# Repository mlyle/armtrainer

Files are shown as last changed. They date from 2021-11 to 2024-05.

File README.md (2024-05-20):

# ARM Trainer

This is a minimal monitor and and hardware stack for a small microcontroller trainer board, that was used to teach a Computer Organization class to students from ages 11-14.

Microprocessor trainers were a commonplace tool used to learn computing in the 1970s and early 1980s.  They replicated the console found on minicomputers, and allowed engineers to gain experience writing programs in machine code.

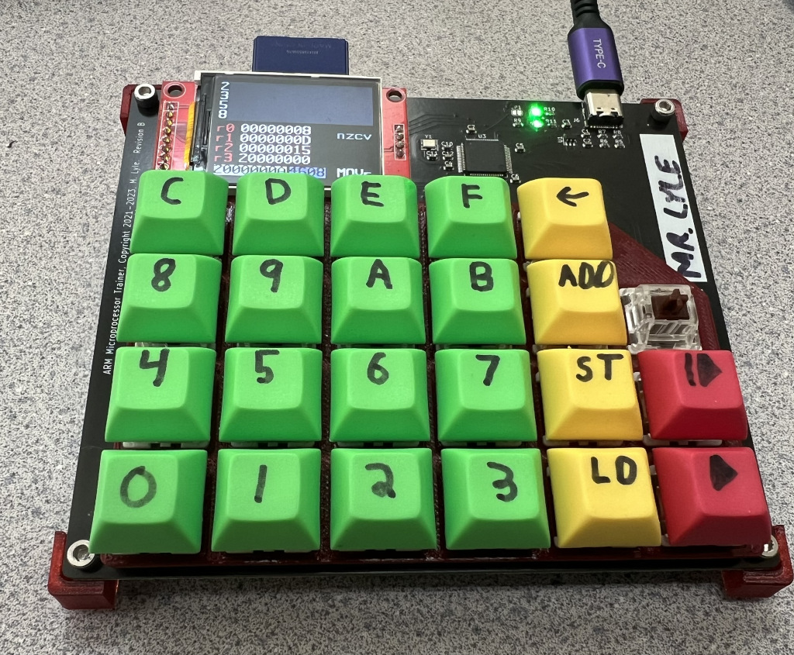
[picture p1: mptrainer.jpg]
Microprocessor Trainer


The Computer Organization class that I taught was a "how computers work" class with minimal use of conventional computers in the classroom.  We focused initially on gates, building from there to understand simple combinatorial and sequential circuits, and eventually ALUs, register files, and microprocessor subsystems.  This culminated in a study of ARM-Thumb machine code.

ARM-Thumb machine code was a fairly ideal architecture for students to learn, because:

* It is a real architecture, in real use.
* It has a reasonable number of general purpose registers.
* A fixed-length, relatively simple encoding avoids unnecessary complexity.

## Example Program

By a student, Robin K:

    20000000	DF20		(clear screen)
    20000002	2001		(mov r0, #1)
    20000004	2102		(mov r1, #1)
    20000006	180A		(add r2, r0, r1)
    20000008	DF21		(print contents of register 0)
    2000000A	4608		(mov r0, r1)
    2000000C	4611		(mov r1, r2)
    2000000E	E7FA		(b 20000006)

## TODO

* Students have complained that some invalid instructions-- BBAD, EF78-- seem to lock up the machine monitor.  I think I removed some safeguard code that I didn't think was necessary, but I need to inspect that again.
* Input calls do not allow the user to enter the number "0".
* The manual should be updated with some of the system calls that have not been documented
  * Branch calculation formulae are wrong in the manual.
  * In particular, the input calls.
  * There may be a typo in the subtract register instruction.
  * The display icon and screen coordinate system could be more clearly explained
  * Need to update manual for new key shortcuts
* Overall curriculum, etc, should get posted here.

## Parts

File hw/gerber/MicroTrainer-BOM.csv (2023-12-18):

Comment | Designator | Footprint | LCSC
2.2uF | C1,C3,C8,C9 | Capacitor_SMD:C_0603_1608Metric | C23630
12pF | C10,C11 | Capacitor_SMD:C_0603_1608Metric | C38523
0.1uF | C2,C4,C5,C6,C7,C12 | Capacitor_SMD:C_0603_1608Metric | C14663
LED | D1,D2 | LED_SMD:LED_0805_2012Metric | C2297
Fiducial | FID1,FID2,FID3 | Fiducial:Fiducial_1mm_Mask2mm
MountingHole | H1,H2,H3,H4,H5,H6,H7,H8 | MountingHole:MountingHole_3.2mm_M3
Conn_01x04 | J4 | Connector_PinSocket_2.54mm:PinSocket_1x04_P2.54mm_Vertical
Conn_01x08 | J5 | Connector_PinSocket_2.54mm:PinSocket_1x08_P2.54mm_Vertical
USB_C_Receptacle_USB2.0 | J6 | Connector_USB:USB_C_Receptacle_G-Switch_GT-USB-7010ASV | C2988369
BootJumper | JP1 | Jumper:SolderJumper-2_P1.3mm_Open_RoundedPad1.0x1.5mm
5.1k | R1,R2,R3,R4,R5,R6,R9,R12 | Resistor_SMD:R_0603_1608Metric | C23186
330 | R10,R11 | Resistor_SMD:R_0603_1608Metric | C23138
10 | R7,R8 | Resistor_SMD:R_0603_1608Metric | C22859
KEY_C | SW1 | Button_Switch_Keyboard:SW_Cherry_MX_1.00u_PCB
KEY_B | SW10 | Button_Switch_Keyboard:SW_Cherry_MX_1.00u_PCB
KEY_ADDR | SW11 | Button_Switch_Keyboard:SW_Cherry_MX_1.00u_PCB
KEY_4 | SW13 | Button_Switch_Keyboard:SW_Cherry_MX_1.00u_PCB
KEY_5 | SW14 | Button_Switch_Keyboard:SW_Cherry_MX_1.00u_PCB
KEY_6 | SW15 | Button_Switch_Keyboard:SW_Cherry_MX_1.00u_PCB
KEY_7 | SW16 | Button_Switch_Keyboard:SW_Cherry_MX_1.00u_PCB
KEY_STOR | SW17 | Button_Switch_Keyboard:SW_Cherry_MX_1.00u_PCB
KEY_STEP | SW18 | Button_Switch_Keyboard:SW_Cherry_MX_1.00u_PCB
KEY_0 | SW19 | Button_Switch_Keyboard:SW_Cherry_MX_1.00u_PCB
KEY_D | SW2 | Button_Switch_Keyboard:SW_Cherry_MX_1.00u_PCB
KEY_1 | SW20 | Button_Switch_Keyboard:SW_Cherry_MX_1.00u_PCB
KEY_2 | SW21 | Button_Switch_Keyboard:SW_Cherry_MX_1.00u_PCB
KEY_3 | SW22 | Button_Switch_Keyboard:SW_Cherry_MX_1.00u_PCB
KEY_LOAD | SW23 | Button_Switch_Keyboard:SW_Cherry_MX_1.00u_PCB
KEY_RUN | SW24 | Button_Switch_Keyboard:SW_Cherry_MX_1.00u_PCB
KEY_RST | SW25 | Button_Switch_Keyboard:SW_Cherry_MX_1.00u_PCB
KEY_E | SW3 | Button_Switch_Keyboard:SW_Cherry_MX_1.00u_PCB
KEY_F | SW4 | Button_Switch_Keyboard:SW_Cherry_MX_1.00u_PCB
KEY_CLR | SW5 | Button_Switch_Keyboard:SW_Cherry_MX_1.00u_PCB
KEY_8 | SW7 | Button_Switch_Keyboard:SW_Cherry_MX_1.00u_PCB
KEY_9 | SW8 | Button_Switch_Keyboard:SW_Cherry_MX_1.00u_PCB
KEY_A | SW9 | Button_Switch_Keyboard:SW_Cherry_MX_1.00u_PCB
LP5907MFX-3.3 | U1 | Package_TO_SOT_SMD:SOT-23-5 | C80670
STM32F412RETx | U3 | Package_QFP:LQFP-64_10x10mm_P0.5mm | C89374
25MHz | Y1 | Crystal:Crystal_SMD_3225-4Pin_3.2x2.5mm | C9006

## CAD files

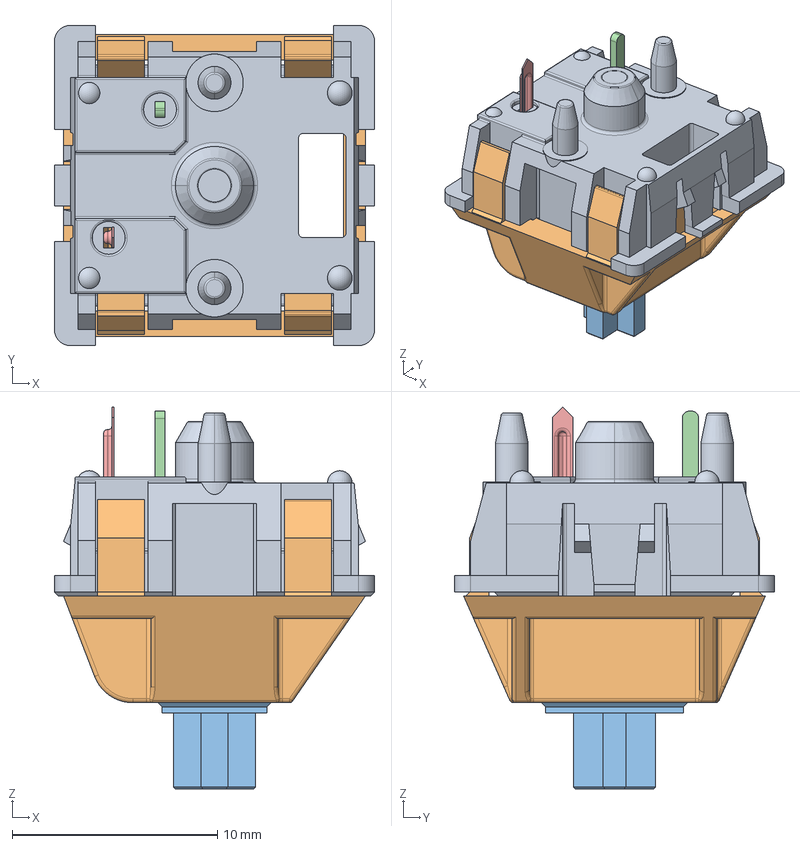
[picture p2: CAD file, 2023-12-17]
hw/3d/asm_mx_asm_PCB.stp
15.6 x 15.6 x 18.6 mm
MX_DOWN
MX_UP
UP_MX
MX_PIN
MX_SPRING
MX_CLICK

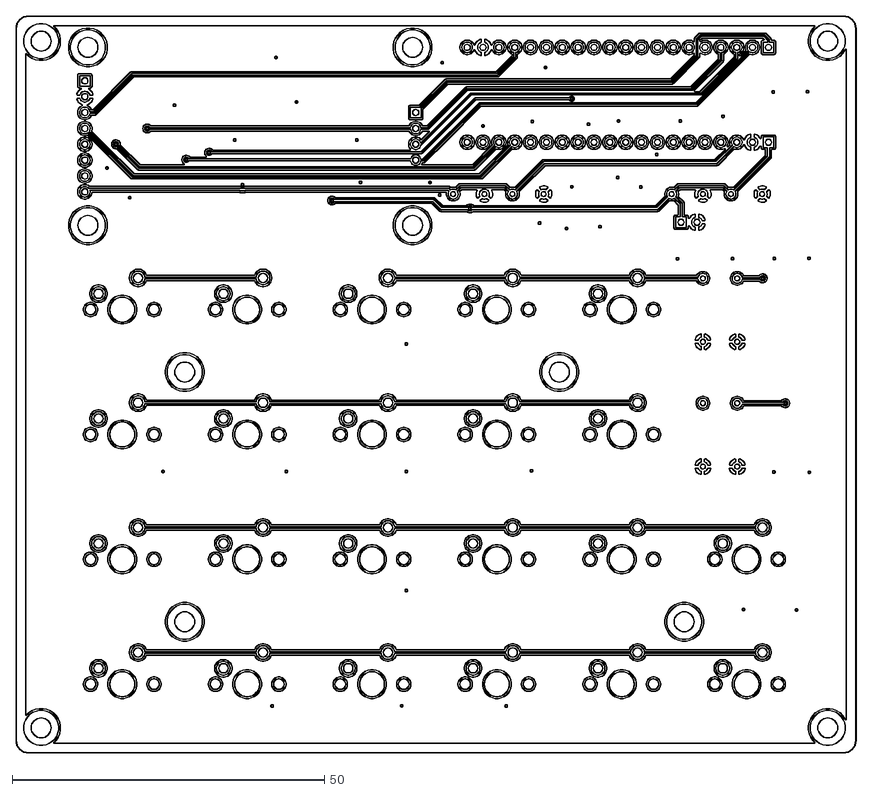
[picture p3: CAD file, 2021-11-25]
hw/microtrainer-gerbers/MicroTrainer-F_Cu.dxf
134.6 x 118.1

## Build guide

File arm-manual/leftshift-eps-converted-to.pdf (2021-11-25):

0 | 1 | 0 | 1 | 0

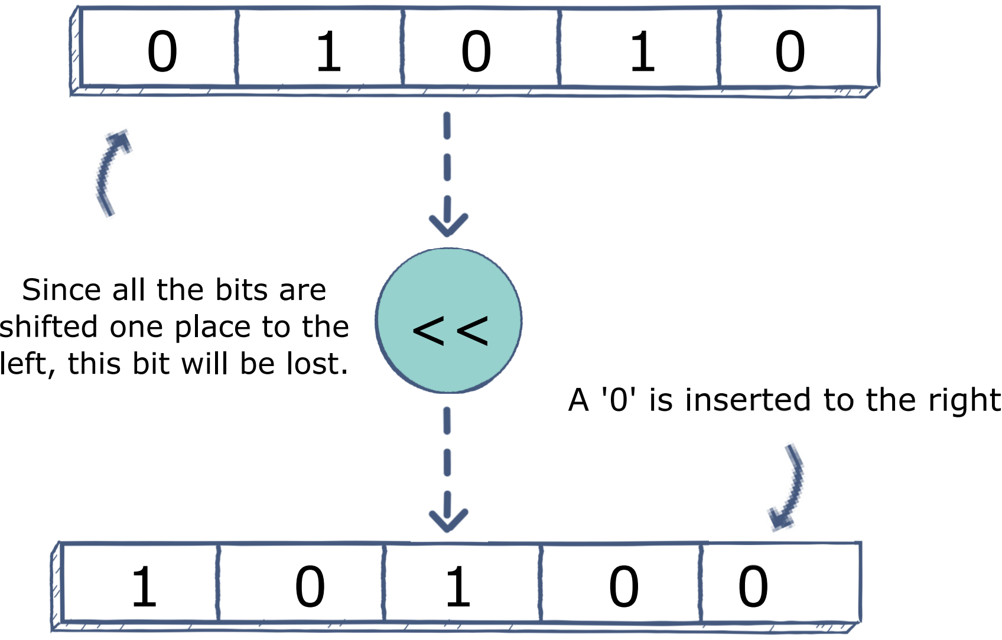
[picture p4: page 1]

<<

1 | 0 | 1 | 0 | 0

A '0' is inserted to the right

Since all the bits are
shifted one place to the
left, this bit will be lost.

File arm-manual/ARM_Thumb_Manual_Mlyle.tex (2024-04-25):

\documentclass[12pt]{article}
\usepackage[utf8]{inputenc}
\usepackage[hidelinks,linktoc=all]{hyperref}
\usepackage{graphicx}
\usepackage{tikz}
\usepackage{amsmath}

\title{ARM-Thumb Machine Code Reference}
\author{Michael Lyle}
\date{2024 Edition}

\ttfamily

\usepackage[
  letterpaper,
  twoside,
  bindingoffset=1.1cm,
  inner=1.9cm,
  outer=1.9cm,
  top=2cm,
  bottom=2cm,
  headsep=1.2cm
]{geometry}

\usepackage[final]{pdfpages}
\usepackage{graphicx}
\usepackage{imakeidx}
\makeindex

\newcommand{\fullrule}{\\[-4pt]\noindent\rule{\textwidth}{1pt}\\}

\newcommand{\instruction}[5]{\addcontentsline{toc}{subsection}{#1}\vspace{0.8cm}\noindent \textbf{#1}\index{#5}\hspace*{\fill}\texttt{#3}\fullrule#2\vspace{0.25cm}\begin{center}#4\end{center}}

\newcommand{\hexnum}[2]{$\mathtt{#1}_{16}$ ($\mathtt{#2}_{10}$)}
\newcommand{\numtt}[1]{$\mathtt{#1}$}
\newcommand{\reg}[1]{$r#1$}

\setlength{\parskip}{6pt}%
\setlength{\parindent}{0pt}

\begin{document}

\maketitle
{
\setlength{\parskip}{0pt}%
\tableofcontents
}
\vspace{3.2cm}
\begin{center}
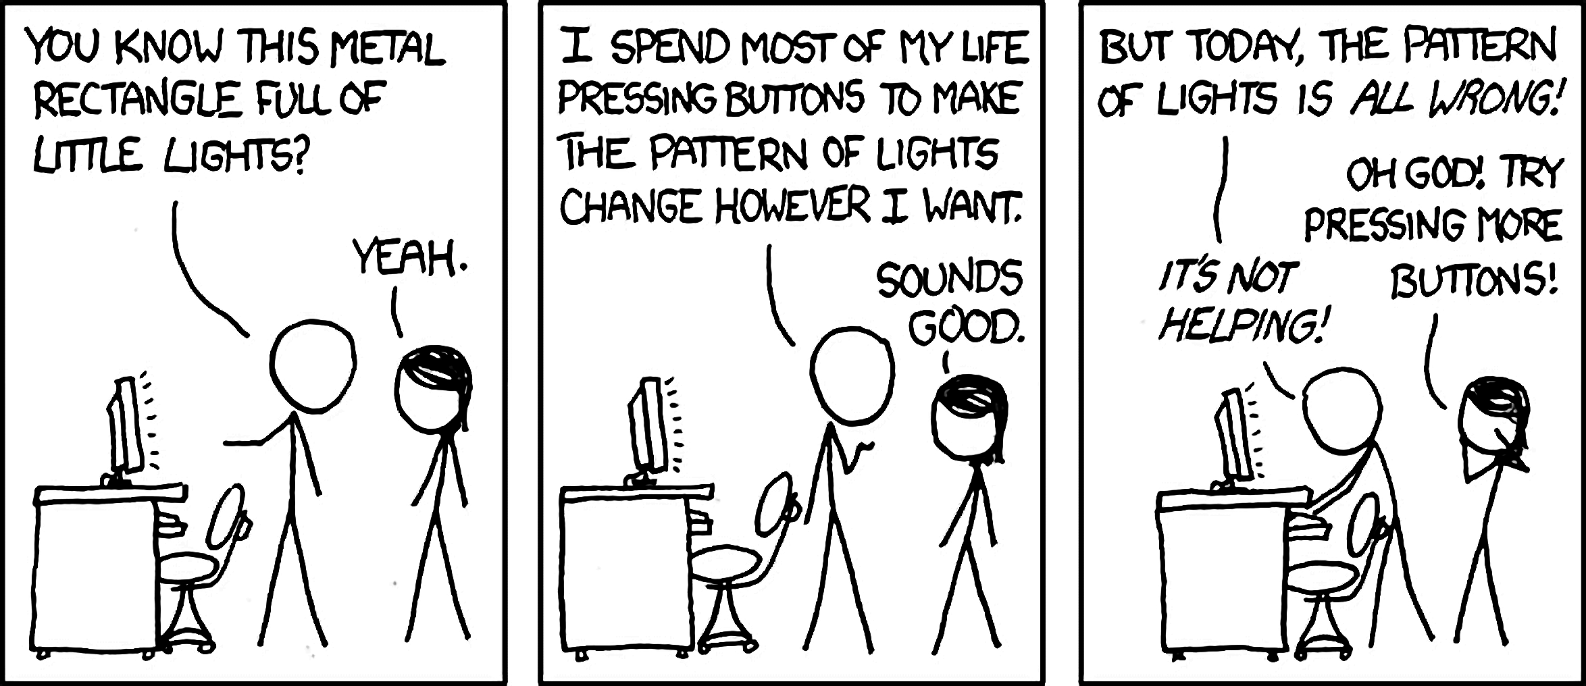
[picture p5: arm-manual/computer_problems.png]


\scriptsize{XKCD \#722, "Computer Problems" (by Randall Munroe)}
\end{center}

\newpage

\section{Architecture Summary}

In this course, we will be learning ARM Thumb machine language.

Specifically, we are writing code for the ARMv7 Thumb architecture.  Its characteristics are:

\begin{itemize}
    \item \index{registers}32-bit (4 byte) register (word) size
    \item 32-bit (4 byte) address size
    \item 16-bit (2 byte) instruction length
    \item \index{address}Addresses point to individual bytes.  Instructions and words should be aligned in memory.
    \begin{itemize}
        \item An address pointing aligned with the beginning of a word will end in $0$, $4$, $8$, or $C$ in base $16$.
        \item An address pointing to an instruction will end in $0$, $2$, $4$, $6$, $8$, $A$, $C$, or $E$ in base $16$.
    \end{itemize}
    \item Instructions can access memory, or perform arithmetic, but not both (RISC / load-store machine).
    \item Eight general-purpose registers are easily accessed (\reg{0}-\reg{7}).
    \item Five additional general-purpose registers are more difficult to access (\reg{8}-\reg{12})
    \item Three special purpose registers (stack pointer, link register, and program counter)
    \item Capable ALU with hardware multiplier and standard flags:
    \begin{itemize}
        \item N (negative),
        \item Z (zero),
        \item C (carry),
        \item and V (overflow)
    \end{itemize}
\end{itemize}

\subsection{Machine Language vs. Assembly Language}

In this course, we are writing programs in machine language.  This is a raw sequence of numbers that tells the computer what to do.

\index{assembly}
One step up from machine language is to use assembly language, where each line of code corresponds to a single machine instruction, which the assembler then translates into the binary format of machine language.  Assemblers make the process of programming slightly easier by handling the details of instruction encoding and calculating addresses for the programmer.

Most contemporary programmers work with high-level languages, such as \textit{C}, \textit{Java}, or \textit{Python}. These languages require conversion to machine code for execution. This is typically done through compilation, where the high-level code is translated into machine code, or through interpretation, where another program executes the high-level code step-by-step.

\newpage

\section{Using the ARM Microprocessor Trainer}

You will be receiving an Microprocessor Trainer in this course. Before home computers were readily available, this was one way that many people learned to program. The Trainer has a keypad where you can inspect and manipulate the contents of memory, as well as run your program.

Unlike earlier trainers, the system designed for this class uses a modern instruction set, \textbf{ARM-Thumb}, which is still actively used on microcontrollers. It is closely related to the \textbf{ARM} instruction set used in modern phones, tablets, and Apple computers.

\begin{figure}[h]
        
    \centering
    \caption{ARM Microprocessor Trainer, Revision B}
\end{figure}

If you've programmed before, this will be more cumbersome than you're used to! It's important to pre-plan your programs and think about what each instruction will do.

\subsection{Description of Keys}

\begin{itemize}
    \item \textbf{0-9, A-F}: Represent hexadecimal digits, which are used to enter numbers into the trainer.
    \item \textbf{CLR}: Functions as a backspace key, allowing you to correct any mistakes made during input.
    \item \textbf{ADDR}: Toggles the cursor between editing the memory address and the value at that address.
    \item \textbf{LOAD}: Loads the value located at the specified address into the display. Pressing this key repeatedly will advance the address sequentially, allowing you to view subsequent values.
    \item \textbf{STOR}: Saves the currently displayed value into the specified memory address, effectively writing data to memory. This will also advance the address.
    \item \textbf{STEP}: Executes the instruction at the current memory address and then automatically advances to the next address, facilitating step-by-step execution of your code.
    \item \textbf{RUN}: Starts a continuous execution of the program beginning at the current address. The execution will proceed without interruption until you press \textbf{STEP}.
\end{itemize}

\subsection{Screen Contents}
\index{screen}

The screen provides an overview of the current status of the microprocessor trainer.

\begin{figure}[h]
\begin{tikzpicture}
\newcommand*\circled[1]{\tikz[baseline=(char.base)]{
            \node[shape=circle,draw,inner sep=2pt] (char) {#1};}}
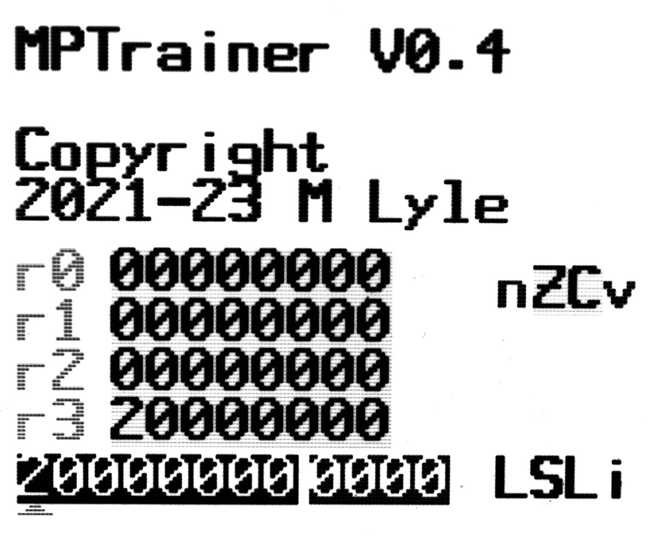
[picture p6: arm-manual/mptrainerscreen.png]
    \node[anchor=south west,inner sep=0] (image) at (0,0) {};
    \begin{scope}[
        x={(image.south east)},
        y={(image.north west)}
    ]

    \node[shape=circle,draw,fill=white,inner sep=2pt,line width=2pt] at (0.4,0.36) {\huge$1$};
    \node[shape=circle,draw,fill=white,inner sep=2pt,line width=2pt] at (0.2,0.15) {\huge$2$};
    \node[shape=circle,draw,fill=white,inner sep=2pt,line width=2pt] at (0.55,0.15) {\huge$3$};
    \node[shape=circle,draw,fill=white,inner sep=2pt,line width=2pt] at (0.75,0.38) {\huge$4$};
    \node[shape=circle,draw,fill=white,inner sep=2pt,line width=2pt] at (0.6,0.78) {\huge$5$};

    \end{scope}
\end{tikzpicture}
\centering
\caption{Screen Contents at Startup}
\end{figure}

Various types of information are displayed on the screen:

\begin{enumerate}
\item \index{registers}The values of registers are displayed centrally.
\item The current address is displayed on the left.  A red arrow indicates we are currently editing the first digit of the address.
\item The value (that may be loaded or stored) is displayed to the right of the address.
\item The current flags (produced by the ALU and used by conditional branches) are displayed on the right side of the screen.
\item At the top of the screen is where a program's input/output is displayed.
\end{enumerate}

\subsection{Entering Instructions}

Once you have written your program and translated it into hexadecimal format, you will need to enter these instructions into the Microprocessor Trainer. Follow these steps to input each instruction:

\begin{enumerate}
    \item Turn on the Microprocessor Trainer and locate the keypad.
    \item Begin by setting the starting address where your program will be stored. Enter \texttt{20000000} using the numeric keys (0-9, A-F).
    \item Press the \textbf{ADDR} key to switch the focus from entering an address to entering a value.
    \item Now, enter the first instruction from your program. Remember, each instruction should be a 4-digit hexadecimal number (consisting of the characters 0-9 and A-F).
    \item After typing the hexadecimal instruction, press the \textbf{STOR} key. This will store your instruction at the current address. The Trainer will automatically advance to the next memory address.
    \item Repeat steps 4 and 5 for each subsequent instruction in your program:
        \begin{itemize}
            \item Enter the next 4-digit hexadecimal instruction.
\index{memory!store}
            \item Press the \textbf{STOR} key to store the instruction and move to the next address.
        \end{itemize}
    \item Continue this process until you have entered all the instructions of your program.
\end{enumerate}

Make sure you enter each instruction correctly and in the proper order. If you make a mistake, you can always go back to any address by entering it and pressing \textbf{ADDR} to correct the value.

\textbf{Tip:} Always double-check each instruction after entering it to make sure it has been input correctly before hitting \textbf{STOR}. This will save you time troubleshooting later!

\paragraph{Predicting Outcomes Before Execution:}
Before running your program, take a moment to predict the expected results and behavior of your code. For example, think about what values you expect to see in registers, and when. By anticipating the values in registers and the effects of each instruction, you can better identify when things might go wrong and understand why.

\subsection{Running a Program}

Once you have successfully entered all of your program's instructions into the Microprocessor Trainer, the next step is to run your program to see how it works.

\paragraph{Setting the Starting Point:}
\index{address}
First, you need to set the Trainer to the beginning of your program. Ensure the address field is active by pressing \textbf{ADDR} if necessary. Using the keypad, enter the address \texttt{20000000}, which is where your program starts. Finally, press the \textbf{ADDR} key to confirm the start address.

\paragraph{Choosing the Mode of Execution:}
With the starting address set, you have two options for running your program:
\begin{itemize}
    \item \textbf{Step-by-Step Execution:} If you want to see how each instruction is executed one at a time, press the \textbf{STEP} key. This allows you to observe the changes and understand the flow of your program in detail. After pressing \textbf{STEP}, the Trainer executes the current instruction and then pauses, waiting for you to press \textbf{STEP} again for the next instruction.

    \item \textbf{Continuous Execution:} If you prefer to run your program continuously from the start to the end, press the \textbf{RUN} key. The Trainer will execute all the instructions continuously until the end of the program is reached, or until you press the \textbf{STEP} key to halt execution.
\end{itemize}

\paragraph{Monitoring and Troubleshooting:}
As your program runs, watch the display on the Trainer to see the outputs and any changes in the values stored in the memory. If the program does not behave as expected, you may need to stop the execution, review and correct the instructions you entered. Remember, debugging is a normal part of learning to program.
\paragraph{Tip:} Start with the step-by-step execution mode when you’re testing a new program. It gives you a better understanding of how each part of your program works and helps in identifying and fixing any errors.

\subsection{Inspecting Memory}

After you run your program, or even while it is running, you might want to check what is happening inside the memory of the Microprocessor Trainer. This process is called "inspecting memory," and it lets you see the values stored in different memory locations. Here’s how you can do it:

\paragraph{Access the Memory:}
To look at the contents of a specific memory address, you need to first stop your program if it is running. You can do this by pressing the \textbf{STEP} key to pause execution.

\paragraph{Choosing the Address:}
Use the \textbf{ADDR} key to select the address field. Enter the desired memory address using the numeric keys (0-9, A-F). Remember that your program starts at \texttt{20000000}, so any addresses from this point onward may contain data or instructions from your program.

\paragraph{Loading the Value from Memory:}
\index{memory!load}
Once you have entered the desired address, press the \textbf{LOAD} key. This will load the value at the address you entered, and switch the cursor to the value field.

\subsection{Function Keys}

The \textbf{LOAD} key on the Microprocessor Trainer is not just for loading the value at the current address. When held down and used in combination with other keys, it activates a variety of special functions. Here's how you can use these combinations effectively:

\begin{itemize}
    \item \textbf{Keys 0 - 2}: \index{registers}Display different sets of registers on the screen. Pressing \textbf{LOAD} + \textbf{0} will show registers \texttt{r0} to \texttt{r3}, which is the default display.
    \item \textbf{Keys 4 - 6}: \index{saving}Save the currently entered program into internal flash memory. Each key represents a different storage slot, allowing for multiple programs to be stored simultaneously.
    \item \textbf{Keys 8 - A}:  \index{loading} Load previously saved programs from the corresponding slots in the internal flash memory. This is useful for retrieving and running stored code without re-entering it.
    \item \textbf{Key D}: \index{decimal} Toggle the display mode of the registers between hexadecimal and decimal. This can be helpful for easier reading or specific debugging needs.
    \item \textbf{Key F}: Activate a fast run mode, which executes the program without updating the display between each instruction. This mode allows for quicker execution but is generally not recommended for debugging, as changes in registers and memory are not visible in real time.
\end{itemize}

\subsection{The Easter Egg}
\index{snake}In your explorations with the Microprocessor Trainer, there's a special feature hidden for you to discover. This hidden feature, often called an "Easter egg," can be activated under specific conditions.

\paragraph{Hint:}
If you manage to load the ASCII values for the characters 'S', 'N', 'A', and 'K' into registers \texttt{r0} through \texttt{r3} respectively, and then execute a Supervisor Call (SVC) instruction code $\texttt{45}_{16}$ (which stands for 'E' in ASCII), something unexpected will happen!

\paragraph{Discover on Your Own:}
You might want to figure out how to achieve this setup and see what happens for yourself. It’s a fun way to apply what you’ve learned about ASCII values, registers, and supervisor calls.

\newpage

\section{ARM-Thumb Basic Instructions}

The following are just a few of the many instructions in the ARM-Thumb instruction set.  There are enough instructions in this manual to be able to write any program.  In other words, this set of instructions are Turing-complete.  But other instructions, not listed here, are often necessary to write the shortest and fastest possible program.

\instruction{ADD (add immediate)}{Add an 8 bit value (included in the instruction) to a register.  Flags are updated based on the result value.}{0011 0ddd iiii iiii}{$r[d] = r[d] + i$}{add}\index{immediate instructions}
\begin{tabular}{p{0.15\textwidth} p{0.10\textwidth} p{0.63\textwidth}}
\texttt{ddd} & (3 bits) & This is the register number of the operand to add to, \underline{and} the destination register where the result should be placed. \\
\texttt{iiii iiii} & (8 bits) & This is the value that should be added, included as an immediate operand in the instruction. \\
\end {tabular}

\vspace{0.5cm}

Examples:

\begin{tabular}{p{0.33\textwidth} p{0.09\textwidth} p{0.44\textwidth}}
\texttt{0011 0ddd iiii iiii}&3???&Basic instruction encoding\\
\hline
\texttt{0011 0000 0000 0001}&3001&Adds the number \numtt{1} to \reg{0} \\
\hline
\texttt{0011 0011 0001 0010}&3312&Adds the number \hexnum{12}{18} to \reg{3} \\
\hline
\texttt{0011 0111 1010 0101}&37A5&Adds the number \hexnum{A5}{165} to \reg{7} \\
\hline

\end{tabular}

\instruction{ADD (add registers)}{Add two registers together, storing the result in a (optionally different) third register.  Flags are updated.}{0001 100m mmnn nddd}{$r[d] = r[m] + r[n]$}{add}

\begin{tabular}{p{0.15\textwidth} p{0.10\textwidth} p{0.63\textwidth}}
\texttt{mmm} & (3 bits) & This is the register number of the first operand to add. \\
\texttt{nnn} & (3 bits) & This is the register number of the second operand to add. \\
\texttt{ddd} & (3 bits) & This is the register number to store the result in. \\
\end {tabular}

\vspace{0.5cm}

Examples:

\begin{tabular}{p{0.33\textwidth} p{0.09\textwidth} p{0.44\textwidth}}
\texttt{0001 100m mmnn nddd}&1???&Basic instruction encoding\\
\hline
\texttt{0001 1000 0000 0000}&1800&Adds \reg{0} to register \reg{0} and stores the result in \reg{0} (doubles \reg{0})\\
\hline
\texttt{0001 1000 0101 0011}&1853&Adds \reg{1} to \reg{2} and stores the result in \reg{3} \\
\hline
\texttt{0001 1000 1000 1011}&188B&Adds \reg{2} to \reg{1} and stores the result in \reg{3} (same as above)\\
\hline
\end{tabular}

\newpage
\instruction{B (branch)}{Branches the program counter to a new location.  (Goto a different part of your program)}{1110 0iii iiii iiii}{$pc = pc + 2*(i+2)$}{branch}

\begin{tabular}{p{0.15\textwidth} p{0.10\textwidth} p{0.63\textwidth}}
\texttt{iiiiiiii...} & (11 bits) & Number of instructions to jump forward (or backwards, if negative...)\\
\end {tabular}

\vspace{0.5cm}

Examples:

\begin{tabular}{p{0.33\textwidth} p{0.09\textwidth} p{0.44\textwidth}}
\texttt{1110 0iii iiii iiii}&E???&Basic instruction encoding\\
\hline
\texttt{1110 0111 1111 0000}&E7F0&Goes back to 14 instructions before this one.\\
\hline
\texttt{1110 0111 1111 0001}&E7F1&Goes back to 13 instructions before this one.\\
\hline
\texttt{1110 0111 1111 0010}&E7F2&Goes back to 12 instructions before this one.\\
\hline
\texttt{1110 0111 1111 1100}&E7FC&Goes back to 2 instructions before this one.\\
\hline
\texttt{1110 0111 1111 1101}&E7FD&Goes back to 1 instructions before this one.\\
\hline
\texttt{1110 0111 1111 1110}&E7FE&Goes to \textbf{THIS} instruction (infinite loop)\\
\hline
\texttt{1110 0111 1111 1111}&E7FF&Goes to the instruction after this one (does nothing)\\
\hline
\texttt{1110 0000 0000 0000}&E000&Skips 1 instruction after this one\\
\hline
\texttt{1110 0000 0000 0001}&E001&Skips 2 instructions after this one\\
\hline
\texttt{1110 0000 0000 0010}&E002&Skips 3 instructions after this one\\
\hline
\texttt{1110 0000 0000 1111}&E00F&Skips 16 instructions after this one\\
\hline
\end{tabular}

\instruction{CMP (compare registers)}{Subtracts one register from another and updates flags.  The result of the subtraction is thrown away. }{0100 0010 10mm mnnn}{$tmp = r[n] - r[m]$}{compare}

\begin{tabular}{p{0.15\textwidth} p{0.10\textwidth} p{0.63\textwidth}}
\texttt{nnn} & (3 bits) & This is the register number of the operand to subtract from. \\
\texttt{mmm} & (3 bits) & This is the register number of the subtrahend \\
\end{tabular}
\vspace{0.5cm}

Examples:

\begin{tabular}{p{0.33\textwidth} p{0.09\textwidth} p{0.44\textwidth}}
\texttt{0100 0010 10mm mnnn}&42??&Basic instruction encoding\\
\hline
\texttt{0100 0010 1000 0001}&4281&Subtracts \reg{0} from register \reg{1} and updates flags \\
\hline
\texttt{0100 0010 1011 1110}&42BE&Subtracts \reg{7} from register \reg{6} and updates flags \\
\hline
\end{tabular}

\newpage
\instruction{MOV (move immediate)}{Moves a value, provided in the instruction, into a chosen register.}{0010 0ddd iiii iiii}{$r[d] = i$}{move}\index{immediate instructions}

\begin{tabular}{p{0.15\textwidth} p{0.10\textwidth} p{0.63\textwidth}}
\texttt{ddd} & (3 bits) & This is the register number where the result should be placed. \\
\texttt{iiii iiii} & (8 bits) & This is the value that should be placed into the destination register.  The high 24 bits of the register will be $0$ and the remaining 8 bits will be the immediate value. \\
\end {tabular}

\vspace{0.5cm}

Examples:

\begin{tabular}{p{0.33\textwidth} p{0.09\textwidth} p{0.44\textwidth}}
\texttt{0010 0ddd iiii iiii}&2???&Basic instruction encoding\\
\hline
\texttt{0010 0000 0000 0000}&2000&Sets \reg{0} to the value \numtt{0}\\
\hline
\texttt{0010 0111 1111 1111}&27FF&Sets \reg{7} to the value \hexnum{FF}{255} \\
\hline
\texttt{0010 0010 0000 0101}&2205&Puts the number \numtt{5} in \reg{2} \\
\hline

\end{tabular}

\instruction{MOV (move register)}{Copies a value from one register to another.}{0100 0110 00mm mddd}{$r[d] = r[m]$}{move}

\begin{tabular}{p{0.15\textwidth} p{0.10\textwidth} p{0.63\textwidth}}
\texttt{mmm} & (3 bits) & This is the register number from which the value should be copied. \\
\texttt{ddd} & (3 bits) & This is the register number where the value should be placed.
\end{tabular}
\vspace{0.5cm}

Examples:

\begin{tabular}{p{0.33\textwidth} p{0.09\textwidth} p{0.44\textwidth}}
\texttt{0100 0110 00mm mddd}&46??&Basic instruction encoding\\
\hline
\texttt{0100 0110 0000 1000}&4608&Sets \reg{0} to the value in \reg{1}\\
\hline
\texttt{0100 0110 0000 0001}&4601&Sets \reg{1} to the value in \reg{0}\\
\hline
\texttt{0100 0110 0011 1110}&463E&Sets \reg{6} to the value of \reg{7}\\
\hline
\end{tabular}

\newpage
\instruction{MUL (multiply registers)}{Multiplies register $n$ by register $d$, and stores the result in register $d$.}{0100 0011 01nn nddd}{$r[d] = r[d] * r[n]$}{multiply}

\begin{tabular}{p{0.15\textwidth} p{0.10\textwidth} p{0.63\textwidth}}
\texttt{nnn} & (3 bits) & This is the register number that contains the first number to be multiplied. \\
\texttt{ddd} & (3 bits) & This is the register number with the second multiplicand, and where the value should be placed.
\end{tabular}
\vspace{0.5cm}

Examples:

\begin{tabular}{p{0.33\textwidth} p{0.09\textwidth} p{0.44\textwidth}}
\texttt{0100 0011 01nn nddd}&43??&Basic instruction encoding\\
\hline
\texttt{0100 0011 0100 0000}&4340&Squares \reg{0} and puts the result back in \reg{0}\\
\hline
\texttt{0100 0011 0100 1000}&4348&Sets \reg{0} to \reg{1} times \reg{0}\\
\hline
\texttt{0100 0011 0100 0001}&4341&Sets \reg{1} to \reg{1} times \reg{0}\\
\hline
\texttt{0100 0011 0110 0011}&4363&Sets \reg{3} to \reg{3} times \reg{4}\\
\hline
\end{tabular}

\instruction{SUB (subtract immediate)}{Subtract an 8 bit value (included in the instruction) from a register.  Flags are updated based on the result value.}{0011 1ddd iiii iiii}{$r[d] = r[d] - i$}{subtract}\index{immediate instructions}

\begin{tabular}{p{0.15\textwidth} p{0.10\textwidth} p{0.63\textwidth}}
\texttt{ddd} & (3 bits) & This is the register number of the operand to subtract from, \underline{and} the destination register where the result should be placed. \\
\texttt{iiii iiii} & (8 bits) & This is the value that should be subtracted, included as an immediate operand in the instruction. \\
\end {tabular}

\vspace{0.5cm}

Examples:

\begin{tabular}{p{0.33\textwidth} p{0.09\textwidth} p{0.44\textwidth}}
\texttt{0011 1ddd iiii iiii}&3???&Basic instruction encoding\\
\hline
\texttt{0011 1000 0000 0001}&3801&Subtracts the number \numtt{1} to \reg{0} \\
\hline
\texttt{0011 1011 0011 0001}&3B32&Subtracts the number \hexnum{32}{50} from \reg{3} \\
\hline
\texttt{0011 1111 1010 0101}&3FA5&Subtracts the number \hexnum{A5}{165} from \reg{7} \\
\hline

\end{tabular}

\newpage
\instruction{SUB (subtract registers)}{Subtract one register from another, storing the result in a (optionally different) third register.  Flags are updated.}{0001 101m mmnn nddd}{$r[d] = r[n] - r[m]$}{subtract}

\begin{tabular}{p{0.15\textwidth} p{0.10\textwidth} p{0.63\textwidth}}
\texttt{nnn} & (3 bits) & This is the register number of the operand to subtract. \\
\texttt{nnn} & (3 bits) & This is the register number of the operand to subtract from. \\
\texttt{ddd} & (3 bits) & This is the register number to store the result in. \\
\end {tabular}

\vspace{0.5cm}

Examples:

\begin{tabular}{p{0.33\textwidth} p{0.09\textwidth} p{0.44\textwidth}}
\texttt{0001 101m mmnn nddd}&1???&Basic instruction encoding\\
\hline
\texttt{0001 1010 0000 0000}&1A00&Subtracts \reg{0} from register \reg{0} and stores the result in \reg{0} (sets \reg{0} to \numtt{0})\\
\hline
\texttt{0001 1010 0101 0011}&1A53&Subtracts \reg{1} from \reg{2} and stores the result in \reg{3} \\
\hline
\texttt{0001 1000 1000 1011}&1A8B&Subtracts \reg{2} from \reg{1} and stores the result in \reg{3} \\
\hline
\end{tabular}

\newpage
\section{ARM-Thumb Conditional Branches}

\instruction{BZ (branch if zero/equal)}{Branches the program counter to a new location, IF the Z flag is set.  This will branch if the result of the previous ALU operation was zero, or after using the CMP instruction on two equal values.  If the Z flag is not set, this instruction does nothing and execution continues at the next instruction.}{1101 0000 iiii iiii}{IF $Z$: $pc = pc + 2*(i+2)$}{branch!conditional}

\begin{tabular}{p{0.15\textwidth} p{0.10\textwidth} p{0.63\textwidth}}
\texttt{iiiiiiii} & (8 bits) & Number of instructions to jump forward (or backwards, if negative...)\\
\end {tabular}

\vspace{0.5cm}

Examples:

\begin{tabular}{p{0.33\textwidth} p{0.09\textwidth} p{0.44\textwidth}}
\texttt{1101 0000 iiii iiii}&D0??&Basic instruction encoding\\
\hline
\texttt{1101 0000 1111 0000}&D0F0&IF $Z$: Goes back to 14 instructions before this one.\\
\hline
\texttt{1101 0000 1111 0001}&D0F1&IF $Z$: Goes back to 13 instructions before this one.\\
\hline
\texttt{1101 0000 1111 0010}&D0F2&IF $Z$: Goes back to 12 instructions before this one.\\
\hline
\texttt{1101 0000 1111 1100}&D0FC&IF $Z$: Goes back to 2 instructions before this one.\\
\hline
\texttt{1101 0000 1111 1101}&D0FD&IF $Z$: Goes back to 1 instructions before this one.\\
\hline
\texttt{1101 0000 1111 1110}&D0FE&IF $Z$: Goes to \textbf{THIS} instruction (infinite loop if taken)\\
\hline
\texttt{1101 0000 1111 1111}&D0FF&IF $Z$: Goes to the instruction after this one (does nothing, either way)\\
\hline
\texttt{1101 0000 0000 0000}&D000&IF $Z$: Skips 1 instruction after this one\\
\hline
\texttt{1101 0000 0000 0001}&D001&IF $Z$: Skips 2 instructions after this one\\
\hline
\texttt{1101 0000 0000 0010}&D002&IF $Z$: Skips 3 instructions after this one\\
\hline
\texttt{1101 0000 0000 1111}&D00F&IF $Z$: Skips 16 instructions after this one\\
\hline
\end{tabular}

\newpage
\instruction{BNZ (branch if not zero/not equal)}{Branches the program counter to a new location, IF the Z flag is \textbf{not} set.  This will branch if the result of the previous ALU operation wasn't zero, or after using the CMP instruction on two inequal values.}{1101 0001 iiii iiii}{IF NOT $Z$: $pc = pc + 2*(i+2)$}{branch!conditional}

\begin{tabular}{p{0.15\textwidth} p{0.10\textwidth} p{0.63\textwidth}}
\texttt{iiiiiiii} & (8 bits) & Number of instructions to jump forward (or backwards, if negative...)\\
\end {tabular}

\vspace{0.5cm}

Examples:

\begin{tabular}{p{0.33\textwidth} p{0.09\textwidth} p{0.44\textwidth}}
\texttt{1101 0001 iiii iiii}&D1??&Basic instruction encoding\\
\hline
\texttt{1101 0001 1111 0000}&D1F0&IF NOT $Z$: Goes back to 14 instructions before this one.\\
\hline
\texttt{1101 0001 1111 0001}&D1F1&IF NOT $Z$: Goes back to 13 instructions before this one.\\
\hline
\texttt{1101 0001 1111 1101}&D1FD&IF NOT $Z$: Goes back to 1 instructions before this one.\\
\hline
\texttt{1101 0001 1111 1111}&D1FF&IF NOT $Z$: Goes to the instruction after this one (does nothing, either way)\\
\hline
\texttt{1101 0001 0000 0000}&D100&IF NOT $Z$: Skips 1 instruction after this one\\
\hline
\texttt{1101 0001 0000 0001}&D101&IF NOT $Z$: Skips 2 instructions after this one\\
\hline
\end{tabular}

\newpage
\instruction{BMI (branch if negative)}{Branches the program counter to a new location, IF the if the result of the previous ALU operation was less than zero, or after using the CMP instruction where the comparand is larger than the other value.}{1101 0100 iiii iiii}{IF $N$: $pc = pc + 2*(i+2)$}{branch!conditional}

\begin{tabular}{p{0.15\textwidth} p{0.10\textwidth} p{0.63\textwidth}}
\texttt{iiiiiiii} & (8 bits) & Number of instructions to jump forward (or backwards, if negative...)\\
\end {tabular}

\vspace{0.5cm}

Examples:

\begin{tabular}{p{0.33\textwidth} p{0.09\textwidth} p{0.44\textwidth}}
\texttt{1101 0100 iiii iiii}&D4??&Basic instruction encoding\\
\hline
\texttt{1101 0100 1111 0000}&D4F0&IF $N$: Goes back to 14 instructions before this one.\\
\hline
\texttt{1101 0100 1111 1101}&D4FD&IF $N$: Goes back to 1 instructions before this one.\\
\hline
\texttt{1101 0100 1111 1111}&D4FF&IF $N$: Goes to the instruction after this one (does nothing)\\
\hline
\texttt{1101 0100 0000 0000}&D400&IF $N$: Skips 1 instruction after this one\\
\hline
\end{tabular}

\vspace{3cm}

There are more conditional branches.  You can find information on how they are encoded in sections \ref{encodings} and \ref{condcodes}.

\newpage
\section{ARM-Thumb Miscellaneous Instructions}

\instruction{LSL (logical shift left, immediate)}{Shifts register $n$ left by a fixed number of bits, and stores the result in register $d$.}{0000 0iii iimm mddd}{$r[d] = r[m] << immediate$}{logical!shift}

\begin{tabular}{p{0.15\textwidth} p{0.10\textwidth} p{0.63\textwidth}}
\texttt{iiiii} & (5 bits) & \index{immediate instructions}This is the number of bits to shift the number left. \\
\texttt{mmm} & (3 bits) & This is the register number that contains the number to be shifted. \\
\texttt{ddd} & (3 bits) & This is the register number to store the result in.
\end{tabular}
\vspace{0.5cm}

Examples:

\begin{tabular}{p{0.33\textwidth} p{0.09\textwidth} p{0.44\textwidth}}
\texttt{0000 0iii iimm mddd}&0???&Basic instruction encoding\\
\hline
\texttt{0000 0000 0100 0000}&0040&Shifts \reg{0} one bit left (doubling it) and puts the result back in \reg{0}\\
\hline
\texttt{0000 0010 0010 0111}&0227&Shifts \reg{4} eight bits left (multiplying by 256) and puts the result in \reg{7}\\ 
\hline
\end{tabular}

\instruction{ORR (logical or, register)}{Computes the logical or operation of registers $m$ and $d$, and stores the result back in register $d$.}{0100 0011 00mm mddd}{$r[d] = r[m]$ logical-or $r[d]$}{logical!or}

\begin{tabular}{p{0.15\textwidth} p{0.10\textwidth} p{0.63\textwidth}}
\texttt{mmm} & (3 bits) & This is the register number that contains the first operand for logical-or. \\
\texttt{ddd} & (3 bits) & This is the register number that contains the second operand for logical-or, and the destination register to store the result within. \\
\end{tabular}
\vspace{0.5cm}

Examples:

\begin{tabular}{p{0.33\textwidth} p{0.09\textwidth} p{0.44\textwidth}}
\texttt{0100 0011 00mm mddd}&43??&Basic instruction encoding\\
\hline
\texttt{0100 0011 0000 1000}&4308&Ors \reg{1} with \reg{0} and stores the result in \reg{0}\\
\hline
\texttt{0100 0011 0010 1110}&432E&Ors \reg{5} with \reg{6} and stores the result in \reg{6}\\ 
\hline
\end{tabular}

\newpage
\instruction{AND (logical and, register)}{Computes the logical and operation of registers $m$ and $d$, and puts the result back in register $d$.}{0100 0000 00mm mddd}{$r[d] = r[m]$ logical-and $r[d]$}{logical!and}

\begin{tabular}{p{0.15\textwidth} p{0.10\textwidth} p{0.63\textwidth}}
\texttt{mmm} & (3 bits) & This is the register number that contains the first operand for logical-and. \\
\texttt{ddd} & (3 bits) & This is the register number that contains the second operand for logical-and, and the destination register to put the result within. \\
\end{tabular}
\vspace{0.5cm}

Examples:

\begin{tabular}{p{0.33\textwidth} p{0.09\textwidth} p{0.44\textwidth}}
\texttt{0100 0000 00mm mddd}&40??&Basic instruction encoding\\
\hline
\texttt{0100 0000 0000 1000}&4008&Ands \reg{1} with \reg{0} and stores the result in \reg{0}\\
\hline
\texttt{0100 0000 0010 1110}&402E&Ands \reg{5} with \reg{6} and stores the result in \reg{6}\\ 
\hline
\end{tabular}

\instruction{LDR (load register)}{Retrieves the word at the memory address formed from the sum of registers $m$ and $n$, and puts the result in register $t$.}{0101 100m mmnn nttt}{$r[t] = memory(r[m] + r[n])$}{memory!load}

\begin{tabular}{p{0.15\textwidth} p{0.10\textwidth} p{0.63\textwidth}}
\texttt{mmm} & (3 bits) & This is the first register that is combined to form the memory address. \\
\texttt{nnn} & (3 bits) & This is the second register that is combined to form the memory address. \\
\texttt{ttt} & (3 bits) & This is the target, where the word retrieved from memory is placed. \\
\end{tabular}
\vspace{0.5cm}

Examples:

\begin{tabular}{p{0.33\textwidth} p{0.09\textwidth} p{0.44\textwidth}}
\texttt{0101 100m mmnn nttt}&5???&Basic instruction encoding\\
\hline
\texttt{0101 1001 1100 0001}&59C1&Loads the value from address \reg{7} $+$ \reg{0} into \reg{1} \\
\hline
\end{tabular}

\newpage
\index{address}
\instruction{STR (store register)}{Forms a memory address by adding registers $m$ and $n$, and stores the contents of register $t$ at that location.}{0101 000m mmnn nttt}{$memory(r[m] + r[n]) = r[t]$}{memory!store}

\begin{tabular}{p{0.15\textwidth} p{0.10\textwidth} p{0.63\textwidth}}
\texttt{mmm} & (3 bits) & This is the first register that is combined to form the memory address. \\
\texttt{nnn} & (3 bits) & This is the second register that is combined to form the memory address. \\
\texttt{ttt} & (3 bits) & The contents of this register are stored to the chosen location in memory. \\
\end{tabular}
\vspace{0.5cm}

Examples:

\begin{tabular}{p{0.33\textwidth} p{0.09\textwidth} p{0.44\textwidth}}
\texttt{0101 000m mmnn nttt}&5???&Basic instruction encoding\\
\hline
\texttt{0101 0001 1100 0001}&51C1&Stores the value in \reg{1} to the  address \reg{7} $+$ \reg{0} \\
\hline
\end{tabular}

\newpage
\subsection{Logical Shifting (Illustrated)}

\begin{center}

\end{center}

\subsection{Putting a Large Value in a Register}

\index{address}
\index{memory!load}
\index{logical!shift}
\index{logical!or}
\index{move}
Often, it will be desirable to put a number larger than we can have in a single immediate into a register.  The immediate move instruction available to us only can place an $8$ bit value in a register, but registers are $32$ bits wide.

There are many ways to accomplish this, including using load instructions.  However, it can be complicated to calculate addresses.  Below is a simple method to place the value $12345678_{16}$ into \reg{0}, while using \reg{1} as a temporary space.

\renewcommand{\arraystretch}{1.5}
\begin{tabular}{p{0.1\textwidth} p{0.2\textwidth} p{0.6\textwidth}}

\texttt{20\underline{12}} & \texttt{MOV \reg{0}, $12_{16}$}&
Places the value $12_{16}$ into \reg{0}.\\

\texttt{0200} & \texttt{LSL \reg{0}, \reg{0}, \#8 }&
Shifts \reg{0} left 8 bits; it now contains $1200_{16}$.\\

\texttt{21\underline{34}} & \texttt{MOV \reg{1}, $34_{16}$}&
Puts $34_{16}$ into \reg{1}.\\

\texttt{4309} & \texttt{ORR \reg{0}, \reg{1}}&
Logical OR of \reg{0} and \reg{1}, putting the result in \reg{0}, which now contains $1234_{16}$.\\

\texttt{0200} & \texttt{LSL \reg{0}, \reg{0}, \#8 }&
Shifts \reg{0} left 8 bits; it now contains $123400_{16}$.\\

\texttt{21\underline{56}} & \texttt{MOV \reg{1}, $56_{16}$}&
Puts $56_{16}$ into \reg{1}.\\

\texttt{4309} & \texttt{ORR \reg{0}, \reg{1}}&
Logical OR of \reg{0} and \reg{1}, putting the result in \reg{0}, which now contains $123456_{16}$.\\

\texttt{0200} & \texttt{LSL \reg{0}, \reg{0}, \#8}&
Shifts register 0 left 8 bits; it now contains $12345600_{16}$.\\

\texttt{21\underline{78}} & \texttt{MOV \reg{1}, $78_{16}$}&
Puts $78_{16}$ into \reg{1}.\\

\texttt{4309} & \texttt{ORR \reg{0}, \reg{1}}&
Logical OR of \reg{0} and \reg{1}, putting the result in \reg{0}, which now contains $12345678_{16}$!\\
\end{tabular}
\renewcommand{\arraystretch}{1}

\vspace{0.5cm}
In this way, we can put large numbers into any of our registers.  This approach isn't terribly efficient: 10 instructions and 20 bytes are used to load a 4 byte word into a register, but it is simple and it works.

\newpage
\section{Special (SuperVisor Call) Instructions}

\index{supervisor call (SVC)}
Supervisor Call (SVC) instructions are special system-level operations that provide input/output (I/O) functionality and other system utilities. These instructions have been specifically configured for the computing environment used in this course.

Many of these expect for an appropriate value to be loaded to $r0$ (or other registers) before executing them.

\instruction{SVC00 (toggle LED)}{If the LED is off, this turns it on.  Otherwise, it turns the LED off.}{1101 1111 0000 0000}{}{LED}

\begin{tabular}{p{0.33\textwidth} p{0.09\textwidth} p{0.44\textwidth}}
\texttt{1101 1111 0000 0000}&DF00&Basic instruction encoding\\
\end{tabular}

\instruction{SVC01 (turn LED off)}{Turns the LED off.}{1101 1111 0000 0001}{}{LED}

\begin{tabular}{p{0.33\textwidth} p{0.09\textwidth} p{0.44\textwidth}}
\texttt{1101 1111 0000 0001}&DF01&Basic instruction encoding\\
\end{tabular}

\instruction{SVC02 (turn LED on)}{Turns the LED on.}{1101 1111 0000 0010}{}{LED}

\begin{tabular}{p{0.33\textwidth} p{0.09\textwidth} p{0.44\textwidth}}
\texttt{1101 1111 0000 0010}&DF02&Basic instruction encoding\\
\end{tabular}

\instruction{SVC03 (blink the LED)}{This slowly blinks the LED.  The value in $r0$ determines how many times the LED blinks.}{1101 1111 0000 0011}{}{LED}

\begin{tabular}{p{0.33\textwidth} p{0.09\textwidth} p{0.44\textwidth}}
\texttt{1101 1111 0000 0011}&DF03&Basic instruction encoding\\
\end{tabular}

\newpage

\instruction{SVC11 (sleep, tenths)}{This freezes the program for a short amount of time.  The length of time, in tenths of a second, is specified in $r0$.  For instance, if $r0$ is $15$, this will wait $1.5$ seconds before the program resumes running.}{1101 1111 0001 0001}{}{delay}

\begin{tabular}{p{0.33\textwidth} p{0.09\textwidth} p{0.44\textwidth}}
\texttt{1101 1111 0001 0001}&DF11&Basic instruction encoding\\
\end{tabular}

\instruction{SVC12 (sleep, seconds)}{This freezes the program for a short amount of time.  The length of time, in seconds, is specified in $r0$.  For instance, if $r0$ is $15$, this will wait $15$ seconds before the program resumes running.}{1101 1111 0001 0010}{}{delay}

\begin{tabular}{p{0.33\textwidth} p{0.09\textwidth} p{0.44\textwidth}}
\texttt{1101 1111 0001 0010}&DF12&Basic instruction encoding\\
\end{tabular}

\instruction{SVC20 (clear screen)}{This clears the top half of screen and positions the cursor to write out text at the upper left.}{1101 1111 0010 0000}{}{screen}

\begin{tabular}{p{0.33\textwidth} p{0.09\textwidth} p{0.44\textwidth}}
\texttt{1101 1111 0010 0010}&DF20&Basic instruction encoding\\
\end{tabular}

\instruction{SVC21 (output number, denary)}{This prints the number in $r0$ on the screen, as a base 10 (denary) number.  For instance, if $r0$ is $F_{16}$ (or $15_{10}$), this will write the number $15$ on the screen.}{1101 1111 0010 0001}{}{screen}

\begin{tabular}{p{0.33\textwidth} p{0.09\textwidth} p{0.44\textwidth}}
\texttt{1101 1111 0010 0001}&DF21&Basic instruction encoding\\
\end{tabular}

\newpage

\instruction{SVC22 (output number, hex)}{This prints the number in $r0$ on the screen, as a base 16 (hexadecimal) number.  For instance, if $r0$ is $F_{16}$ (or $15_{10}$), this will write $F$ on the screen.}{1101 1111 0010 0010}{}{screen}

\begin{tabular}{p{0.33\textwidth} p{0.09\textwidth} p{0.44\textwidth}}
\texttt{1101 1111 0010 0010}&DF22&Basic instruction encoding\\
\end{tabular}

\instruction{SVC23 (output ASCII character)}{This prints the character in $r0$ on the screen.  Only the last 8 bits of $r0$ are used.  For instance, if $r0$ is $4D_{16}$ (or $77_{10}$), this will write the character 'M' on the screen.  See the ASCII chart later in this guide for reference.}{1101 1111 0010 0011}{}{screen}

\index{ASCII}
\begin{tabular}{p{0.33\textwidth} p{0.09\textwidth} p{0.44\textwidth}}
\texttt{1101 1111 0010 0011}&DF23&Basic instruction encoding\\
\end{tabular}

\newpage
\instruction{SVC24 (draw dot)}{This changes the color of one pixel on the screen.  The color to put in the pixel is stored as an 8 bit value in $r0$.  The coordinates to change are ($r1$, $r2$).}{1101 1111 0010 0100}{}{screen}

\begin{tabular}{p{0.33\textwidth} p{0.09\textwidth} p{0.44\textwidth}}
\texttt{1101 1111 0010 0100}&DF24&Basic instruction encoding\\
\end{tabular}

\index{screen}
\instruction{SVC25 (draw icon)}{This draws a 32 byte (16 halfword) icon  on the screen.  The icon is expected to immediately follow this instruction, and when the draw is complete the instruction pointer will be increased by $22_{16}$ to skip the icon data.  The color to draw the icon is stored as an 8 bit value in $r0$. The coordinates to draw the icon at are ($r1$, $r2$).}{1101 1111 0010 0101}{}{screen}

\index{icon}

\begin{tabular}{p{0.33\textwidth} p{0.09\textwidth} p{0.44\textwidth}}
\texttt{1101 1111 0010 0101}&DF25&Basic instruction encoding (32 bytes of icon data follow)\\
\end{tabular}

\index{colors}
\subsection{Screen Colors (8-bit)}

\textbf{SVC25} and \textbf{SVC24} take in \reg{0} an 8-bit color value.  This color value is formatted in the bit pattern \texttt{RRGG GBBB}, where \texttt{RR} is a two-bit value indicating the intensity of the color red, \texttt{GGG} is a three-bit value indicating the intensity of green, and \texttt{BBB} is a three-bit value indicating the intensity of the color blue.

For instance, if it's desired to draw an icon with the color purple, that requires bright red and bright blue, with no green.  Therefore, we will use the color \texttt{1100 0111} for full intensity red, no green, and full intensity blue.  This becomes the value $C7_{16}$ which can be placed into \reg{0} with the instruction \texttt{MOV R0, C7} encoded as \texttt{20C7}.

\subsection{Screen Coordinates}

Screen drawing routines also take in coordinates in (\reg{1}, \reg{2}).  Unlike graphing coordinates, as $y$ gets bigger this moves down the screen.  The upper left corner of the screen is at ($0$, $0$).  The upper right of the screen is at ($160$, $0$).  The lowest row that you should use on the screen is row $53$. Therefore, the bottom left and right corners of the screen are positioned at ($0$, $53$) and ($160$, $53$), respectively.

\section{Miscellaneous Reference}
\subsection{ASCII Character Map}
\index{ASCII}
\begin{center}
\input{ascii.tex}
\small{(modified by Michael Lyle, 2021)}
\end{center}

\newpage
\subsection{ARM Thumb Instruction Encoding}
\index{instruction encodings}
\label{encodings}
\vspace{0.5cm}

Source: DDI0210, Arm Limited, 2004

\newpage
\subsubsection{CondCodes and Suffixes for Conditional Branches}
\label{condcodes}
\index{condition codes}

Source: DDI0084D, Arm Limited, 1998

\newpage
\subsection{Hexadecimal and Decimal Conversion (Nybbles)}
\index{nybble}
\begin{table}[h]
\centering
\begin{minipage}[t]{0.48\textwidth}
\centering
\begin{tabular}{ccc}
\index{decimal}Decimal & \index{binary}Binary & \index{hexadecimal}Hexadecimal\\
\hline
$0$ & \texttt{0000} & $0$\\
$1$ & \texttt{0001} & $1$\\
$2$ & \texttt{0010} & $2$\\
$3$ & \texttt{0011} & $3$\\
$4$ & \texttt{0100} & $4$\\
$5$ & \texttt{0101} & $5$\\
$6$ & \texttt{0110} & $6$\\
$7$ & \texttt{0111} & $7$\\
\end{tabular}
\end{minipage}%
\hfill
\begin{minipage}[t]{0.48\textwidth}
\centering
\begin{tabular}{ccc}
\index{decimal}Decimal & \index{binary}Binary & \index{hexadecimal}Hexadecimal\\
\hline
$8$ & \texttt{1000} & $8$\\
$9$ & \texttt{1001} & $9$\\
$10$ & \texttt{1010} & $A$\\
$11$ & \texttt{1011} & $B$\\
$12$ & \texttt{1100} & $C$\\
$13$ & \texttt{1101} & $D$\\
$14$ & \texttt{1110} & $E$\\
$15$ & \texttt{1111} & $F$\\
\end{tabular}
\end{minipage}
\end{table}

\index{branch!offsets}
\subsection{Branch Offsets (as used in B, BNZ, etc.)}
\begin{tabular}{p{0.30\textwidth} p{0.12\textwidth} p{0.23\textwidth} p{0.18\textwidth}}
Number of Instructions & Address Offset & 8 Bit Conditional Branch Offset & 11 Bit Branch Offset\\
\hline
Back 30 & $-3C_{16}$ & $E0_{16}$ & $7E0_{16}$ \\
Back 29 & $-3A_{16}$ & $E1_{16}$ & $7E1_{16}$ \\
...\\
Back 16 & $-20_{16}$ & $EE_{16}$ & $7EE_{16}$ \\
Back 15 & $-1E_{16}$ & $EF_{16}$ & $7EF_{16}$ \\
Back 14 & $-1C_{16}$ & $F0_{16}$ & $7F0_{16}$ \\
Back 13 & $-1A_{16}$ & $F1_{16}$ & $7F1_{16}$ \\
Back 12 & $-18_{16}$ & $F2_{16}$ & $7F2_{16}$ \\
...\\
Back 2 & $-4_{16}$ & $FC_{16}$ & $7FC_{16}$ \\
Back 1 & $-2_{16}$ & $FD_{16}$ & $7FD_{16}$ \\
Infinite Loop & $0$ & $FE_{16}$ & $7FE_{16}$ \\
Forward 1 (Do Nothing) & $+2_{16}$ & $FF_{16}$ & $7FF_{16}$ \\
Forward 2 (Skip 1) & $+4_{16}$ & $00_{16}$ & $000_{16}$ \\
Forward 3 (Skip 2) & $+6_{16}$ & $01_{16}$ & $001_{16}$ \\
...\\
Forward 15 (Skip 14) & $+1E_{16}$ & $0E_{16}$ & $00E_{16}$ \\
Forward 16 (Skip 15) & $+20_{16}$ & $0F_{16}$ & $00F_{16}$ \\
Forward 17 (Skip 16) & $+22_{16}$ & $10_{16}$ & $010_{16}$ \\
Forward 18 (Skip 17) & $+24_{16}$ & $11_{16}$ & $011_{16}$
\end{tabular}

\paragraph{General Equation for Branch Calculation:}
\( \text{Offset} = \frac{\text{Target} - \text{CurAddr}}{2} + 2 \)

\paragraph{Backwards Unconditional Branches:}
\( \text{Offset} = 800_{16} + \frac{\text{Target} - \text{CurAddr}}{2} - 2 \)

\paragraph{Backwards 8-bit Conditional Branches:}
\( \text{Offset} = 100_{16} + \frac{\text{Target} - \text{CurAddr}}{2} - 2 \)

\newpage
\addcontentsline{toc}{subsection}{ARM Thumb-16 Quick Reference Card}
\index{add}
\index{move}
\index{subtract}
\includepdf[angle=90,pages=1,pagecommand={},width=7.65in, offset=0.25in 0]{ThumbRefCard.pdf}
\index{memory!load}
\index{address}
\index{memory!store}
\index{branch}
\index{logical!and}
\index{logical!or}
\index{logical!shift}
\includepdf[angle=90,pages=2,pagecommand={},width=7.65in, offset=0.25in 0]{ThumbRefCard.pdf}
\index{supervisor call (SVC)}
\includepdf[angle=90,pages=3,pagecommand={},width=7.65in, offset=0.25in 0]{ThumbRefCard.pdf}

\addcontentsline{toc}{subsection}{CO\&D Program Form}
\includepdf[pages=1]{Program_Form.pdf}
\includepdf[pages=2]{Program_Form.pdf}
\addcontentsline{toc}{subsection}{CO\&D Execution Trace}
\includepdf[pages=3]{Program_Form.pdf}

\printindex

\vspace{0.5cm}
ARM-Thumb Machine Code Reference by Michael Lyle is licensed under Creative Commons Attribution 4.0 International. To view a copy of this license, visit \\
https://creativecommons.org/licenses/by/4.0/

\vspace{0.5cm}
The Thumb Quick Reference Card, and the instruction encoding information from DDI0210 and DDI0084D, copyright ARM Holdings.  The ASCII reference sheet is by Victor Eijkhout. The XKCD comic is by Randall Munroe.  The below comic, Captain Zilog, is from Zilog Corporation.  All rights for these documents remain with their respective authors.

\vspace{0.1cm}

\begin{figure}[h]
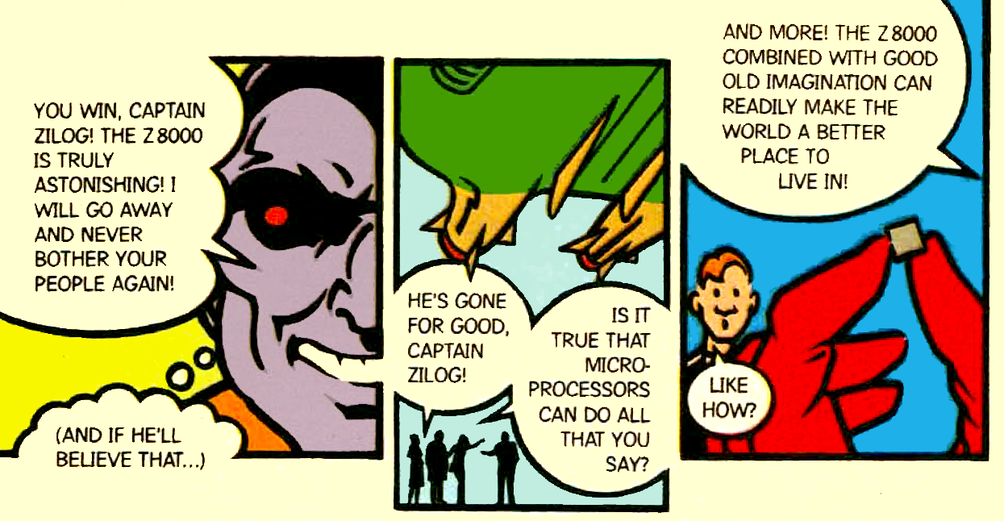
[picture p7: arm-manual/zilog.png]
        
    \centering
    \caption{From \textit{Captain Zilog}, 1979, Zilog, Inc.}
\end{figure}

\end{document}

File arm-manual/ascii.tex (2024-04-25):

%%%%%%%%%%%%%%%%%%%%%%%%%%%%%%%%%%%%%%%%%%%%%%%%%%%%%%%%%%%%%%%%%%%%%%%%
%%                                                                    %%
%%                     A S C I I    wall chart                        %%
%%                                                                    %%
%% by Victor Eijkhout                                                 %%
%% victor@eijkhout.net                                                %%
%%                                                                    %%
%%%%%%%%%%%%%%%%%%%%%%%%%%%%%%%%%%%%%%%%%%%%%%%%%%%%%%%%%%%%%%%%%%%%%%%%
%% Copyright 2009 Victor Eijkhout
%
% This work may be distributed and/or modified under the
% conditions of the LaTeX Project Public License, either version 1.3
% of this license or (at your option) any later version.
% The latest version of this license is in
%   http://www.latex-project.org/lppl.txt
% and version 1.3 or later is part of all distributions of LaTeX
% version 2005/12/01 or later.
%
% This work has the LPPL maintenance status `maintained'.
% 
% The Current Maintainer of this work is Victor Eijkhout.
%
% This work consists of this file.
%
%% Choose your favourite format:
%
%\nopagenumbers %% 2 lines
%\vsize=28cm    %% for PLAIN TeX
%\documentstyle{article}            %% 4 lines for LaTeX
%\begin{document}                   %% not that it matters anything,
%\pagestyle{empty}                  %% rest of the document
%\setlength{\textheight}{28cm}      %% is 'pure' TeX.
%%%%%% and don't forget the \bye / \end{document} at the end!! %%%%%%%
%% fonts
\font\bitfont=cmr10 \fontdimen4\bitfont=3mm
\font\codefont=cmr7
\font\namefont=cmss10 scaled 1200
\font\titlefont=cmss10 scaled 1440
\font\commentfont=cmss10
%% counts and dimens
\newdimen\thinlinewidth \thinlinewidth=.25mm
\newdimen\fatlinewidth \fatlinewidth=.5mm
\newdimen\rowheight \rowheight=0.95cm
\newdimen\colwidth  \colwidth=1.6cm
\newdimen\Colwidth \Colwidth=2\colwidth
  \advance\Colwidth by \thinlinewidth
\newdimen\topwhite \topwhite=2pt
\newdimen\botwhite \botwhite=3pt
\newdimen\leftwhite \leftwhite=2pt
\newdimen\rightwhite \rightwhite=2pt
\newcount\rowcount \rowcount=-1 %% note!
\newcount\colcount \colcount=0
\newcount\thenumber
%% tidbits
\def\\{$\backslash$}
\def\thinline{\vrule width \thinlinewidth}
\def\fatline{\vrule width \fatlinewidth}
\tolerance=10000
\vbadness=10000
%% code conversion
\def\calcnumber{{\multiply\colcount by 16
                 \advance\colcount by \rowcount
                 \global\thenumber=\colcount}}
\def\deccode{\number\thenumber}
\def\octcode{{\ifnum\thenumber>63
                            \advance\thenumber by -64
                            \count0=\thenumber \divide\count0 by 8
                            1\number\count0
              \else         \count0=\thenumber \divide\count0 by 8
                            \ifnum\count0>0 \number\count0 \fi\fi
              \multiply\count0 by 8
              \advance\thenumber by -\count0
              \number\thenumber}}
\def\hexdigit#1{\ifcase#1 0\or 1\or 2\or 3\or 4\or 5\or 6\or 7\or
                          8\or 9\or A\or B\or C\or D\or E\or F\or
                          \edef\tmp{\message{illegal hex digit
                                        \number#1}}\tmp
                          \fi}
\def\hexcode{{\count0=\thenumber \divide\count0 by 16
              \ifnum\count0>0 \hexdigit{\count0}\fi
              \multiply\count0 by 16
              \advance\thenumber by -\count0 \count0=\thenumber
              \hexdigit{\count0}}}
%% the heading
\def\threebit#1#2#3{\vbox to 1.5\rowheight{\bitfont
                      \vskip\topwhite
                      \hbox to \colwidth{\hskip\leftwhite#1\hfil}
                      \vfil
                      \hbox to \colwidth{\hfil#2\hfil}
                      \vfil
                      \hbox to \colwidth{\hfil#3\hskip\rightwhite}
                      \vskip\botwhite}}
\def\comment#1{\vbox to \colwidth{\hrule height 0mm depth .25mm
                      \vfil
                      \hbox to \Colwidth{\commentfont\hfil#1\hfil}
                      \vfil}}
\def\dcomment#1#2{\vbox to \colwidth{\hrule height 0mm depth .25mm
                      \vfil
                      \hbox to \Colwidth{\commentfont\hfil#1\hfil}
                      \vskip \botwhite
                      \hbox to \Colwidth{\commentfont\hfil#2\hfil}
                      \vfil}}
\def\bithead{\vbox to \colwidth{\hsize=1.5\colwidth
                   \vskip\topwhite
                   \hbox to \hsize{\commentfont\hfil BITS\hfil}
                   \vfil
                   \hbox to \hsize{\bitfont\ b4 b3 b2 b1 }
                   \vskip\botwhite}}
%% routines for single chars
\def\fourbit#1\fb{\vbox to \rowheight{
                     \vfil
                     \hbox to 1.5\colwidth{\bitfont #1\ }
                     \vfil}%
                  \global\advance\rowcount by 1
                  \global\colcount=0}
\def\asc#1\ii{\calcnumber
              \vbox to \rowheight{\offinterlineskip
                     \vskip\topwhite
                     \hbox to \colwidth{\codefont
                                        \hskip\leftwhite
                                        \deccode\hfil}
                     \vfil
                     \hbox to \colwidth{\vrule width 0cm
                                              height 10pt depth 2pt
                                        \namefont
                                        \hfil#1\hfil}
                     \vfil
                     \hbox to \colwidth{\codefont
                                        \hskip\leftwhite
                                        \hexcode\hfil %\octcode
                                        \hskip\rightwhite}
                     \vskip\botwhite}%
              \global\advance\colcount by 1}
%%%%%%%%%%%%%%%%% and now the table itself %%%%%%%%%%%%%%%%%%%%%%%%%
\vbox{
\halign{\fatline\fourbit#\fb&\fatline\asc#\ii&\thinline\asc#\ii&
                     \fatline\asc#\ii&\thinline\asc#\ii&
                     \fatline\asc#\ii&\thinline\asc#\ii&
                     \fatline\asc#\ii&\thinline\asc#\ii\fatline\cr
          \omit&\multispan8 \hskip\thinlinewidth
                            \titlefont
                            %ASCII CONTROL CODE CHART
                            \hfil\cr
    \noalign{\vskip4mm\hrule}
          \omit\fatline\hfil\threebit{b7}{b6}{b5}
                 &\omit\fatline\threebit000&\omit\thinline\threebit001%
                 &\omit\fatline\threebit010&\omit\thinline\threebit011%
                 &\omit\fatline\threebit100&\omit\thinline\threebit101%
                 &\omit\fatline\threebit110&\omit\thinline\threebit111%
                                                 \fatline\cr
    \noalign{\vskip-.5mm} %brute force
          \omit\fatline\bithead
                 &\omit\fatline\comment{CONTROL}\span\omit
                 &\omit\fatline\dcomment{SYMBOLS}{NUMBERS}\span\omit
                 &\omit\fatline\comment{UPPER CASE}\span\omit
                 &\omit\fatline\comment{LOWER CASE}\span\omit\hfil\fatline\cr
    \noalign{\hrule}
      {} 0 0 0 0&NUL&DLE&SP     &0  &@  &P       &` &p  \cr\noalign{\hrule}
      {} 0 0 0 1&SOH&DC1&!      &1  &A  &Q       &a &q  \cr\noalign{\hrule}
      {} 0 0 1 0&STX&DC2&"      &2  &B  &R       &b &r  \cr\noalign{\hrule}
      {} 0 0 1 1&ETX&DC3&\#     &3  &C  &S       &c &s  \cr\noalign{\hrule}
      {} 0 1 0 0&EOT&DC4&\$     &4  &D  &T       &d &t  \cr\noalign{\hrule}
      {} 0 1 0 1&ENQ&NAK&\%     &5  &E  &U       &e &u  \cr\noalign{\hrule}
      {} 0 1 1 0&ACK&SYN&\&     &6  &F  &V       &f &v  \cr\noalign{\hrule}
      {} 0 1 1 1&BEL&ETB&'      &7  &G  &W       &g &w  \cr\noalign{\hrule}
      {} 1 0 0 0&BS &CAN&(      &8  &H  &X       &h &x  \cr\noalign{\hrule}
      {} 1 0 0 1&HT &EM &)      &9  &I  &Y       &i &y  \cr\noalign{\hrule}
      {} 1 0 1 0&LF &SUB&*      &:  &J  &Z       &j &z  \cr\noalign{\hrule}
      {} 1 0 1 1&VT &ESC&+      &;  &K  &[       &k &$\{$\cr  \noalign{\hrule}
      {} 1 1 0 0&FF &FS &,      &$<$&L  &\\      &l &$|$ \cr  \noalign{\hrule}
      {} 1 1 0 1&CR &GS &$-$    &=  &M  &]       &m &$\}$\cr  \noalign{\hrule}
      {} 1 1 1 0&SO &RS &.      &$>$&N  &\char94 &n &\char126\cr
                    \noalign{\hrule}
      {} 1 1 1 1&SI &US &/      &?  &O  &\_$\!$\_&o &DEL\cr\noalign{\hrule}
   \noalign{\vskip2mm}
          \omit&\omit\namefont \hfil LEGEND:\hfil \span\omit
          &\multispan4\hskip\fatlinewidth
            \vtop{\vskip-10pt\hbox{\vrule
             \vbox to \rowheight{
                 \offinterlineskip
                 \hrule\vskip \topwhite
                 \hbox to \colwidth{\codefont\hskip\leftwhite
                                       dec\hfil}
                 \vfil
                 \hbox to \colwidth{\namefont\hfil CHAR\hfil}
                 \vfil
                 \hbox to \colwidth{\codefont\hskip\leftwhite
                                       hex\hfil
                                       \hskip\rightwhite}
                 \vskip\botwhite
                 \hrule                               }%
                                  \vrule}}
                      \hfil
          &\multispan2\bitfont \hskip\fatlinewidth
                      \vtop{\vskip-8pt\baselineskip=8.5pt
                            \hbox{Victor Eijkhout}
                            \rlap{Dept. of Comp. Sci.}
                            \rlap{University of Tennessee}
                            \rlap{Knoxville TN 37996, USA}
                            }\hfil\cr
          }
}
%%%%%%%%%%%%%%%%%%%%%%% and that's it folks! %%%%%%%%%%%%%%%%%%%%%%%%%%

%\bye          %% PLAIN TeX
%\end{document} %% LaTeX

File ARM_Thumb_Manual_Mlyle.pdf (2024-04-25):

# ARM-Thumb Machine Code Reference

### Michael Lyle

### 2024 Edition

## Contents

1 Architecture Summary | 3
2 Using the ARM Microprocessor Trainer | 4
3 ARM-Thumb Basic Instructions | 9
4 ARM-Thumb Conditional Branches | 14
5 ARM-Thumb Miscellaneous Instructions | 17

6 Special (SuperVisor Call) Instructions | 21
7 Miscellaneous Reference | 25

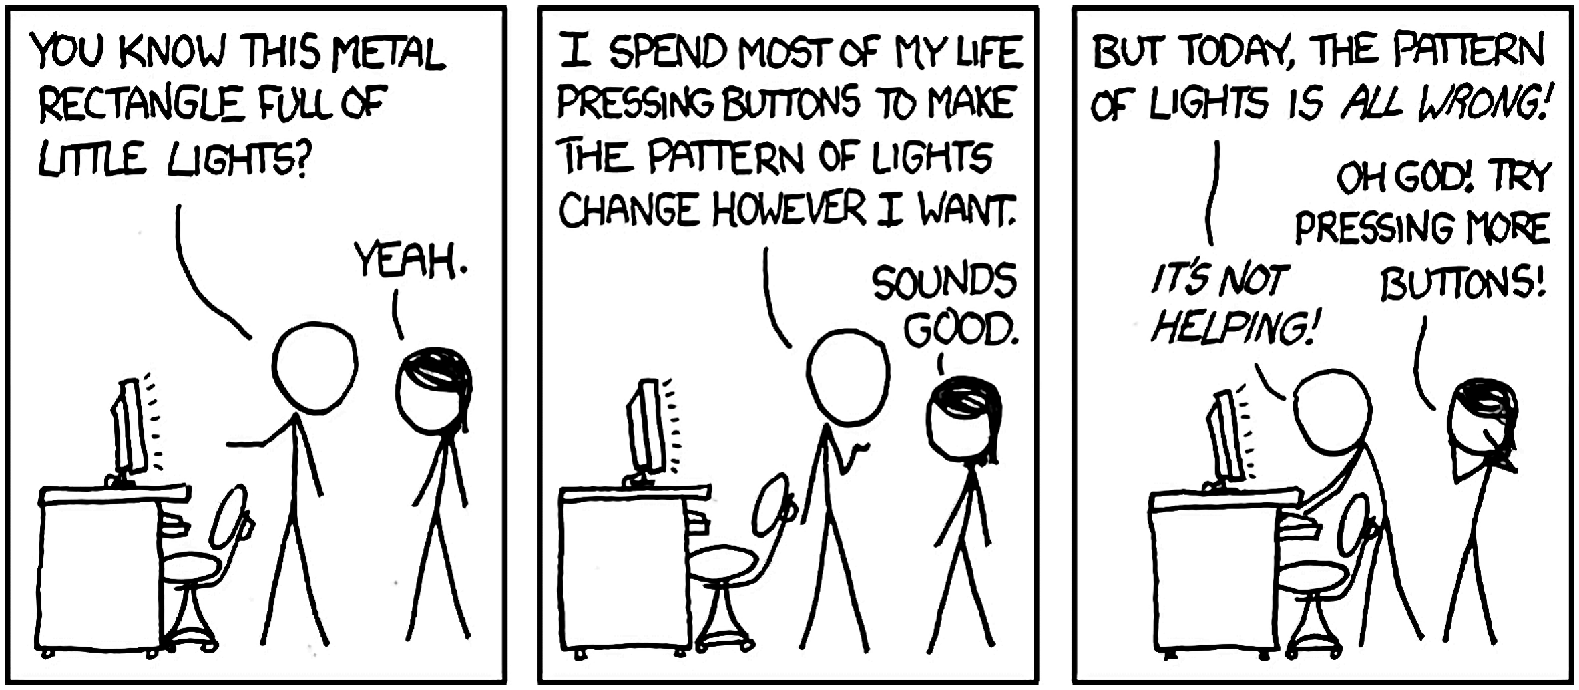
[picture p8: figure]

XKCD #722, ”Computer Problems” (by Randall Munroe)

## 1 Architecture Summary

In this course, we will be learning ARM Thumb machine language.

Specifically, we are writing code for the ARMv7 Thumb architecture. Its characteristics are:

- 32-bit (4 byte) register (word) size
- 32-bit (4 byte) address size
- 16-bit (2 byte) instruction length
- Addresses point to individual bytes. Instructions and words should be aligned in memory.

– An address pointing aligned with the beginning of a word will end in 0, 4, 8, or C in base 16.

– An address pointing to an instruction will end in 0, 2, 4, 6, 8, A, C, or E in base 16.

- Instructions can access memory, or perform arithmetic, but not both (RISC / load-store machine).
- Eight general-purpose registers are easily accessed (r0-r7).
- Five additional general-purpose registers are more difficult to access (r8-r12)
- Three special purpose registers (stack pointer, link register, and program counter)
- Capable ALU with hardware multiplier and standard flags:

– N (negative),

– Z (zero),

– C (carry),

– and V (overflow)

### 1.1 Machine Language vs. Assembly Language

In this course, we are writing programs in machine language. This is a raw sequence of numbers that tells the computer what to do.

One step up from machine language is to use assembly language, where each line of code cor-responds to a single machine instruction, which the assembler then translates into the binary format of machine language. Assemblers make the process of programming slightly easier by handling the details of instruction encoding and calculating addresses for the programmer.

Most contemporary programmers work with high-level languages, such as C, Java, or Python. These languages require conversion to machine code for execution. This is typically done through compilation, where the high-level code is translated into machine code, or through interpretation, where another program executes the high-level code step-by-step.

## 2 Using the ARM Microprocessor Trainer

You will be receiving an Microprocessor Trainer in this course. Before home computers were readily available, this was one way that many people learned to program. The Trainer has a keypad where you can inspect and manipulate the contents of memory, as well as run your program.

Unlike earlier trainers, the system designed for this class uses a modern instruction set, ARM-Thumb, which is still actively used on microcontrollers. It is closely related to the ARM instruction set used in modern phones, tablets, and Apple computers.

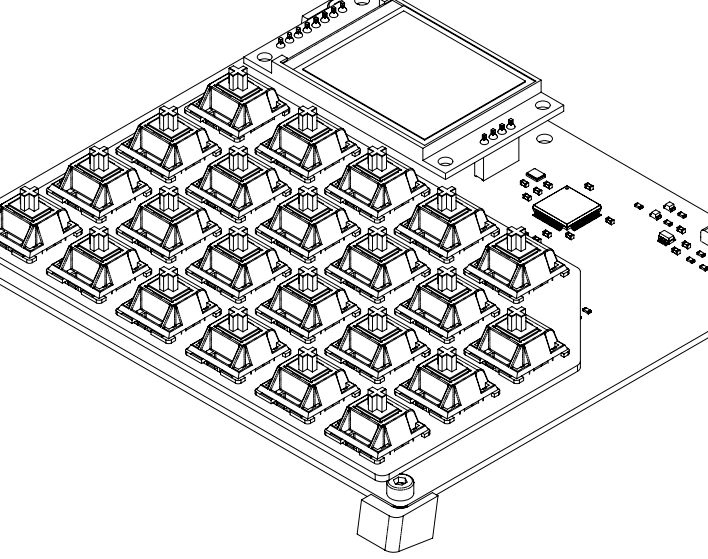
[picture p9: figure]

Figure 1: ARM Microprocessor Trainer, Revision B

If you’ve programmed before, this will be more cumbersome than you’re used to! It’s impor-tant to pre-plan your programs and think about what each instruction will do.

### 2.1 Description of Keys

- 0-9, A-F: Represent hexadecimal digits, which are used to enter numbers into the trainer.
- CLR: Functions as a backspace key, allowing you to correct any mistakes made during input.
- ADDR: Toggles the cursor between editing the memory address and the value at that address.
- LOAD: Loads the value located at the specified address into the display. Pressing this key repeatedly will advance the address sequentially, allowing you to view subsequent values.

- STOR: Saves the currently displayed value into the specified memory address, effectively writing data to memory. This will also advance the address.
- STEP: Executes the instruction at the current memory address and then automatically advances to the next address, facilitating step-by-step execution of your code.
- RUN: Starts a continuous execution of the program beginning at the current address. The execution will proceed without interruption until you press STEP.

### 2.2 Screen Contents

The screen provides an overview of the current status of the microprocessor trainer.

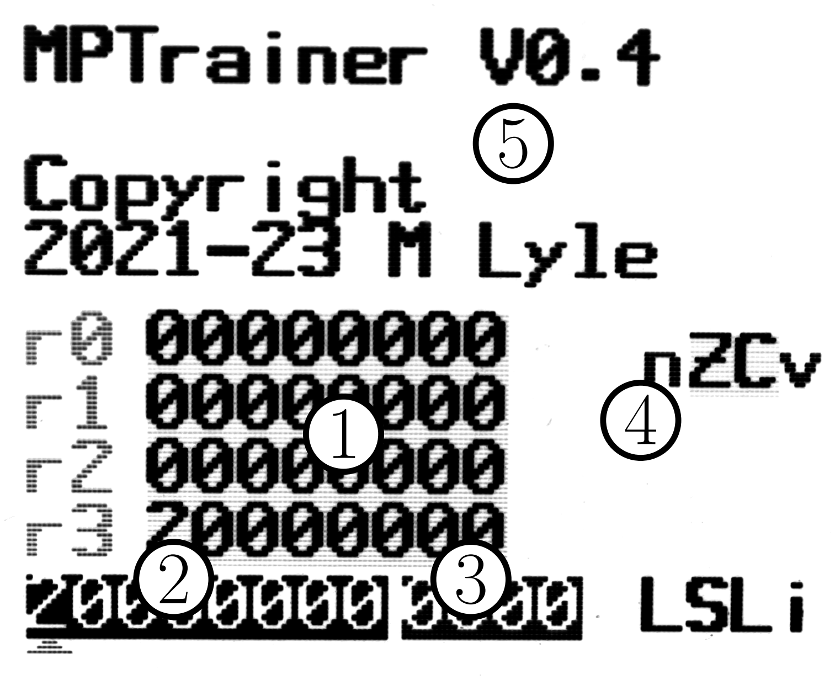
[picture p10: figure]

Figure 2: Screen Contents at Startup

Various types of information are displayed on the screen:

1. The values of registers are displayed centrally.
2. The current address is displayed on the left. A red arrow indicates we are currently editing the first digit of the address.
3. The value (that may be loaded or stored) is displayed to the right of the address.
4. The current flags (produced by the ALU and used by conditional branches) are displayed on the right side of the screen.
5. At the top of the screen is where a program’s input/output is displayed.

### 2.3 Entering Instructions

Once you have written your program and translated it into hexadecimal format, you will need to enter these instructions into the Microprocessor Trainer. Follow these steps to input each instruction:

1. Turn on the Microprocessor Trainer and locate the keypad.
2. Begin by setting the starting address where your program will be stored. Enter 20000000 using the numeric keys (0-9, A-F).
3. Press the ADDR key to switch the focus from entering an address to entering a value.
4. Now, enter the first instruction from your program. Remember, each instruction should be a 4-digit hexadecimal number (consisting of the characters 0-9 and A-F).
5. After typing the hexadecimal instruction, press the STOR key. This will store your instruction at the current address. The Trainer will automatically advance to the next memory address.
6. Repeat steps 4 and 5 for each subsequent instruction in your program:
- Enter the next 4-digit hexadecimal instruction.
- Press the STOR key to store the instruction and move to the next address.
7. Continue this process until you have entered all the instructions of your program.

Make sure you enter each instruction correctly and in the proper order. If you make a mistake, you can always go back to any address by entering it and pressing ADDR to correct the value.

Tip: Always double-check each instruction after entering it to make sure it has been input correctly before hitting STOR. This will save you time troubleshooting later!

Predicting Outcomes Before Execution: Before running your program, take a moment to predict the expected results and behavior of your code. For example, think about what values you expect to see in registers, and when. By anticipating the values in registers and the effects of each instruction, you can better identify when things might go wrong and understand why.

### 2.4 Running a Program

Once you have successfully entered all of your program’s instructions into the Microprocessor Trainer, the next step is to run your program to see how it works.

Setting the Starting Point: First, you need to set the Trainer to the beginning of your program. Ensure the address field is active by pressing ADDR if necessary. Using the keypad, enter the address 20000000, which is where your program starts. Finally, press the ADDR key to confirm the start address.

Choosing the Mode of Execution: With the starting address set, you have two options for running your program:

- Step-by-Step Execution: If you want to see how each instruction is executed one at a time, press the STEP key. This allows you to observe the changes and understand the flow of your program in detail. After pressing STEP, the Trainer executes the current instruction and then pauses, waiting for you to press STEP again for the next instruction.
- Continuous Execution: If you prefer to run your program continuously from the start to the end, press the RUN key. The Trainer will execute all the instructions continuously until the end of the program is reached, or until you press the STEP key to halt execution.

Monitoring and Troubleshooting: As your program runs, watch the display on the Trainer to see the outputs and any changes in the values stored in the memory. If the program does not behave as expected, you may need to stop the execution, review and correct the instructions you entered. Remember, debugging is a normal part of learning to program.

Tip: Start with the step-by-step execution mode when you’re testing a new program. It gives you a better understanding of how each part of your program works and helps in identifying and fixing any errors.

### 2.5 Inspecting Memory

After you run your program, or even while it is running, you might want to check what is happening inside the memory of the Microprocessor Trainer. This process is called ”inspecting memory,” and it lets you see the values stored in different memory locations. Here’s how you can do it:

Access the Memory: To look at the contents of a specific memory address, you need to first stop your program if it is running. You can do this by pressing the STEP key to pause execution.

Choosing the Address: Use the ADDR key to select the address field. Enter the desired memory address using the numeric keys (0-9, A-F). Remember that your program starts at 20000000, so any addresses from this point onward may contain data or instructions from your program.

Loading the Value from Memory: Once you have entered the desired address, press the LOAD key. This will load the value at the address you entered, and switch the cursor to the value field.

### 2.6 Function Keys

The LOAD key on the Microprocessor Trainer is not just for loading the value at the current address. When held down and used in combination with other keys, it activates a variety of special functions. Here’s how you can use these combinations effectively:

- Keys 0 - 2: Display different sets of registers on the screen. Pressing LOAD + 0 will show registers r0 to r3, which is the default display.
- Keys 4 - 6: Save the currently entered program into internal flash memory. Each key represents a different storage slot, allowing for multiple programs to be stored simultaneously.
- Keys 8 - A: Load previously saved programs from the corresponding slots in the internal flash memory. This is useful for retrieving and running stored code without re-entering it.
- Key D: Toggle the display mode of the registers between hexadecimal and decimal. This can be helpful for easier reading or specific debugging needs.
- Key F: Activate a fast run mode, which executes the program without updating the display between each instruction. This mode allows for quicker execution but is generally not recommended for debugging, as changes in registers and memory are not visible in real time.

### 2.7 The Easter Egg

In your explorations with the Microprocessor Trainer, there’s a special feature hidden for you to discover. This hidden feature, often called an ”Easter egg,” can be activated under specific conditions.

Hint: If you manage to load the ASCII values for the characters ’S’, ’N’, ’A’, and ’K’ into registers r0 through r3 respectively, and then execute a Supervisor Call (SVC) instruction code 4516 (which stands for ’E’ in ASCII), something unexpected will happen!

Discover on Your Own: You might want to figure out how to achieve this setup and see what happens for yourself. It’s a fun way to apply what you’ve learned about ASCII values, registers, and supervisor calls.

## 3 ARM-Thumb Basic Instructions

The following are just a few of the many instructions in the ARM-Thumb instruction set. There are enough instructions in this manual to be able to write any program. In other words, this set of instructions are Turing-complete. But other instructions, not listed here, are often necessary to write the shortest and fastest possible program.

ADD (add immediate) | 0011 0ddd iiii iiii

Add an 8 bit value (included in the instruction) to a register. Flags are updated based on the result value.

r[d] = r[d] + i

ddd | (3 bits) | This is the register number of the operand to add to, and
the destination register where the result should be placed.
iiii iiii | (8 bits) | This is the value that should be added, included as an
immediate operand in the instruction.

Examples:

0011 0ddd iiii iiii | 3??? | Basic instruction encoding
0011 0000 0000 0001 | 3001 | Adds the number 1 to r0
0011 0011 0001 0010 | 3312 | Adds the number 1216 (1810) to r3
0011 0111 1010 0101 | 37A5 | Adds the number A516 (16510) to r7
ADD (add registers) | 0001 100m mmnn nddd

Add two registers together, storing the result in a (optionally different) third register. Flags are updated.

r[d] = r[m] + r[n]

mmm | (3 bits) | This is the register number of the first operand to add.
nnn | (3 bits) | This is the register number of the second operand to add.
ddd | (3 bits) | This is the register number to store the result in.

Examples:

0001 100m mmnn nddd | 1??? | Basic instruction encoding
0001 1000 0000 0000 | 1800 | Adds r0 to register r0 and stores the re-
sult in r0 (doubles r0)
0001 1000 0101 0011 | 1853 | Adds r1 to r2 and stores the result in r3
0001 1000 1000 1011 | 188B | Adds r2 to r1 and stores the result in r3
(same as above)

B (branch) | 1110 0iii iiii iiii

Branches the program counter to a new location. (Goto a different part of your program)

pc = pc + 2 ∗ (i + 2)

iiiiiiii... | (11 bits) | Number of instructions to jump forward (or backwards, if
negative...)

Examples:

1110 0iii iiii iiii | E??? | Basic instruction encoding
1110 0111 1111 0000 | E7F0 | Goes back to 14 instructions before this
one.
1110 0111 1111 0001 | E7F1 | Goes back to 13 instructions before this
one.
1110 0111 1111 0010 | E7F2 | Goes back to 12 instructions before this
one.
1110 0111 1111 1100 | E7FC | Goes back to 2 instructions before this
one.
1110 0111 1111 1101 | E7FD | Goes back to 1 instructions before this
one.
1110 0111 1111 1110 | E7FE | Goes to THIS instruction (infinite loop)
1110 0111 1111 1111 | E7FF | Goes to the instruction after this one
(does nothing)
1110 0000 0000 0000 | E000 | Skips 1 instruction after this one
1110 0000 0000 0001 | E001 | Skips 2 instructions after this one
1110 0000 0000 0010 | E002 | Skips 3 instructions after this one
1110 0000 0000 1111 | E00F | Skips 16 instructions after this one
CMP (compare registers) | 0100 0010 10mm mnnn

Subtracts one register from another and updates flags. The result of the subtraction is thrown away.

tmp = r[n] − r[m]

nnn | (3 bits) | This is the register number of the operand to subtract from.
mmm | (3 bits) | This is the register number of the subtrahend

Examples:

0100 0010 10mm mnnn | 42?? | Basic instruction encoding
0100 0010 1000 0001 | 4281 | Subtracts r0 from register r1 and updates
flags
0100 0010 1011 1110 | 42BE | Subtracts r7 from register r6 and updates
flags

MOV (move immediate) | 0010 0ddd iiii iiii

Moves a value, provided in the instruction, into a chosen register.

r[d] = i

ddd | (3 bits) | This is the register number where the result should be
placed.
iiii iiii | (8 bits) | This is the value that should be placed into the destination
register. The high 24 bits of the register will be 0 and the remaining 8 bits will be the immediate value.

Examples:

0010 0ddd iiii iiii | 2??? | Basic instruction encoding
0010 0000 0000 0000 | 2000 | Sets r0 to the value 0
0010 0111 1111 1111 | 27FF | Sets r7 to the value FF16 (25510)
0010 0010 0000 0101 | 2205 | Puts the number 5 in r2
MOV (move register) | 0100 0110 00mm mddd

Copies a value from one register to another.

r[d] = r[m]

mmm | (3 bits) | This is the register number from which the value should be
copied.
ddd | (3 bits) | This is the register number where the value should be
placed.

Examples:

0100 0110 00mm mddd | 46?? | Basic instruction encoding
0100 0110 0000 1000 | 4608 | Sets r0 to the value in r1
0100 0110 0000 0001 | 4601 | Sets r1 to the value in r0
0100 0110 0011 1110 | 463E | Sets r6 to the value of r7

MUL (multiply registers) | 0100 0011 01nn nddd

Multiplies register n by register d, and stores the result in register d.

r[d] = r[d] ∗ r[n]

nnn | (3 bits) | This is the register number that contains the first number
to be multiplied.
ddd | (3 bits) | This is the register number with the second multiplicand,
and where the value should be placed.

Examples:

0100 0011 01nn nddd | 43?? | Basic instruction encoding
0100 0011 0100 0000 | 4340 | Squares r0 and puts the result back in r0
0100 0011 0100 1000 | 4348 | Sets r0 to r1 times r0
0100 0011 0100 0001 | 4341 | Sets r1 to r1 times r0
0100 0011 0110 0011 | 4363 | Sets r3 to r3 times r4
SUB (subtract immediate) | 0011 1ddd iiii iiii

Subtract an 8 bit value (included in the instruction) from a register. Flags are updated based on the result value.

r[d] = r[d] − i

ddd | (3 bits) | This is the register number of the operand to subtract
from, and the destination register where the result should be placed.
iiii iiii | (8 bits) | This is the value that should be subtracted, included as an
immediate operand in the instruction.

Examples:

0011 1ddd iiii iiii | 3??? | Basic instruction encoding
0011 1000 0000 0001 | 3801 | Subtracts the number 1 to r0
0011 1011 0011 0001 | 3B32 | Subtracts the number 3216 (5010) from r3
0011 1111 1010 0101 | 3FA5 | Subtracts the number A516 (16510) from
r7

SUB (subtract registers) | 0001 101m mmnn nddd

Subtract one register from another, storing the result in a (optionally different) third register. Flags are updated.

r[d] = r[n] − r[m]

nnn | (3 bits) | This is the register number of the operand to subtract.
nnn | (3 bits) | This is the register number of the operand to subtract from.
ddd | (3 bits) | This is the register number to store the result in.

Examples:

0001 101m mmnn nddd | 1??? | Basic instruction encoding
0001 1010 0000 0000 | 1A00 | Subtracts r0 from register r0 and stores
the result in r0 (sets r0 to 0)
0001 1010 0101 0011 | 1A53 | Subtracts r1 from r2 and stores the result
in r3
0001 1000 1000 1011 | 1A8B | Subtracts r2 from r1 and stores the result
in r3

## 4 ARM-Thumb Conditional Branches

BZ (branch if zero/equal) | 1101 0000 iiii iiii

Branches the program counter to a new location, IF the Z flag is set. This will branch if the result of the previous ALU operation was zero, or after using the CMP instruction on two equal values. If the Z flag is not set, this instruction does nothing and execution continues at the next instruction.

IF Z: pc = pc + 2 ∗ (i + 2)

iiiiiiii | (8 bits) | Number of instructions to jump forward (or backwards, if
negative...)

Examples:

1101 0000 iiii iiii | D0?? | Basic instruction encoding
1101 0000 1111 0000 | D0F0 | IF Z: Goes back to 14 instructions before
this one.
1101 0000 1111 0001 | D0F1 | IF Z: Goes back to 13 instructions before
this one.
1101 0000 1111 0010 | D0F2 | IF Z: Goes back to 12 instructions before
this one.
1101 0000 1111 1100 | D0FC | IF Z: Goes back to 2 instructions before
this one.
1101 0000 1111 1101 | D0FD | IF Z: Goes back to 1 instructions before
this one.
1101 0000 1111 1110 | D0FE | IF Z: Goes to THIS instruction (infinite
loop if taken)
1101 0000 1111 1111 | D0FF | IF Z: Goes to the instruction after this
one (does nothing, either way)
1101 0000 0000 0000 | D000 | IF Z: Skips 1 instruction after this one
1101 0000 0000 0001 | D001 | IF Z: Skips 2 instructions after this one
1101 0000 0000 0010 | D002 | IF Z: Skips 3 instructions after this one
1101 0000 0000 1111 | D00F | IF Z: Skips 16 instructions after this one

BNZ (branch if not zero/not equal) | 1101 0001 iiii iiii

Branches the program counter to a new location, IF the Z flag is not set. This will branch if the result of the previous ALU operation wasn’t zero, or after using the CMP instruction on two inequal values.

IF NOT Z: pc = pc + 2 ∗ (i + 2)

iiiiiiii | (8 bits) | Number of instructions to jump forward (or backwards, if
negative...)

Examples:

1101 0001 iiii iiii | D1?? | Basic instruction encoding
1101 0001 1111 0000 | D1F0 | IF NOT Z: Goes back to 14 instructions
before this one.
1101 0001 1111 0001 | D1F1 | IF NOT Z: Goes back to 13 instructions
before this one.
1101 0001 1111 1101 | D1FD | IF NOT Z: Goes back to 1 instructions
before this one.
1101 0001 1111 1111 | D1FF | IF NOT Z: Goes to the instruction after
this one (does nothing, either way)
1101 0001 0000 0000 | D100 | IF NOT Z: Skips 1 instruction after this
one
1101 0001 0000 0001 | D101 | IF NOT Z: Skips 2 instructions after this
one

BMI (branch if negative) | 1101 0100 iiii iiii

Branches the program counter to a new location, IF the if the result of the previous ALU operation was less than zero, or after using the CMP instruction where the comparand is larger than the other value.

IF N: pc = pc + 2 ∗ (i + 2)

iiiiiiii | (8 bits) | Number of instructions to jump forward (or backwards, if
negative...)

Examples:

1101 0100 iiii iiii | D4?? | Basic instruction encoding
1101 0100 1111 0000 | D4F0 | IF N: Goes back to 14 instructions before
this one.
1101 0100 1111 1101 | D4FD | IF N: Goes back to 1 instructions before
this one.
1101 0100 1111 1111 | D4FF | IF N: Goes to the instruction after this
one (does nothing)
1101 0100 0000 0000 | D400 | IF N: Skips 1 instruction after this one

There are more conditional branches. You can find information on how they are encoded in sections 7.2 and 7.2.1.

## 5 ARM-Thumb Miscellaneous Instructions

LSL (logical shift left, immediate) | 0000 0iii iimm mddd

Shifts register n left by a fixed number of bits, and stores the result in register d.

r[d] = r[m] << immediate

iiiii | (5 bits) | This is the number of bits to shift the number left.
mmm | (3 bits) | This is the register number that contains the number to be
shifted.
ddd | (3 bits) | This is the register number to store the result in.

Examples:

0000 0iii iimm mddd | 0??? | Basic instruction encoding
0000 0000 0100 0000 | 0040 | Shifts r0 one bit left (doubling it) and
puts the result back in r0
0000 0010 0010 0111 | 0227 | Shifts r4 eight bits left (multiplying by
256) and puts the result in r7
ORR (logical or, register) | 0100 0011 00mm mddd

Computes the logical or operation of registers m and d, and stores the result back in register d.

r[d] = r[m] logical-or r[d]

mmm | (3 bits) | This is the register number that contains the first operand
for logical-or.
ddd | (3 bits) | This is the register number that contains the second
operand for logical-or, and the destination register to store the result within.

Examples:

0100 0011 00mm mddd | 43?? | Basic instruction encoding
0100 0011 0000 1000 | 4308 | Ors r1 with r0 and stores the result in r0
0100 0011 0010 1110 | 432E | Ors r5 with r6 and stores the result in r6

AND (logical and, register) | 0100 0000 00mm mddd

Computes the logical and operation of registers m and d, and puts the result back in register d.

r[d] = r[m] logical-and r[d]

mmm | (3 bits) | This is the register number that contains the first operand
for logical-and.
ddd | (3 bits) | This is the register number that contains the second
operand for logical-and, and the destination register to put the result within.

Examples:

0100 0000 00mm mddd | 40?? | Basic instruction encoding
0100 0000 0000 1000 | 4008 | Ands r1 with r0 and stores the result in
r0
0100 0000 0010 1110 | 402E | Ands r5 with r6 and stores the result in
r6
LDR (load register) | 0101 100m mmnn nttt

Retrieves the word at the memory address formed from the sum of registers m and n, and puts the result in register t.

r[t] = memory(r[m] + r[n])

mmm | (3 bits) | This is the first register that is combined to form the mem-
ory address.
nnn | (3 bits) | This is the second register that is combined to form the
memory address.
ttt | (3 bits) | This is the target, where the word retrieved from memory
is placed.

Examples:

0101 100m mmnn nttt | 5??? | Basic instruction encoding
0101 1001 1100 0001 | 59C1 | Loads the value from address r7 + r0 into
r1

STR (store register) | 0101 000m mmnn nttt

Forms a memory address by adding registers m and n, and stores the contents of register t at that location.

memory(r[m] + r[n]) = r[t]

mmm | (3 bits) | This is the first register that is combined to form the mem-
ory address.
nnn | (3 bits) | This is the second register that is combined to form the
memory address.
ttt | (3 bits) | The contents of this register are stored to the chosen loca-
tion in memory.

Examples:

0101 000m mmnn nttt | 5??? | Basic instruction encoding
0101 0001 1100 0001 | 51C1 | Stores the value in r1 to the address r7
+ r0

### 5.1 Logical Shifting (Illustrated)

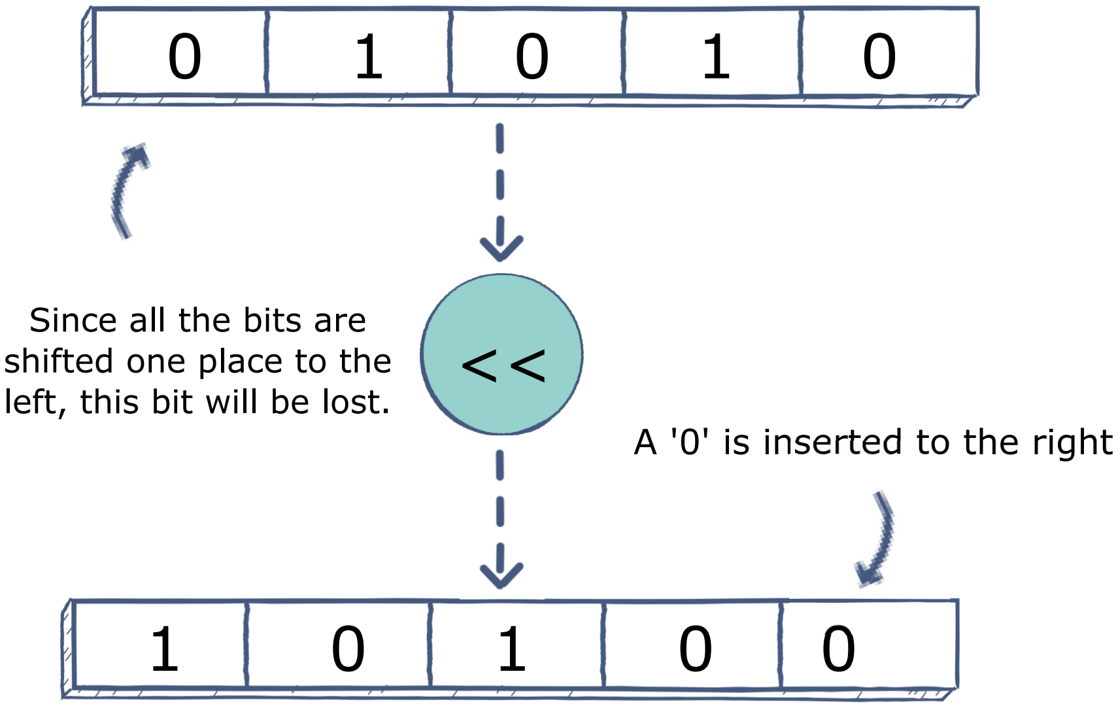
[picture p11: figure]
A '0' is inserted to the right; Since all the bits are shifted one place to the left, this bit will be lost.

### 5.2 Putting a Large Value in a Register

Often, it will be desirable to put a number larger than we can have in a single immediate into a register. The immediate move instruction available to us only can place an 8 bit value in a register, but registers are 32 bits wide.

There are many ways to accomplish this, including using load instructions. However, it can be complicated to calculate addresses. Below is a simple method to place the value 1234567816 into r0, while using r1 as a temporary space.

2012 | MOV r0, 1216 | Places the value 1216 into r0.
0200 | LSL r0, r0, #8 | Shifts r0 left 8 bits; it now contains 120016.
2134 | MOV r1, 3416 | Puts 3416 into r1.
4309 | ORR r0, r1 | Logical OR of r0 and r1, putting the result in r0, which now contains 123416.
0200 | LSL r0, r0, #8 | Shifts r0 left 8 bits; it now contains 12340016.
2156 | MOV r1, 5616 | Puts 5616 into r1.
4309 | ORR r0, r1 | Logical OR of r0 and r1, putting the result in r0, which now contains 12345616.
0200 | LSL r0, r0, #8 | Shifts register 0 left 8 bits; it now contains 1234560016.
2178 | MOV r1, 7816 | Puts 7816 into r1.
4309 | ORR r0, r1 | Logical OR of r0 and r1, putting the result in r0, which now contains 1234567816!

In this way, we can put large numbers into any of our registers. This approach isn’t terribly efficient: 10 instructions and 20 bytes are used to load a 4 byte word into a register, but it is simple and it works.

## 6 Special (SuperVisor Call) Instructions

Supervisor Call (SVC) instructions are special system-level operations that provide input/output (I/O) functionality and other system utilities. These instructions have been specifically con-figured for the computing environment used in this course.

Many of these expect for an appropriate value to be loaded to r0 (or other registers) before executing them.

SVC00 (toggle LED) | 1101 1111 0000 0000

If the LED is off, this turns it on. Otherwise, it turns the LED off.

1101 1111 0000 0000 | DF00 | Basic instruction encoding
SVC01 (turn LED off) | 1101 1111 0000 0001

Turns the LED off.

1101 1111 0000 0001 | DF01 | Basic instruction encoding
SVC02 (turn LED on) | 1101 1111 0000 0010

Turns the LED on.

1101 1111 0000 0010 | DF02 | Basic instruction encoding
SVC03 (blink the LED) | 1101 1111 0000 0011

This slowly blinks the LED. The value in r0 determines how many times the LED blinks.

1101 1111 0000 0011 | DF03 | Basic instruction encoding

SVC11 (sleep, tenths) | 1101 1111 0001 0001

This freezes the program for a short amount of time. The length of time, in tenths of a second, is specified in r0. For instance, if r0 is 15, this will wait 1.5 seconds before the program resumes running.

1101 1111 0001 0001 | DF11 | Basic instruction encoding
SVC12 (sleep, seconds) | 1101 1111 0001 0010

This freezes the program for a short amount of time. The length of time, in seconds, is specified in r0. For instance, if r0 is 15, this will wait 15 seconds before the program resumes running.

1101 1111 0001 0010 | DF12 | Basic instruction encoding
SVC20 (clear screen) | 1101 1111 0010 0000

This clears the top half of screen and positions the cursor to write out text at the upper left.

1101 1111 0010 0010 | DF20 | Basic instruction encoding
SVC21 (output number, denary) | 1101 1111 0010 0001

This prints the number in r0 on the screen, as a base 10 (denary) number. For instance, if r0 is F16 (or 1510), this will write the number 15 on the screen.

1101 1111 0010 0001 | DF21 | Basic instruction encoding

SVC22 (output number, hex) | 1101 1111 0010 0010

This prints the number in r0 on the screen, as a base 16 (hexadecimal) number. For instance, if r0 is F16 (or 1510), this will write F on the screen.

1101 1111 0010 0010 | DF22 | Basic instruction encoding
SVC23 (output ASCII character) | 1101 1111 0010 0011

This prints the character in r0 on the screen. Only the last 8 bits of r0 are used. For instance, if r0 is 4D16 (or 7710), this will write the character ’M’ on the screen. See the ASCII chart later in this guide for reference.

1101 1111 0010 0011 | DF23 | Basic instruction encoding

SVC24 (draw dot) | 1101 1111 0010 0100

This changes the color of one pixel on the screen. The color to put in the pixel is stored as an 8 bit value in r0. The coordinates to change are (r1, r2).

1101 1111 0010 0100 | DF24 | Basic instruction encoding
SVC25 (draw icon) | 1101 1111 0010 0101

This draws a 32 byte (16 halfword) icon on the screen. The icon is expected to immediately follow this instruction, and when the draw is complete the instruction pointer will be increased by 2216 to skip the icon data. The color to draw the icon is stored as an 8 bit value in r0. The coordinates to draw the icon at are (r1, r2).

1101 1111 0010 0101 | DF25 | Basic instruction encoding (32 bytes of icon data follow)

### 6.1 Screen Colors (8-bit)

SVC25 and SVC24 take in r0 an 8-bit color value. This color value is formatted in the bit pattern RRGG GBBB, where RR is a two-bit value indicating the intensity of the color red, GGG is a three-bit value indicating the intensity of green, and BBB is a three-bit value indicating the intensity of the color blue.

For instance, if it’s desired to draw an icon with the color purple, that requires bright red and bright blue, with no green. Therefore, we will use the color 1100 0111 for full intensity red, no green, and full intensity blue. This becomes the value C716 which can be placed into r0 with the instruction MOV R0, C7 encoded as 20C7.

### 6.2 Screen Coordinates

Screen drawing routines also take in coordinates in (r1, r2). Unlike graphing coordinates, as y gets bigger this moves down the screen. The upper left corner of the screen is at (0, 0). The upper right of the screen is at (160, 0). The lowest row that you should use on the screen is row 53. Therefore, the bottom left and right corners of the screen are positioned at (0, 53) and (160, 53), respectively.

## 7 Miscellaneous Reference

### 7.1 ASCII Character Map

b7 b6 b5 BITS b4 b3 b2 b1 | 0 0 0 | 0 0 1 | 0 1 0 | 0 1 1 | 1 0 0 | 1 0 1 | 1 1 0 | 1 1 1
| CONTROL | | SYMBOLS NUMBERS | | UPPER CASE | | LOWER CASE
0 0 0 0 | 0 NUL 0 | 16 DLE 10 | 32 SP 20 | 48 0 30 | 64 @ 40 | 80 P 50 | 96 ‘ 60 | 112 p 70
0 0 0 1 | 1 SOH 1 | 17 DC1 11 | 33 ! 21 | 49 1 31 | 65 A 41 | 81 Q 51 | 97 a 61 | 113 q 71
0 0 1 0 | 2 STX 2 | 18 DC2 12 | 34 ” 22 | 50 2 32 | 66 B 42 | 82 R 52 | 98 b 62 | 114 r 72
0 0 1 1 | 3 ETX 3 | 19 DC3 13 | 35 # 23 | 51 3 33 | 67 C 43 | 83 S 53 | 99 c 63 | 115 s 73
0 1 0 0 | 4 EOT 4 | 20 DC4 14 | 36 $ 24 | 52 4 34 | 68 D 44 | 84 T 54 | 100 d 64 | 116 t 74
0 1 0 1 | 5 ENQ 5 | 21 NAK 15 | 37 % 25 | 53 5 35 | 69 E 45 | 85 U 55 | 101 e 65 | 117 u 75
0 1 1 0 | 6 ACK 6 | 22 SYN 16 | 38 & 26 | 54 6 36 | 70 F 46 | 86 V 56 | 102 f 66 | 118 v 76
0 1 1 1 | 7 BEL 7 | 23 ETB 17 | 39 ’ 27 | 55 7 37 | 71 G 47 | 87 W 57 | 103 g 67 | 119 w 77
1 0 0 0 | 8 BS 8 | 24 CAN 18 | 40 ( 28 | 56 8 38 | 72 H 48 | 88 X 58 | 104 h 68 | 120 x 78
1 0 0 1 | 9 HT 9 | 25 EM 19 | 41 ) 29 | 57 9 39 | 73 I 49 | 89 Y 59 | 105 i 69 | 121 y 79
1 0 1 0 | 10 LF A | 26 SUB 1A | 42 * 2A | 58 : 3A | 74 J 4A | 90 Z 5A | 106 j 6A | 122 z 7A
1 0 1 1 | 11 VT B | 27 ESC 1B | 43 + 2B | 59 ; 3B | 75 K 4B | 91 [ 5B | 107 k 6B | 123 { 7B
1 1 0 0 | 12 FF C | 28 FS 1C | 44 , 2C | 60 < 3C | 76 L 4C | 92 \ 5C | 108 l 6C | 124 | 7C
1 1 0 1 | 13 CR D | 29 GS 1D | 45 − 2D | 61 = 3D | 77 M 4D | 93 ] 5D | 109 m 6D | 125 } 7D
1 1 1 0 | 14 SO E | 30 RS 1E | 46 . 2E | 62 > 3E | 78 N 4E | 94 ˆ 5E | 110 n 6E | 126 ˜ 7E
1 1 1 1 | 15 SI F | 31 US 1F | 47 / 2F | 63 ? 3F | 79 O 4F | 95 5F | 111 o 6F | 127 DEL 7F
LEGEND: | dec CHAR hex
Victor Eijkhout
Dept. of Comp. Sci.
University of Tennessee
Knoxville TN 37996, USA
| (modified by Michael Lyle, 2021)

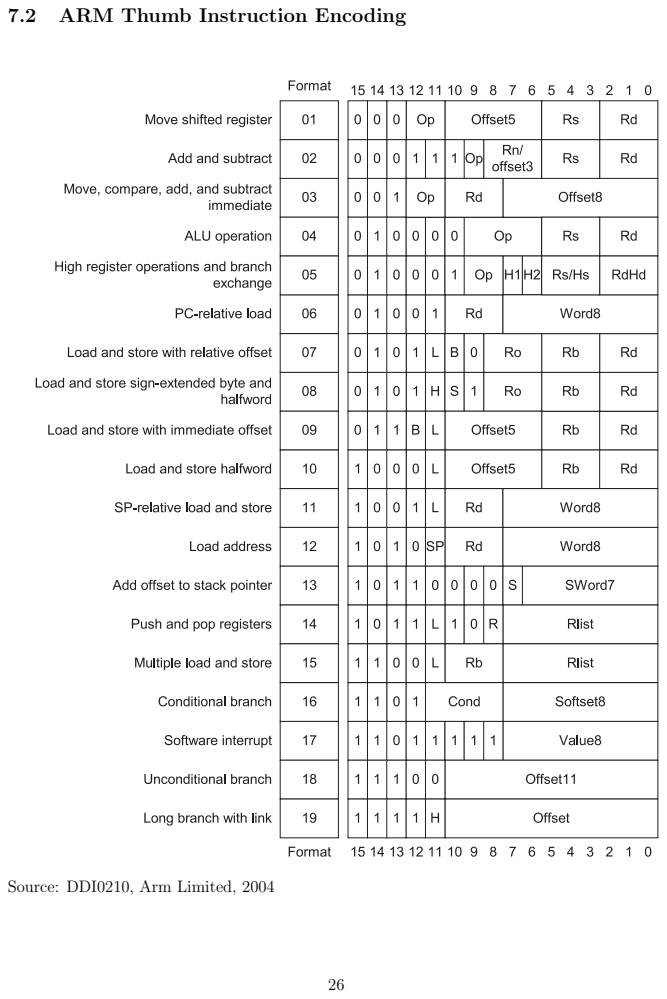
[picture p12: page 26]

7.2 ARM Thumb Instruction Encoding

Source: DDI0210, Arm Limited, 2004

### 7.2.1 CondCodes and Suffixes for Conditional Branches

Code | Suffix | Flags | Meaning
0000 | EQ | Z set | equal
0001 | NE | Z clear | not equal
0010 | CS | C set | unsigned higher or same
0011 | CC | C clear | unsigned lower
0100 | MI | N set | negative
0101 | PL | N clear | positive or zero
0110 | VS | V set | overflow
0111 | VC | V clear | no overflow
1000 | HI | C set and Z clear | unsigned higher
1001 | LS | C clear or Z set | unsigned lower or same
1010 | GE | N equals V | greater or equal
1011 | LT | N not equal to V | less than
1100 | GT | Z clear AND (N equals V) | greater than
1101 | LE | Z set OR (N not equal to V) | less than or equal
1110 | AL | (ignored) | always

Source: DDI0084D, Arm Limited, 1998

### 7.3 Hexadecimal and Decimal Conversion (Nybbles)

Decimal Binary Hexadecimal
0 | 0000 | 0
1 | 0001 | 1
2 | 0010 | 2
3 | 0011 | 3
4 | 0100 | 4
5 | 0101 | 5
6 | 0110 | 6
7 | 0111 | 7

Decimal Binary Hexadecimal
8 | 1000 | 8
9 | 1001 | 9
10 | 1010 | A
11 | 1011 | B
12 | 1100 | C
13 | 1101 | D
14 | 1110 | E
15 | 1111 | F

### 7.4 Branch Offsets (as used in B, BNZ, etc.)

Number of Instructions | Address
| Offset
8 | Bit | Conditional
| | Branch Offset | 11 Bit Branch
| | | Offset
Back 30 | −3C16 | E016 | 7E016
Back 29 | −3A16 | E116 | 7E116
Back 16 | −2016 | EE16 | 7EE16
Back 15 | −1E16 | EF16 | 7EF16
Back 14 | −1C16 | F016 | 7F016
Back 13 | −1A16 | F116 | 7F116
Back 12 | −1816 | F216 | 7F216
Back 2 | −416 | F C16 | 7F C16
Back 1 | −216 | F D16 | 7F D16
Infinite Loop | 0 | F E16 | 7F E16
Forward 1 (Do Nothing) | +216 | F F16 | 7F F16
Forward 2 (Skip 1) | +416 | 0016 | 00016
Forward 3 (Skip 2) | +616 | 0116 | 00116
Forward 15 (Skip 14) | +1E16 | 0E16 | 00E16
Forward 16 (Skip 15) | +2016 | 0F16 | 00F16
Forward 17 (Skip 16) | +2216 | 1016 | 01016
Forward 18 (Skip 17) | +2416 | 1116 | 01116

General Equation for Branch Calculation: Offset = Target−CurAddr
2 | + 2

Backwards Unconditional Branches: Offset = 80016 +

Target−CurAddr
2 | − 2

Backwards 8-bit Conditional Branches: Offset = 10016 +

Target−CurAddr
2 | − 2

Thumb® 16-bit Instruction Set

Quick Reference Card

This card lists all Thumb instructions available on Thumb-capable processors earlier than ARM®v6T2. In addition, it lists all Thumb-2 16-bit instructions.

The instructions shown on this card are all 16-bit in Thumb-2, except where noted otherwise.

All registers are Lo (R0-R7) except where specified. Hi registers are R8-R15.

Key to Tables

§ See Table ARM architecture versions. <loreglist+LR> A comma-separated list of Lo registers. plus the LR, enclosed in braces, { and }.
<loreglist> A comma-separated list of Lo registers, enclosed in braces, { and }. <loreglist+PC> A comma-separated list of Lo registers. plus the PC, enclosed in braces, { and }.

Operation § Assembler Updates Action Notes

Move Immediate MOVS Rd, #<imm> N Z Rd := imm imm range 0-255.

Lo to Lo MOVS Rd, Rm N Z Rd := Rm Synonym of LSLS Rd, Rm, #0

Hi to Lo, Lo to Hi, Hi to Hi MOV Rd, Rm Rd := Rm Not Lo to Lo.

Any to Any 6 MOV Rd, Rm Rd := Rm Any register to any register.

Add Immediate 3 ADDS Rd, Rn, #<imm> N Z C V Rd := Rn + imm imm range 0-7.

All registers Lo ADDS Rd, Rn, Rm N Z C V Rd := Rn + Rm

Hi to Lo, Lo to Hi, Hi to Hi ADD Rd, Rd, Rm Rd := Rd + Rm Not Lo to Lo.

Any to Any T2 ADD Rd, Rd, Rm Rd := Rd + Rm Any register to any register.

Immediate 8 ADDS Rd, Rd, #<imm> N Z C V Rd := Rd + imm imm range 0-255.

With carry ADCS Rd, Rd, Rm N Z C V Rd := Rd + Rm + C-bit

Value to SP ADD SP, SP, #<imm> SP := SP + imm imm range 0-508 (word-aligned).

Form address from SP ADD Rd, SP, #<imm> Rd := SP + imm imm range 0-1020 (word-aligned).

Form address from PC ADR Rd, <label> Rd := label label range PC to PC+1020 (word-aligned).

Subtract Lo and Lo SUBS Rd, Rn, Rm N Z C V Rd := Rn – Rm

Immediate 3 SUBS Rd, Rn, #<imm> N Z C V Rd := Rn – imm imm range 0-7.

Immediate 8 SUBS Rd, Rd, #<imm> N Z C V Rd := Rd – imm imm range 0-255.

With carry SBCS Rd, Rd, Rm N Z C V Rd := Rd – Rm – NOT C-bit

Value from SP SUB SP, SP, #<imm> SP := SP – imm imm range 0-508 (word-aligned).

Negate RSBS Rd, Rn, #0 N Z C V Rd := – Rn Synonym: NEGS Rd, Rn

Multiply Multiply MULS Rd, Rm, Rd N Z * * Rd := Rm * Rd * C and V flags unpredictable in §4T,

unchanged in §5T and above

Compare CMP Rn, Rm N Z C V update APSR flags on Rn – Rm Can be Lo to Lo, Lo to Hi, Hi to Lo, or Hi to Hi.

Negative CMN Rn, Rm N Z C V update APSR flags on Rn + Rm

Immediate CMP Rn, #<imm> N Z C V update APSR flags on Rn – imm imm range 0-255.

Logical AND ANDS Rd, Rd, Rm N Z Rd := Rd AND Rm
Exclusive OR EORS Rd, Rd, Rm N Z Rd := Rd EOR Rm
OR ORRS Rd, Rd, Rm N Z Rd := Rd OR Rm

Bit clear BICS Rd, Rd, Rm N Z Rd := Rd AND NOT Rm

Move NOT MVNS Rd, Rd, Rm N Z Rd := NOT Rm

Test bits TST Rn, Rm N Z update APSR flags on Rn AND Rm

Shift/rotate Logical shift left LSLS Rd, Rm, #<shift> N Z C* Rd := Rm << shift Allowed shifts 0-31. * C flag unaffected if shift is 0.

LSLS Rd, Rd, Rs N Z C* Rd := Rd << Rs[7:0] * C flag unaffected if Rs[7:0] is 0.

Logical shift right LSRS Rd, Rm, #<shift> N Z C Rd := Rm >> shift Allowed shifts 1-32.

LSRS Rd, Rd, Rs N Z C* Rd := Rd >> Rs[7:0] * C flag unaffected if Rs[7:0] is 0.

Arithmetic shift right ASRS Rd, Rm, #<shift> N Z C Rd := Rm ASR shift Allowed shifts 1-32.

ASRS Rd, Rd, Rs N Z C* Rd := Rd ASR Rs[7:0] * C flag unaffected if Rs[7:0] is 0.

Rotate right RORS Rd, Rd, Rs N Z C* Rd := Rd ROR Rs[7:0] * C flag unaffected if Rs[7:0] is 0. 29

Thumb 16-bit Instruction Set

Quick Reference Card

Operation § Assembler Action Notes

Load with immediate offset, word LDR Rd, [Rn, #<imm>] Rd := [Rn + imm] imm range 0-124, multiple of 4.

halfword LDRH Rd, [Rn, #<imm>] Rd := ZeroExtend([Rn + imm][15:0]) Clears bits 31:16. imm range 0-62, even.

byte LDRB Rd, [Rn, #<imm>] Rd := ZeroExtend([Rn + imm][7:0]) Clears bits 31:8. imm range 0-31.

with register offset, word LDR Rd, [Rn, Rm] Rd := [Rn + Rm] halfword LDRH Rd, [Rn, Rm] Rd := ZeroExtend([Rn + Rm][15:0]) Clears bits 31:16

signed halfword LDRSH Rd, [Rn, Rm] Rd := SignExtend([Rn + Rm][15:0]) Sets bits 31:16 to bit 15

byte LDRB Rd, [Rn, Rm] Rd := ZeroExtend([Rn + Rm][7:0]) Clears bits 31:8

signed byte LDRSB Rd, [Rn, Rm] Rd := SignExtend([Rn + Rm][7:0]) Sets bits 31:8 to bit 7

PC-relative LDR Rd, <label> Rd := [label] label range PC to PC+1020 (word-aligned).

SP-relative LDR Rd, [SP, #<imm>] Rd := [SP + imm] imm range 0-1020, multiple of 4.

Multiple, not including base LDM Rn!, <loreglist> Loads list of registers (not including Rn) Always updates base register, Increment After.
Multiple, including base LDM Rn, <loreglist> Loads list of registers (including Rn) Never updates base register, Increment After.

Store with immediate offset, word STR Rd, [Rn, #<imm>] [Rn + imm] := Rd imm range 0-124, multiple of 4.

halfword STRH Rd, [Rn, #<imm>] [Rn + imm][15:0] := Rd[15:0] Ignores Rd[31:16]. imm range 0-62, even.

byte STRB Rd, [Rn, #<imm>] [Rn + imm][7:0] := Rd[7:0] Ignores Rd[31:8]. imm range 0-31.

with register offset, word STR Rd, [Rn, Rm] [Rn + Rm] := Rd halfword STRH Rd, [Rn, Rm] [Rn + Rm][15:0] := Rd[15:0] Ignores Rd[31:16]
byte STRB Rd, [Rn, Rm] [Rn + Rm][7:0] := Rd[7:0] Ignores Rd[31:8]

SP-relative, word STR Rd, [SP, #<imm>] [SP + imm] := Rd imm range 0-1020, multiple of 4.

Multiple STM Rn!, <loreglist> Stores list of registers Always updates base register, Increment After.

Push Push PUSH <loreglist> Push registers onto full descending stack

Push with link PUSH <loreglist+LR> Push LR and registers onto full descending stack

Pop Pop POP <loreglist> Pop registers from full descending stack

Pop and return 4T POP <loreglist+PC> Pop registers, branch to address loaded to PC

Pop and return with exchange 5T POP <loreglist+PC> Pop, branch, and change to ARM state if address[0] = 0
If-Then If-Then T2 IT{pattern} {cond} Makes up to four following instructions conditional,

according to pattern. pattern is a string of up to three

letters. Each letter can be T (Then) or E (Else).

The first instruction after IT has condition cond. The following
instructions have condition cond if the corresponding letter
is T, or the inverse of cond if the corresponding letter is E.

See Table Condition Field.

Branch Conditional branch B{cond} <label> If {cond} then PC := label label must be within – 252 to + 258 bytes of current instruction.

See Table Condition Field.

Compare, branch if (non) zero T2 CB{N}Z Rn,<label> If Rn {== | !=} 0 then PC := label label must be within +4 to +130 bytes of current instruction.

Unconditional branch B <label> PC := label label must be within ±2KB of current instruction.

Long branch with link BL <label> LR := address of next instruction, PC := label This is a 32-bit instruction.

label must be within ±4MB of current instruction (T2: ±16MB).

Branch and exchange BX Rm PC := Rm AND 0xFFFFFFFE Change to ARM state if Rm[0] = 0.

Branch with link and exchange 5T BLX <label> LR := address of next instruction, PC := label

Change to ARM

This is a 32-bit instruction.

label must be within ±4MB of current instruction (T2: ±16MB).

Branch with link and exchange 5T BLX Rm LR := address of next instruction,

PC := Rm AND 0xFFFFFFFE

Change to ARM state if Rm[0] = 0.

Extend Signed, halfword to word 6 SXTH Rd, Rm Rd[31:0] := SignExtend(Rm[15:0])
Signed, byte to word 6 SXTB Rd, Rm Rd[31:0] := SignExtend(Rm[7:0])

Unsigned, halfword to word 6 UXTH Rd, Rm Rd[31:0] := ZeroExtend(Rm[15:0])
Unsigned, byte to word 6 UXTB Rd, Rm Rd[31:0] := ZeroExtend(Rm[7:0])

Reverse Bytes in word 6 REV Rd, Rm Rd[31:24] := Rm[7:0], Rd[23:16] := Rm[15:8], Rd[15:8] := Rm[23:16], Rd[7:0] := Rm[31:24]

Bytes in both halfwords 6 REV16 Rd, Rm Rd[15:8] := Rm[7:0], Rd[7:0] := Rm[15:8], Rd[31:24] := Rm[23:16], Rd[23:16] := Rm[31:24]
Bytes in low halfword, sign extend 6 REVSH Rd, Rm Rd[15:8] := Rm[7:0], Rd[7:0] := Rm[15:8], Rd[31:16] := Rm[7] * &FFFF 30

www.arm.com

Thumb 16-bit Instruction Set

Quick Reference Card

Operation § Assembler Action Notes

Processor

state

change

Supervisor Call SVC <immed_8> Supervisor Call processor exception 8-bit immediate value encoded in instruction. Formerly SWI.

Change processor state 6 CPSID <iflags> Disable specified interrupts
6 CPSIE <iflags> Enable specified interrupts

Set endianness 6 SETEND <endianness> Sets endianness for loads and saves. <endianness> can be BE (Big Endian) or LE (Little Endian).

Breakpoint 5T BKPT <immed_8> Prefetch abort or enter debug state 8-bit immediate value encoded in instruction.
No Op No operation NOP None, might not even consume any time. Real NOP available in ARM v6K and above.

Hint Set event T2 SEV Signal event in multiprocessor system. Executes as NOP in Thumb-2. Functionally available in ARM v7.
Wait for event T2 WFE Wait for event, IRQ, FIQ, Imprecise abort, or Debug entry request. Executes as NOP in Thumb-2. Functionally available in ARM v7.

Wait for interrupt T2 WFI Wait for IRQ, FIQ, Imprecise abort, or Debug entry request. Executes as NOP in Thumb-2. Functionally available in ARM v7.
Yield T2 YIELD Yield control to alternative thread. Executes as NOP in Thumb-2. Functionally available in ARM v7.

Condition Field

Mnemonic Description In Thumb code for processors earlier than ARMv6T2, cond must not appear anywhere except

in Conditional Branch ( B{cond} ) instructions. EQ Equal

NE Not equal

CS / HS Carry Set / Unsigned higher or same In Thumb-2 code, cond can appear in any of these instructions (except CBZ, CBNZ, CPSID,

CPSIE, IT, and SETEND).

The condition is encoded in a preceding IT instruction (except in the case of B{cond}

instructions).

If IT instructions are explicitly provided in the Assembly language source file, the
conditions in the instructions must match the corresponding IT instructions.

CC / LO Carry Clear / Unsigned lower

MI Negative

PL Positive or zero

VS Overflow

VC No overflow

HI Unsigned higher ARM architecture versions

LS Unsigned lower or same 4T All Thumb versions of ARM v4 and above.

GE Signed greater than or equal 5T All Thumb versions of ARM v5 and above.

LT Signed less than 6 All Thumb versions of ARM v6 and above.

GT Signed greater than T2 All Thumb-2 versions of ARM v6 and above.

LE Signed less than or equal

AL Always. Do not use in B{cond}

Proprietary Notice

Words and logos marked with ® or ™ are registered trademarks or trademarks of ARM Limited in the EU
and other countries, except as otherwise stated below in this proprietary notice. Other brands and names

mentioned herein may be the trademarks of their respective owners.

Neither the whole nor any part of the information contained in, or the product described in, this document

may be adapted or reproduced in any material form except with the prior written permission of the

copyright holder.

The product described in this document is subject to continuous developments and improvements. All

particulars of the product and its use contained in this document are given by ARM in good faith.
However, all warranties implied or expressed, including but not limited to implied warranties of

merchantability, or fitness for purpose, are excluded.

This reference card is intended only to assist the reader in the use of the product. ARM Ltd shall not be

liable for any loss or damage arising from the use of any information in this reference card, or any error

or omission in such information, or any incorrect use of the product.

Document Number

ARM QRC 0006E

Change Log

Issue Date Change

A Nov 2004 First Release

B May 2005 RVCT 2.2 SP1

C March 2006 RVCT 3.0

D March 2007 RVCT 3.1

E Sept 2008 RVCT 4.0

CO&D Name: | Date:

## Program Name:

Address16 | Instruction16 | Mnemonic | Value16 and/or Source-Regs | Dest-Reg
| | | (notes)

20000000

20000002

20000004

20000006

20000008

2000000A

2000000C

2000000E

20000010

20000012

20000014

CO&D Name: | Date:

## Program Name:

Address16 | Instruction16 | Mnemonic | Value16 and/or Source-Regs | Dest-Reg
| | | (notes)

CO&D Name: | Date:

## Program Name:

## Execution Trace

Address16 | R016 | R116 | R216 | R316 | Notes

## Index

add, 9, 29
address, 3, 6, 19, 20, 30
ASCII, 23, 25
assembly, 3

binary, 28
branch, 10, 30
conditional, 14–16
offsets, 28

colors, 24
compare, 10
condition codes, 27

decimal, 8, 28
delay, 22

hexadecimal, 28

icon, 24
immediate instructions, 9, 11, 12, 17 instruction encodings, 26

LED, 21
loading, 8
logical
and, 18, 30
or, 17, 20, 30
shift, 17, 20, 30

memory
load, 7, 18, 20, 30
store, 6, 19, 30
move, 11, 20, 29
multiply, 12

nybble, 28

registers, 3, 5, 8

saving, 8
screen, 5, 22–24
snake, 8
subtract, 12, 13, 29
supervisor call (SVC), 21, 31

ARM-Thumb Machine Code Reference by Michael Lyle is licensed under Creative Commons Attribution 4.0 International. To view a copy of this license, visit https://creativecommons.org/licenses/by/4.0/

The Thumb Quick Reference Card, and the instruction encoding information from DDI0210 and DDI0084D, copyright ARM Holdings. The ASCII reference sheet is by Victor Eijkhout. The XKCD comic is by Randall Munroe. The below comic, Captain Zilog, is from Zilog Corporation. All rights for these documents remain with their respective authors.

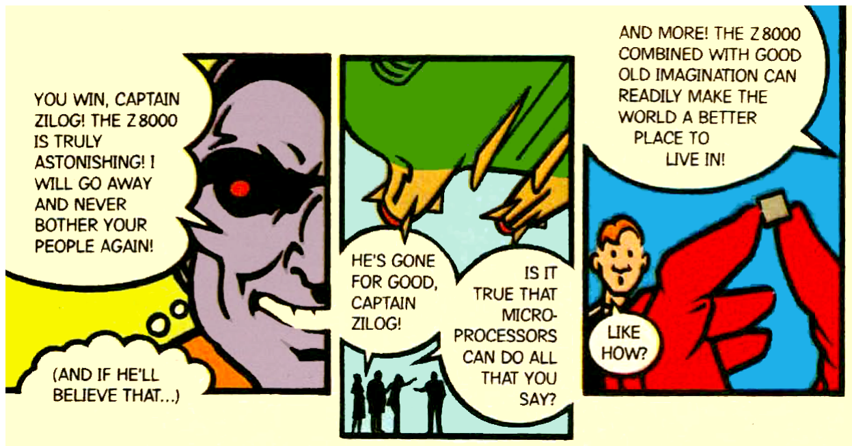
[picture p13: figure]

Figure 3: From Captain Zilog, 1979, Zilog, Inc.

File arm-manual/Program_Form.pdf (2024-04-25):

CO&D Name: | Date:

### Program Name:

Address16 | Instruction16 | Mnemonic | Value16 and/or Source-Regs | Dest-Reg
| | | (notes)

20000000

20000002

20000004

20000006

20000008

2000000A

2000000C

2000000E

20000010

20000012

20000014

### Program Name:

Address16 | Instruction16 | Mnemonic | Value16 and/or Source-Regs | Dest-Reg
| | | (notes)

### Program Name:

### Execution Trace

Address16 | R016 | R116 | R216 | R316 | Notes

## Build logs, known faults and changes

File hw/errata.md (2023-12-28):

Revision B errata:

* LEDs are way, way, way too bright.  Even covered in sharpie they're unpleasant.  Suggest R10/R11 go much bigger-- perhaps even use the 5.1k resistors we're using elsewhere (0.3mA).

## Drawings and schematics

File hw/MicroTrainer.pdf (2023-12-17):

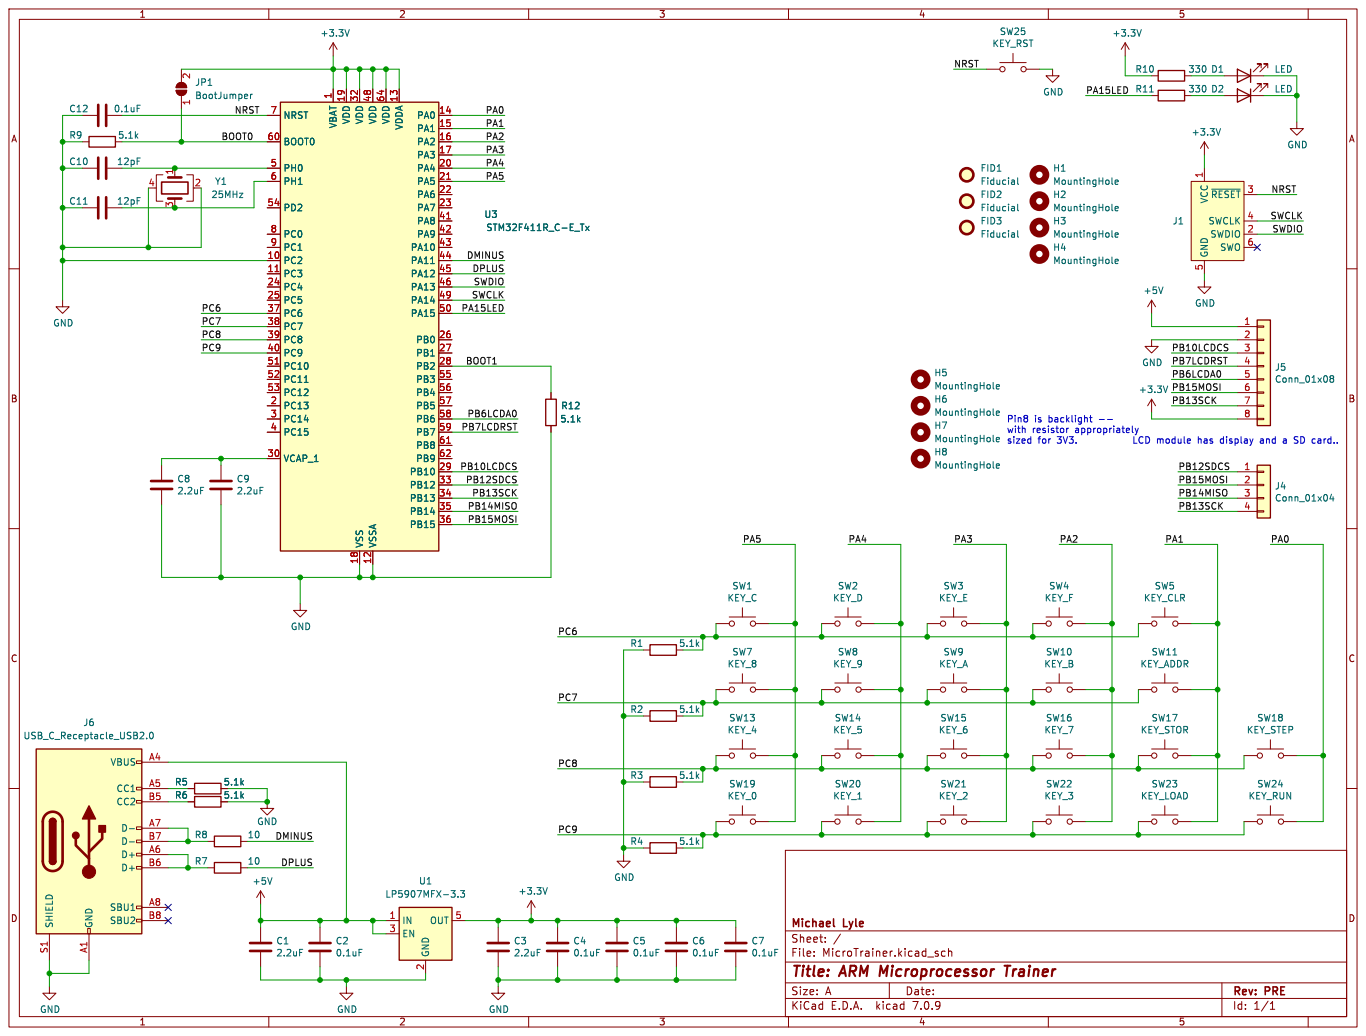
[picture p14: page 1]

1 PC2 10 PC3 11 VSSA 12 VDDA 13 PA0 14 PA1 15 PA2 16 PA3 17 VSS 18 VDD 19 PC13 2 PA4 20 PA5 21 PA6 22 PA7 23 PC4 24 PC5 25 PB0 26 PB1 27 PB2 28 PB10 29 PC14 3 VCAP_1 30 VDD 32 PB12 33 PB13 34 PB14 35 PB15 36 PC6 37 PC7 38 PC8 39 PC15 4 PC9 40 PA8 41 PA9 42 PA10 43 PA11 44 PA12 45 PA13 46 VDD 48 PA14 49 PH0 5 PA15 50 PC10 51 PC11 52 PC12 53 PD2 54 PB3 55 PB4 56 PB5 57 PB6 58 PB7 59 PH1 6 BOOT0 60 PB8 61 PB9 62 VDD 64 NRST 7 PC0 8 PC1 9 R6 5.1k R5 5.1k

1 PC2 10 PC3 11 VSSA 12 VDDA 13 PA0 14 PA1 15 PA2 16 PA3 17 VSS 18 VDD 19 PC13 2 PA4 20 PA5 21 PA6 22 PA7 23 PC4 24 PC5 25 PB0 26 PB1 27 PB2 28 PB10 29 PC14 3 VCAP_1 30 VDD 32 PB12 33 PB13 34 PB14 35 PB15 36 PC6 37 PC7 38 PC8 39 PC15 4 PC9 40 PA8 41 PA9 42 PA10 43 PA11 44 PA12 45 PA13 46 VDD 48 PA14 49 PH0 5 PA15 50 PC10 51 PC11 52 PC12 53 PD2 54 PB3 55 PB4 56 PB5 57 PB6 58 PB7 59 PH1 6 BOOT0 60 PB8 61 PB9 62 VDD 64 NRST 7 PC0 8 PC1 9 U3STM32F411R_C-E_Tx R12

1 SWDIO 2 ~{RESET}3 SWCLK 4 GND
NRST PB13SCK

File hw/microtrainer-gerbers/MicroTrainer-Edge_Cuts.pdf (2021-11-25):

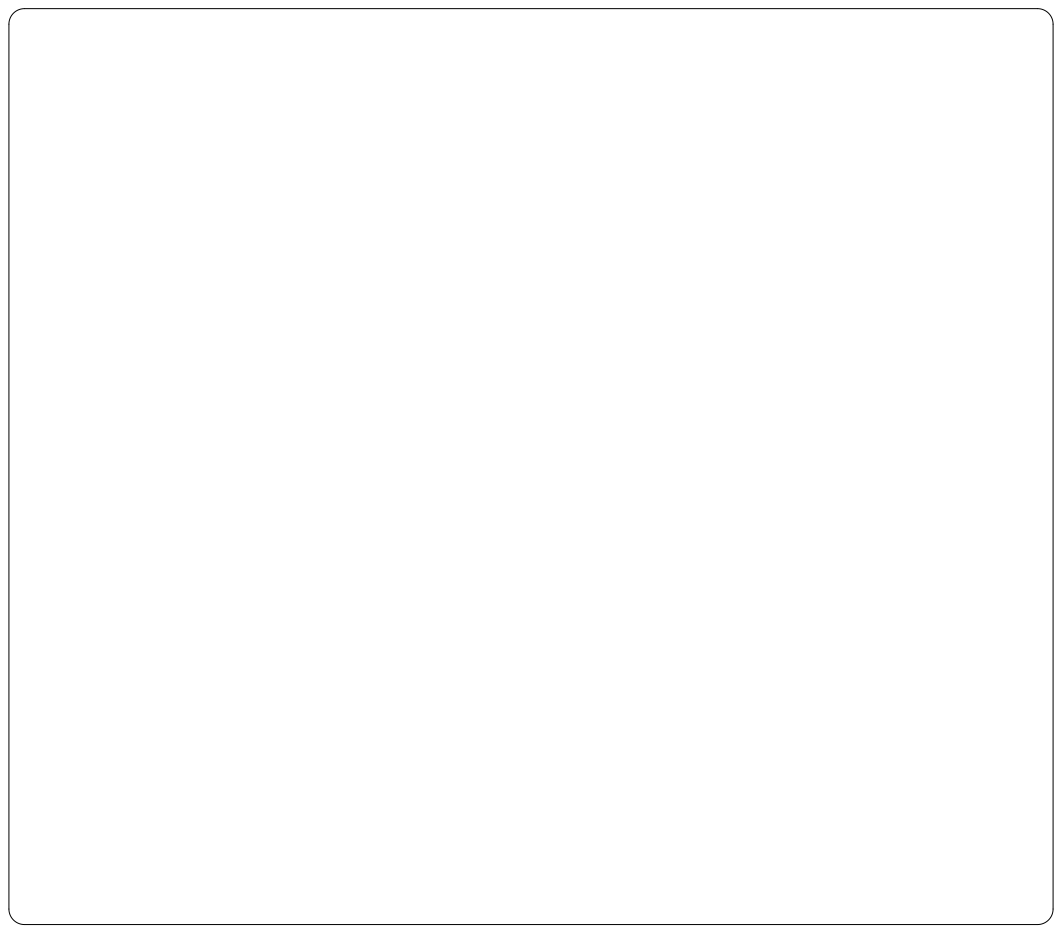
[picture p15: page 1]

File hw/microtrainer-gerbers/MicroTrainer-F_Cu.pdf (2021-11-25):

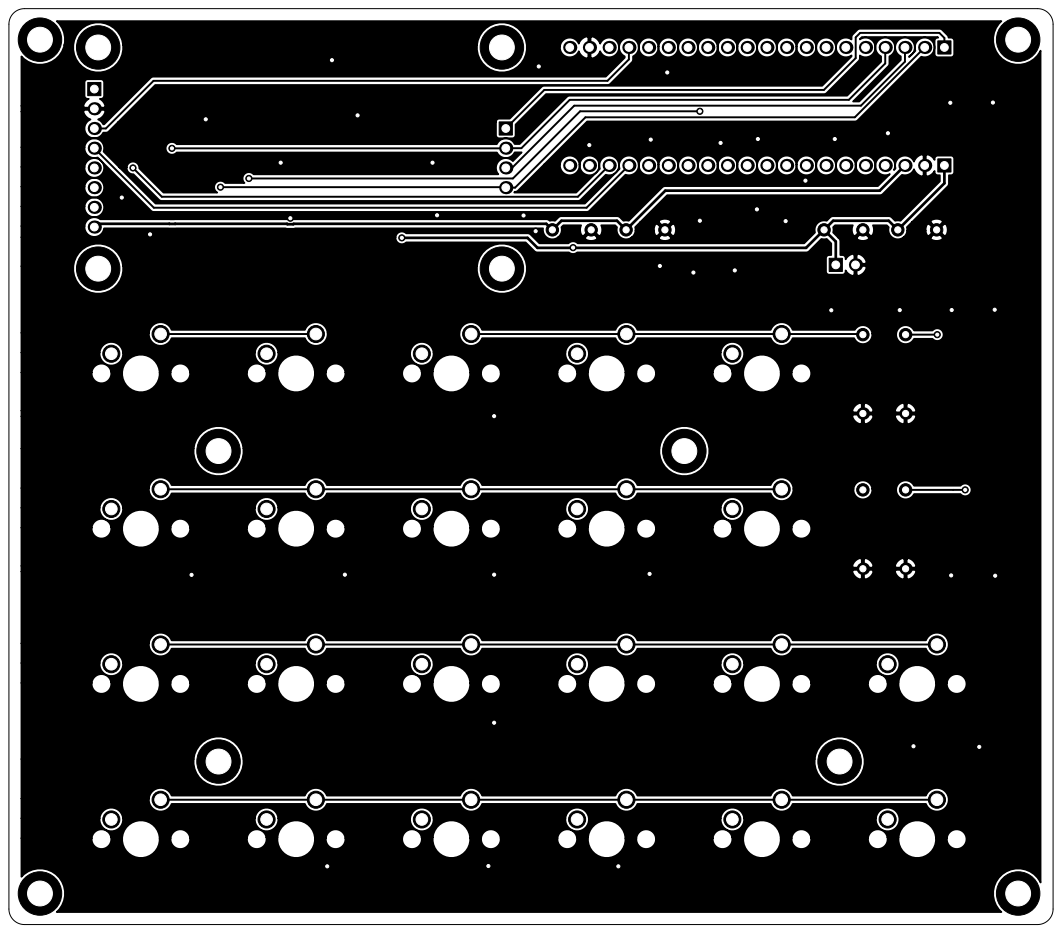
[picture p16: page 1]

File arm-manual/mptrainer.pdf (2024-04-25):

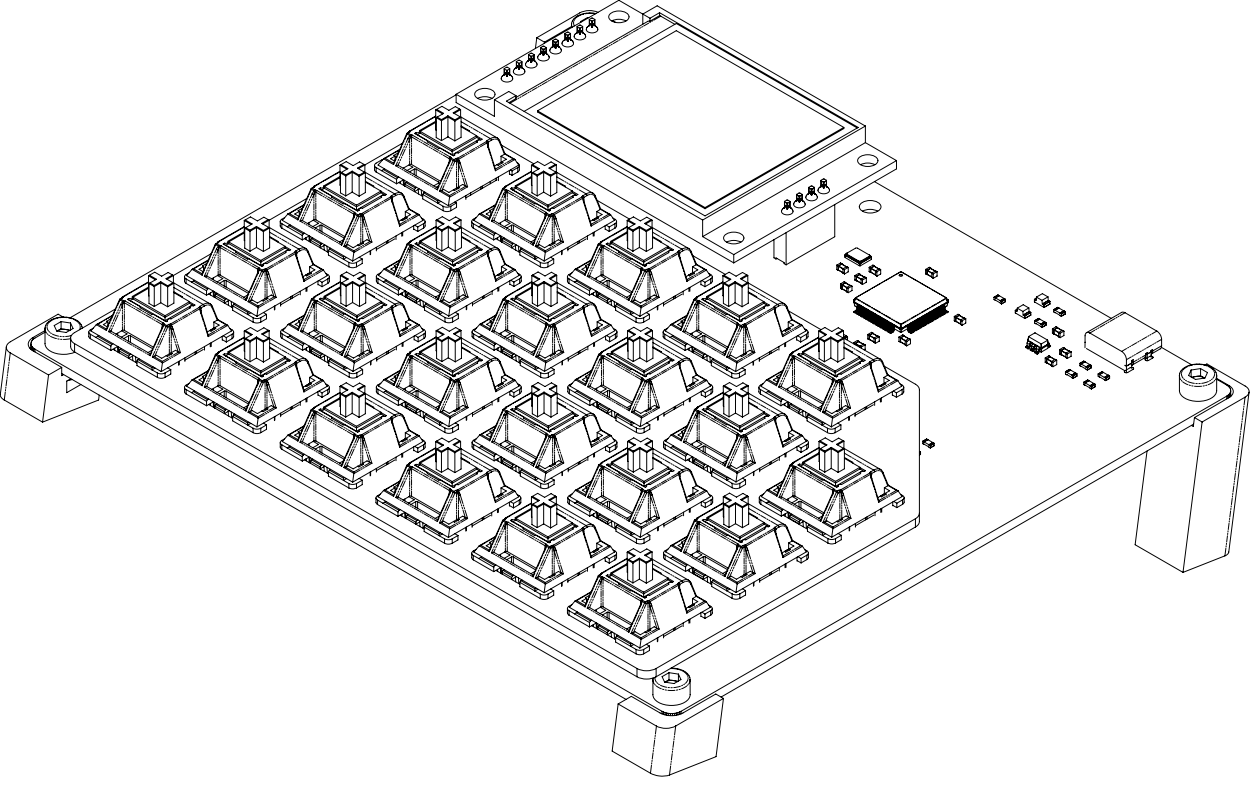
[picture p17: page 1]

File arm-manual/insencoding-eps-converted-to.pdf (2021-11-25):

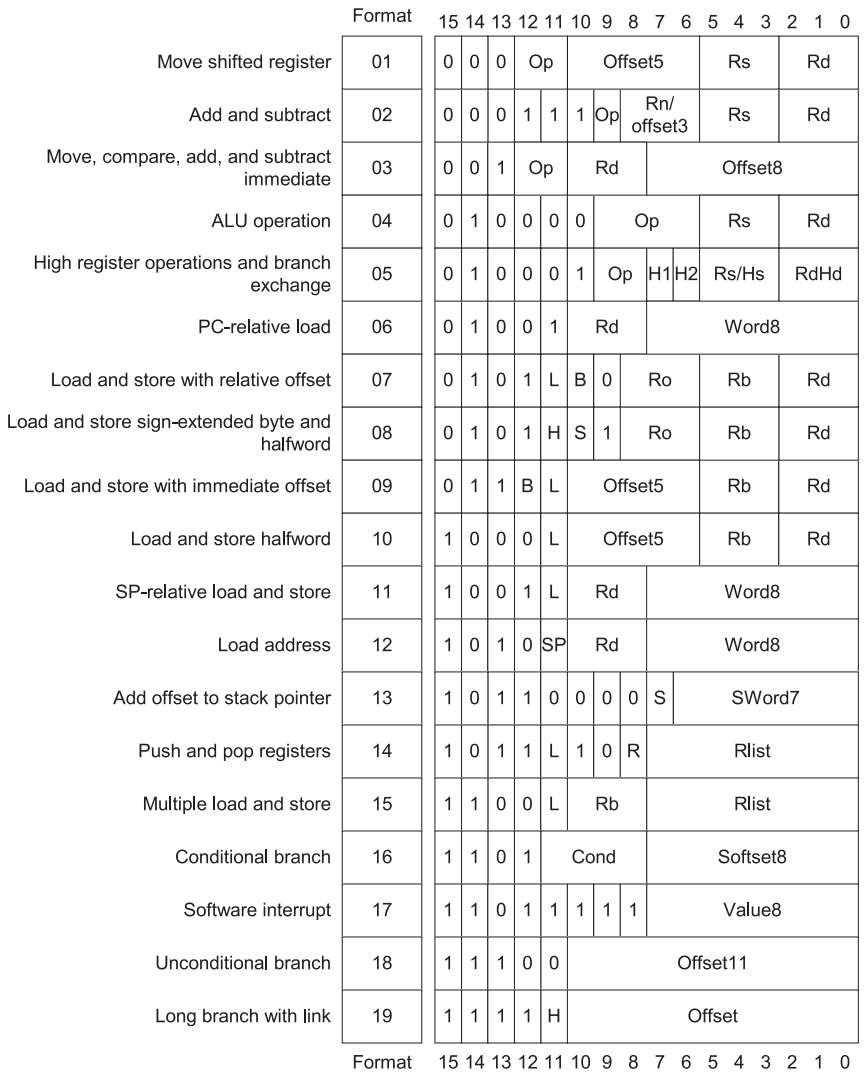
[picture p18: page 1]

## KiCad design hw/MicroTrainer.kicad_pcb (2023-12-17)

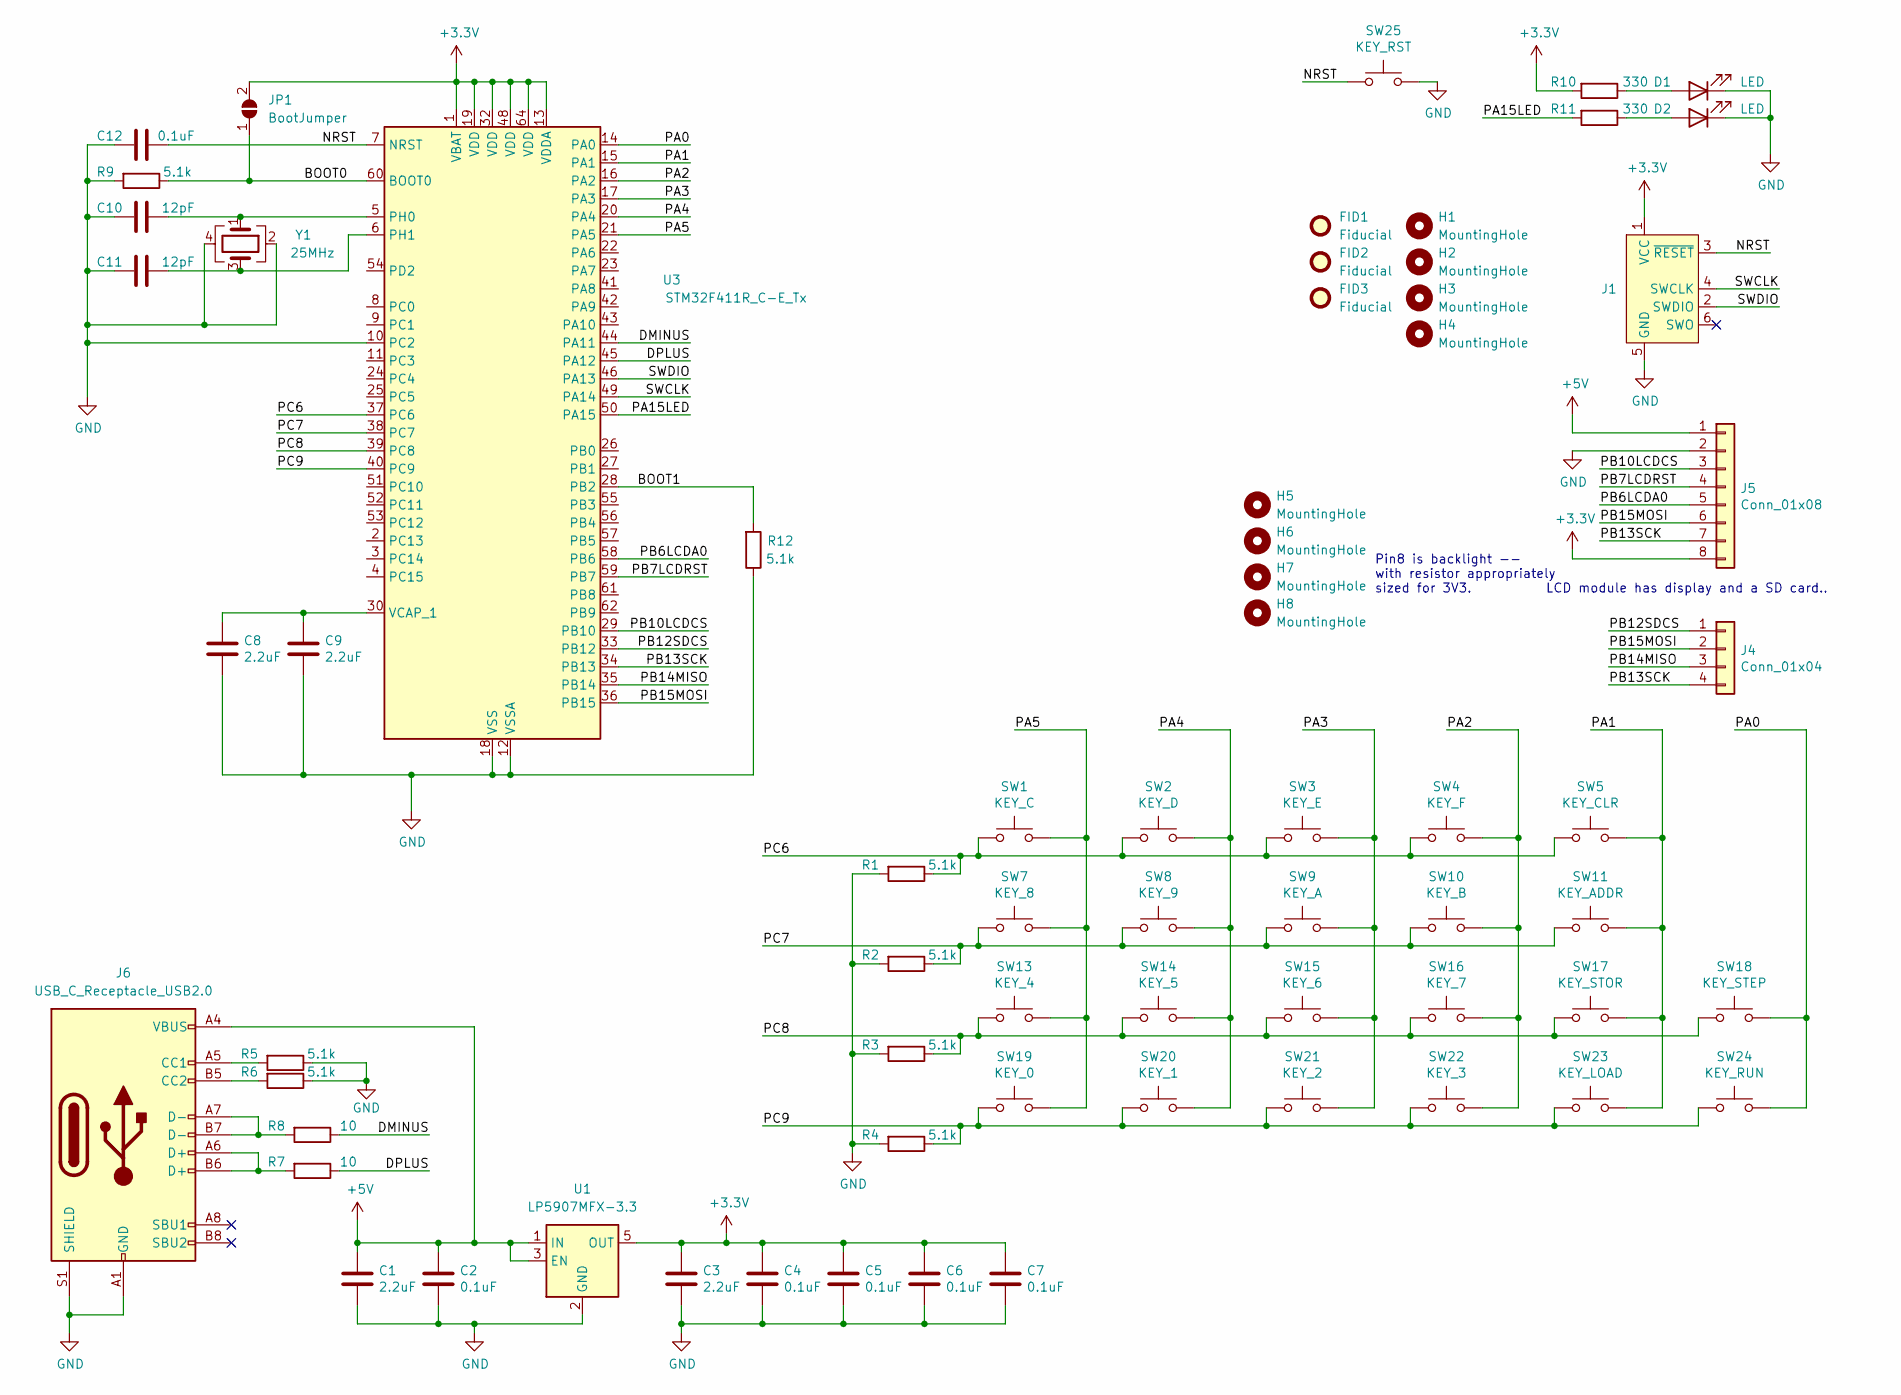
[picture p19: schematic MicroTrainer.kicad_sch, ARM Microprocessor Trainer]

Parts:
C1, C3, C8, C9: 2.2uF; C_0603_1608Metric; LCSC C23630
C2, C4, C5, C6, C7, C12: 0.1uF; C_0603_1608Metric; LCSC C14663
C10, C11: 12pF; C_0603_1608Metric; LCSC C38523
D1, D2: LED; LED_0805_2012Metric; LCSC C2297
FID1, FID2, FID3: Fiducial; Fiducial_1mm_Mask2mm
H1, H2, H3, H4, H5, H6, H7, H8: MountingHole; MountingHole_3.2mm_M3
J1: Conn_ARM_SWD_TagConnect_TC2030; Tag-Connect_TC2030-IDC-FP_2x03_P1.27mm_Vertical
J4: Conn_01x04; PinSocket_1x04_P2.54mm_Vertical
J5: Conn_01x08; PinSocket_1x08_P2.54mm_Vertical
J6: USB_C_Receptacle_USB2.0; USB_C_Receptacle_G-Switch_GT-USB-7010ASV; LCSC C2988369
JP1: BootJumper; SolderJumper-2_P1.3mm_Open_RoundedPad1.0x1.5mm
R1, R2, R3, R4, R5, R6, R9, R12: 5.1k; R_0603_1608Metric; LCSC C23186
R7, R8: 10; R_0603_1608Metric; LCSC C22859
R10, R11: 330; R_0603_1608Metric; LCSC C23138
SW1: KEY_C; SW_Cherry_MX_1.00u_PCB
SW2: KEY_D; SW_Cherry_MX_1.00u_PCB
SW3: KEY_E; SW_Cherry_MX_1.00u_PCB
SW4: KEY_F; SW_Cherry_MX_1.00u_PCB
SW5: KEY_CLR; SW_Cherry_MX_1.00u_PCB
SW7: KEY_8; SW_Cherry_MX_1.00u_PCB
SW8: KEY_9; SW_Cherry_MX_1.00u_PCB
SW9: KEY_A; SW_Cherry_MX_1.00u_PCB
SW10: KEY_B; SW_Cherry_MX_1.00u_PCB
SW11: KEY_ADDR; SW_Cherry_MX_1.00u_PCB
SW13: KEY_4; SW_Cherry_MX_1.00u_PCB
SW14: KEY_5; SW_Cherry_MX_1.00u_PCB
SW15: KEY_6; SW_Cherry_MX_1.00u_PCB
SW16: KEY_7; SW_Cherry_MX_1.00u_PCB
SW17: KEY_STOR; SW_Cherry_MX_1.00u_PCB
SW18: KEY_STEP; SW_Cherry_MX_1.00u_PCB
SW19: KEY_0; SW_Cherry_MX_1.00u_PCB
SW20: KEY_1; SW_Cherry_MX_1.00u_PCB
SW21: KEY_2; SW_Cherry_MX_1.00u_PCB
SW22: KEY_3; SW_Cherry_MX_1.00u_PCB
SW23: KEY_LOAD; SW_Cherry_MX_1.00u_PCB
SW24: KEY_RUN; SW_Cherry_MX_1.00u_PCB
SW25: KEY_RST; SW_Cherry_MX_1.00u_PCB
U1: LP5907MFX-3.3; SOT-23-5; LCSC C80670
U3: STM32F411R_C-E_Tx; LQFP-64_10x10mm_P0.5mm; LCSC C89374
Y1: 25MHz; Crystal_SMD_3225-4Pin_3.2x2.5mm; LCSC C9006

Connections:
+3V3: C3.1, C4.1, C5.1, C6.1, C7.1, J1.1 (VCC), J5.8, JP1.2 (B), R10.2, U1.5 (OUT), U3.1 (VBAT), U3.13 (VDDA), U3.19 (VDD), U3.32 (VDD), U3.48 (VDD), U3.64 (VDD)
+5V: C1.1, C2.1, J5.1, J6.A4 (VBUS), J6.A9 (VBUS), J6.B4 (VBUS), J6.B9 (VBUS), U1.1 (IN), U1.3 (EN)
/BOOT0: JP1.1 (A), R9.1, U3.60 (BOOT0)
/BOOT1: R12.2, U3.28 (PB2)
/DMINUS: R8.1, U3.44 (PA11)
/DPLUS: R7.1, U3.45 (PA12)
/NRST: C12.2, J1.3 (~RESET), SW25.1, U3.7 (NRST)
/PA0: SW18.2, SW24.2, U3.14 (PA0)
/PA1: SW5.2, SW11.2, SW17.2, SW23.2, U3.15 (PA1)
/PA2: SW4.2, SW10.2, SW16.2, SW22.2, U3.16 (PA2)
/PA3: SW3.2, SW9.2, SW15.2, SW21.2, U3.17 (PA3)
/PA4: SW2.2, SW8.2, SW14.2, SW20.2, U3.20 (PA4)
/PA5: SW1.2, SW7.2, SW13.2, SW19.2, U3.21 (PA5)
/PA15LED: R11.2, U3.50 (PA15)
/PB6LCDA0: J5.5, U3.58 (PB6)
/PB7LCDRST: J5.4, U3.59 (PB7)
/PB10LCDCS: J5.3, U3.29 (PB10)
/PB12SDCS: J4.1, U3.33 (PB12)
/PB13SCK: J4.4, J5.7, U3.34 (PB13)
/PB14MISO: J4.3, U3.35 (PB14)
/PB15MOSI: J4.2, J5.6, U3.36 (PB15)
/PC6: R1.1, SW1.1, SW2.1, SW3.1, SW4.1, SW5.1, U3.37 (PC6)
/PC7: R2.1, SW7.1, SW8.1, SW9.1, SW10.1, SW11.1, U3.38 (PC7)
/PC8: R3.1, SW13.1, SW14.1, SW15.1, SW16.1, SW17.1, SW18.1, U3.39 (PC8)
/PC9: R4.1, SW19.1, SW20.1, SW21.1, SW22.1, SW23.1, SW24.1, U3.40 (PC9)
/SWCLK: J1.4 (SWCLK), U3.49 (PA14)
/SWDIO: J1.2 (SWDIO), U3.46 (PA13)
GND: C1.2, C2.2, C3.2, C4.2, C5.2, C6.2, C7.2, C8.2, C9.2, C10.1, C11.1, C12.1, D1.1 (K), D2.1 (K), J1.5 (GND), J5.2, J6.A1 (GND), J6.A12 (GND), J6.B1 (GND), J6.B12 (GND), J6.S1 (SHIELD), R1.2, R2.2, R3.2, R4.2, R5.1, R6.1, R9.2, R12.1, SW25.2, U1.2 (GND), U3.10 (PC2), U3.12 (VSSA), U3.18 (VSS), U3.31 (VSS), U3.47 (VSS), U3.63 (VSS), Y1.2, Y1.4
unnamed: D1.2 (A), R10.1
unnamed: D2.2 (A), R11.1
unnamed: J6.A5 (CC1), R5.2
unnamed: J6.B5 (CC2), R6.2
unnamed: J6.A6 (D+), J6.B6 (D+), R7.2
unnamed: J6.A7 (D-), J6.B7 (D-), R8.2
unnamed: C10.2, U3.5 (PH0), Y1.1
unnamed: C11.2, U3.6 (PH1), Y1.3
unnamed: C8.1, C9.1, U3.30 (VCAP_1)

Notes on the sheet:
LCD module has display and a SD card..
Pin8 is backlight -- with resistor appropriately sized for 3V3.

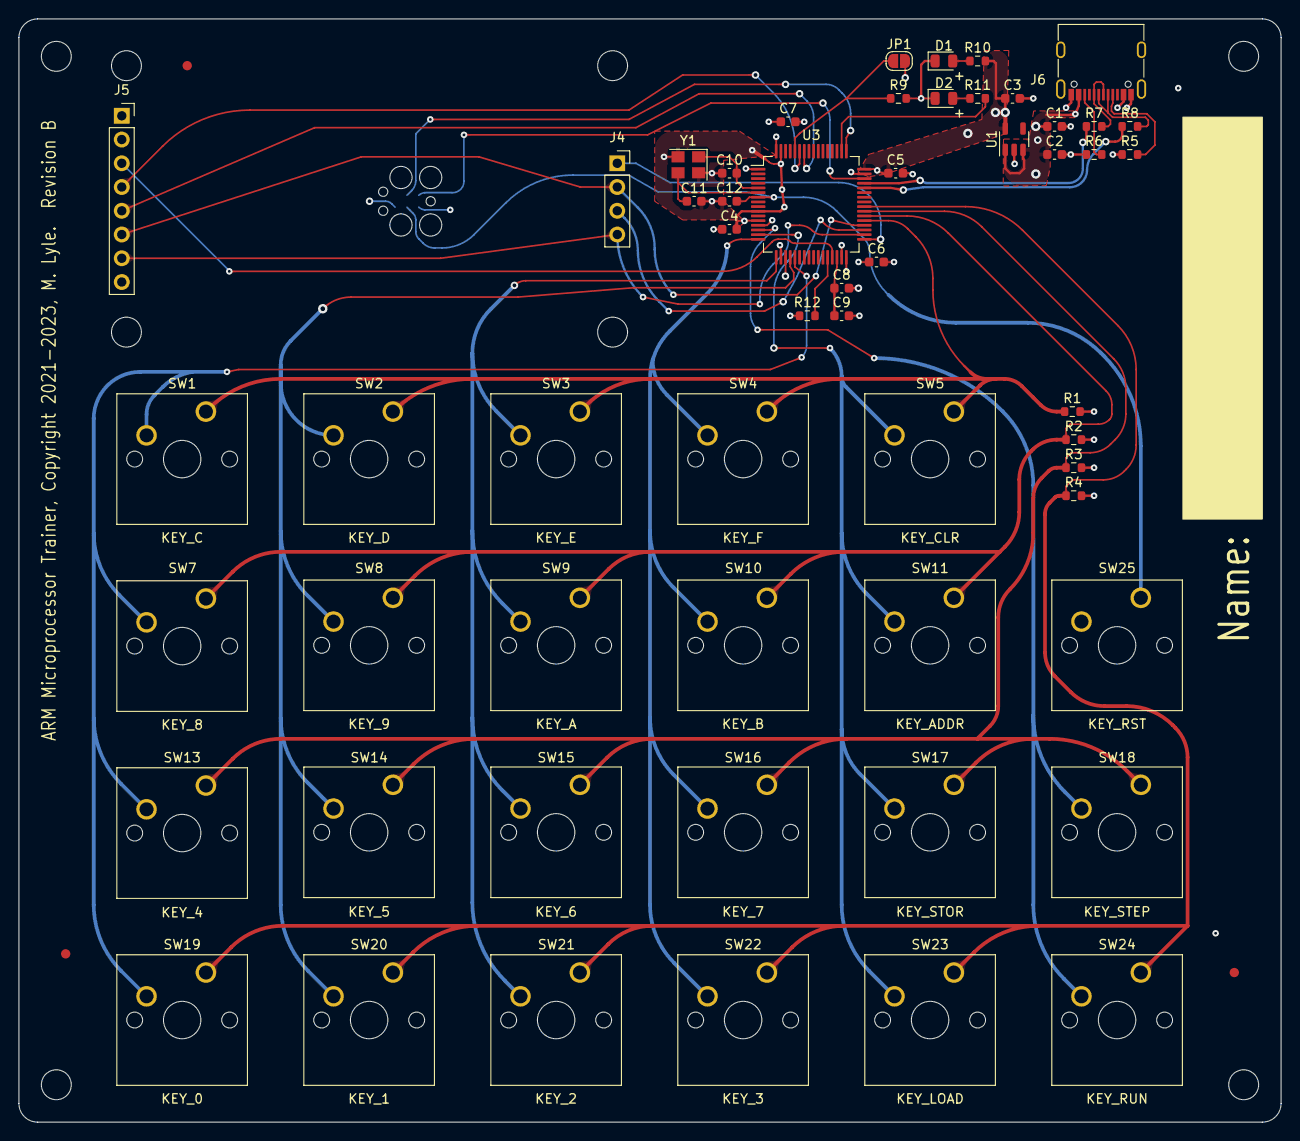
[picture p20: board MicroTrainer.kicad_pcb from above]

Board: 4 copper layers, 135.0 x 118.0 mm, 68 parts (1 on the bottom side), 37 nets.

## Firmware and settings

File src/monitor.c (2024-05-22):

#include <stdbool.h>
#include <string.h>
#include <unistd.h>

#include <led.h>
#include <lcdutil.h>
#include <save.h>
#include <stringutil.h>
#include <thumbdisasm.h>

#include <armdio.h>

#include <stm32f4xx_rcc.h>
#include <systick_handler.h>

#include <delayutil.h>
#include <randomutil.h>
#include <matrix.h>
#include <console.h>

#include <ctype.h>

#ifndef MIN
#define MIN(a,b) \
	({ __typeof__ (a) _a = (a); \
	 __typeof__ (b) _b = (b); \
	 _a < _b ? _a : _b; })
#endif

#define NELEMENTS(x) (sizeof(x) / sizeof(*(x)))

struct __attribute__((packed)) ContextStateFrame_s {
	uint32_t r[4];
	uint32_t r12;
	uint32_t lr;
	uint32_t return_address;
	uint32_t xpsr;
};

struct __attribute__((packed)) EnhancedContextStateFrame_s {
	struct ContextStateFrame_s csf;

	uint32_t rh[4];
};

/* Single step state machine */
enum progrun_state {
	STATE_STOPPED,
	STATE_STEP,
	STATE_RUN
} prog_state;

/* Flag if something went wrong with oscillator startup.
 * Right now this causes us to panic, but there's no firm reason for
 * this -- we could work fine from RC oscillator.
 */
static bool osc_err = false;

/* State machine for keypad editing addresses/values */
static bool editing_addr = true;
static uint8_t edit_pos = 0;
static uint32_t edit_addr = 0;
static uint32_t loaded_addr = 0;
static uint32_t edit_val = 0;

/* Last save slot loaded or written to.  Used to prevent warning when
 * saving to same slot over and over.
 */
static int8_t save_slot = -1;

/* Whether a store has been done and we should thus warn on loading */
static bool unsafe_to_load = false;

/* The current stack frame.  This is a global so that we can redraw
 * the screen without passing this everywhere.
 */
static struct EnhancedContextStateFrame_s *global_frame;

/* Which screen of registers should be shown right now */
static int register_screen = 0;

/* Flag: Show registers in decimal instead of hex */
static bool show_decimal = false;

/* Flag: Don't wait for screen redraws to proceed with next instruction
 * in run mode.  Still a tiny fraction of native speed, but dozens of
 * times faster than being synchronous to display refresh.
 */
static bool run_fast = false;

/* Stores any key (other than step/run) hit while a program is running.
 * SVC1A can be used to retrieve this key
 */
static enum matrix_keys running_key;

/* Special variable to detect that we have been through a reset and we
 * are requested to go to loader.   Explained in comment above
 * check_for_loader()
 */
#define GO_TO_LOADER_MAGIC 0xb00fbeef
static uint32_t switch_to_loader __attribute__ ((section (".noinit")));

int snake();

/* Shims for C handlers for SVCall, DebugMon, etc.  These get the
 * ContextStateFrame into an argument for C code to use.
 */
__attribute__((naked))
void SVCall_Handler(void)
{
	__asm volatile(
			"tst lr, #4 \n"	       /* Determine stack used, put appropriate ptr in R0 */
			"ite eq \n"
			"mrseq r0, msp \n"
			"mrsne r0, psp \n"
			"b SVCall_Handler_c \n"
	);
}

void DebugMon_Handler() __attribute__((interrupt("IRQ")));

__attribute__((naked))
void DebugMon_Handler(void)
{
	__asm volatile(
			"tst lr, #4 \n"
			"ite eq \n"
			"mrseq r0, msp \n"
			"mrsne r0, psp \n"
			"push {r4, r5, r6, r7, lr} \n"
			"bl DebugMon_Handler_c \n"
			"pop {r4, r5, r6, r7, pc} \n");
}

/* Is this in first 32k of ram, and 2-byte aligned? */
static bool address_valid_for_write(uint32_t addr)
{
	if (addr & 1) {
		return false;
	}

	if ((addr & 0xffff8000) == 0x20000000) {
		return true;
	}

	return false;
}

/* Is this in RAM or flash? */
static bool address_valid_for_read(uint32_t addr)
{
	if (address_valid_for_write(addr)) {
		return true;
	}

	if ((addr & 0xffff0000) == 0x20000000) {
		return true;
	}

	if ((addr & 0xffc0000) == 0x08000000) {
		return true;
	}

	return false;
}

/* Disassembles and outputs a short listing around the current
 * address.
 */
static inline void blit_insn(int y, uint32_t addr, bool highlighted)
{
	const char *tmp;

	lcd_blit_box(0, y, 159, y+13, 0, 0, 0);

	// 12345678
	// AA IIII
	// 5 pixel wide font, 40 pixels
	// 120 pixels remain for 13 chars * 9 = 117

	tmp = to_hex8(addr);

	uint8_t l = highlighted ? 15 : 8;

	lcd_blit_smdigit_string(tmp, 0, y, l, l, l/4,
			0, 0, 0);

	if (!address_valid_for_read(addr)) {
		lcd_blit_smdigit_string("????", 15, y, l, l/2, l/2,
				0, 0, 0);
	} else {
		uint16_t insn = *((uint16_t *) addr);
		tmp = to_hex16(insn);

		lcd_blit_smdigit_string(tmp, 15, y, l/4, l/2, l,
				0, 0, 0);

		char decoded_insn[14];

		decode_insn(decoded_insn, addr, insn);

		lcd_blit_string(decoded_insn, 40, y, l, l, l,
				0, 0, 0);
	}
}

static inline void blit_insns()
{
	uint32_t addr = loaded_addr - 2;

	for (int i=0; i<4; i++) {
		blit_insn(58+i*13, addr, addr == loaded_addr);

		addr += 2;
	}
}

static inline void blit_cursor_lines(int y, uint8_t r, uint8_t g,
		uint8_t b)
{
	lcd_blit_horiz(0, y, 159, r, g, b);
	lcd_blit_horiz(0, y+1, 159, r, g, b);
	lcd_blit_horiz(0, y+2, 159, r, g, b);
}

/* LCD routines for keeping a cursor on the address/value row */
static inline void clear_cursor(int y)
{
	blit_cursor_lines(y, 0, 0, 0);
}

static inline void blit_cursor(int x, int y)
{
	clear_cursor(y);
	lcd_blit_horiz(x+3, y, x+5, 15, 0, 0);
	lcd_blit_horiz(x+2, y+1, x+6, 15, 0, 0);
	lcd_blit_horiz(x, y+2, x+8, 15, 0, 0);
}

/* Blitting the address/value row */
static inline void blit_addrval()
{
	const char *addrhex = to_hex32(edit_addr);
	lcd_blit_string(addrhex, 0, 112, 0, 0, 0, 15, 15, 15);

	const char *inshex = to_hex16(edit_val);
	lcd_blit_string(inshex, 75, 112, 0, 0, 0, 8, 8, 15);

	const char *mnem = get_mnem(edit_val);

	lcd_blit_string(mnem, 123, 112, 15, 15, 15, 0, 0, 0);

	if (prog_state == STATE_STOPPED) {
		if (editing_addr) {
			blit_cursor(9*edit_pos, 125);
		} else {
			blit_cursor(72 + 9*(edit_pos-4), 125);
		}
	} else {
		/* Shade bottom of screen dark green when running */
		blit_cursor_lines(125, 0, 9, 0);
	}
}

/* If there's room, display condition codes on the screen.
 * Also show the hidden "fast" flag
 */
static inline void blit_flag_chars(int flag, int x, int y, char f, char g)
{
	if (flag) {
		lcd_blit_char(g, x, y, 15, 9, 9, 4, 0, 0);
	} else {
		lcd_blit_char(f, x, y, 8, 8, 8, 0, 0, 0);
	}
}

static inline void blit_flag(int flag, int x, int y, char f)
{
	blit_flag_chars(flag, x, y, f, toupper(f));
}

/* Implementation of displaying registers on the LCD */
static inline void blit_register_name(int lineno, const char *regn,
		uint32_t val)
{
	const char *reg_val;

	if (show_decimal) {
		reg_val = to_decimal32(val);
	} else {
		reg_val = to_hex32(val);
	}

	lcd_blit_string(regn, 0, 58+lineno*13, 15, 2, 2, 0, 0, 0);

	// fill the space to end of line
	lcd_blit_box(18, 58+lineno*13, 159, 70+lineno*13, 0, 0, 0);

	lcd_blit_string(reg_val, 24, 58+lineno*13, 15, 15, 15, 5, 0, 0);
}

static inline void blit_register(int lineno, int regnum, uint32_t val)
{
	char regn[3]={ 'r', '0'+regnum, '\0' };

	blit_register_name(lineno, regn, val);
}

static inline void blit_registers(struct EnhancedContextStateFrame_s *frame,
		int what_to_show)
{
	uint32_t xpsr = frame->csf.xpsr;

	if (what_to_show == 0) {
		for (int i=0; i<4; i++) {
			blit_register(i, i, frame->csf.r[i]);
		}
	} else if (what_to_show == 1) {
		/* Display registers r4-r7 instead */
		for (int i=0; i<4; i++) {
			blit_register(i, i+4, frame->rh[i]);
		}
	} else if (what_to_show == 2) {
		blit_register_name(0, "12", frame->csf.r12);
		blit_register_name(1, "lr", frame->csf.lr);
		blit_register_name(2, "rt", frame->csf.return_address);
		blit_register_name(3, "xp", xpsr);
	} else {
		blit_insns();
	}

	if ((what_to_show < 3) && (!show_decimal)) {
		blit_flag_chars(run_fast, 114, 62, ' ', 'F');
		blit_flag(xpsr & 0x80000000, 123, 62, 'n');
		blit_flag(xpsr & 0x40000000, 132, 62, 'z');
		blit_flag(xpsr & 0x20000000, 141, 62, 'c');
		blit_flag(xpsr & 0x10000000, 150, 62, 'v');
	}
}

/* Blit the entire screen.  Block until we can begin scanning it */
static inline void blit_screen()
{
	blit_addrval();
	blit_registers(global_frame, register_screen);
	lcd_refresh();
}

static inline void memcpy_snake()
{
	uint16_t insns[] = {
		0x2053,
		0x214e,
		0x2241,
		0x234b,
		0xdf45,
		0xe7f9
	};

	edit_addr = 0x20000000;
	memcpy((void *) 0x20000000, insns, sizeof(insns));
}


/* Logic to load from memory, and update cursors */
static bool perform_load_impl()
{
	if ((edit_addr == 0x8028616) ||
			(edit_addr == 0x80286160)) {
		memcpy_snake();
	}

	edit_addr &= 0xfffffffe;	/* Align */

	if (!address_valid_for_read(edit_addr)) {
		edit_val = 0x0bad;
		return false;
	}

	loaded_addr = edit_addr;

	edit_val = *((uint16_t *) edit_addr);
	edit_pos = 4;

	editing_addr = false;

	return true;
}

/* This routine is invoked once for each instruction run.
 * It's the actual meat of the debug monitor, displaying everything
 * on the screen and making the system work-- though a lot of the
 * magic happens in keyboard callbacks. */
void DebugMon_Handler_c(struct EnhancedContextStateFrame_s *frame)
{
	if ((frame->csf.return_address & 0xff000000) == 0x08000000) {
		/* Short circuit when not running from ram */
		return;
	}

	global_frame = frame;

	edit_addr = frame->csf.return_address;

	/* Get the contents of edit_addr, and set up cursors */
	perform_load_impl();

	editing_addr = true;
	edit_pos = 0;

	if (run_fast) {
		/* In run fast mode, we scan the keys for each
		 * instruction, but only blit the screen if the
		 * screen is idle (or we're stopped).
		 */
		do {
			matrix_scanall();

			if (lcd_is_ready()) {
				blit_screen();
			}
		} while (prog_state == STATE_STOPPED);
	} else {
		/* In normal mode, we wait for the LCD to be
		 * ready and then blit it.
		 */
		do {
			while (!lcd_is_ready()) {
				matrix_scanall();
			}

			blit_screen();
		} while (prog_state == STATE_STOPPED);
	}

	/* If we're single stepping, next time we're here we should
	 * stop.
	 */
	if (prog_state == STATE_STEP) {
		prog_state = STATE_STOPPED;
	}

	if (edit_addr != frame->csf.return_address) {
		frame->csf.return_address = edit_addr;
	}
}

/* Update the core debug flags to disable/enable single step. */

static inline void singlestep_disable()
{
	CoreDebug->DEMCR = CoreDebug_DEMCR_MON_EN_Msk |
		CoreDebug_DEMCR_TRCENA_Msk;
}

static inline void singlestep_enable()
{
	CoreDebug->DEMCR = CoreDebug_DEMCR_MON_EN_Msk |
		CoreDebug_DEMCR_TRCENA_Msk |
		CoreDebug_DEMCR_MON_STEP_Msk;
}

/* Handle a keypress of a digit */
static void edit_key_digit(int digit)
{
	uint32_t *edited = &edit_val;

	if (editing_addr) {
		edited = &edit_addr;
	}

	uint32_t mask = 0xf0000000;

	mask >>= (edit_pos*4);

	*edited = ((*edited) & (~mask)) | (digit << (4*(7-edit_pos)));

	edit_pos++;
	if (edit_pos > 7) {
		edit_pos = 7;
	}
}

/* This handle a load keypress-- including advancing in memory if
 * load is hit repeatedly */
static void perform_load(bool repeated)
{
	if ((!editing_addr) && (repeated)) {
		// if load pressed consecutively, increment address
		edit_addr += 2;
	}

	if (!perform_load_impl()) {
		lcd_signalerror();
	}
}

static void perform_store()
{
	if (!address_valid_for_write(edit_addr)) {
		lcd_signalerror();
		return;
	}

	if (editing_addr) {
		lcd_signalerror();
		return;
	}

	unsafe_to_load = true;

	*((uint16_t *) edit_addr) = edit_val;
	edit_addr += 2;

	perform_load(false);
}

static void branch_calculator()
{
	if (!perform_load_impl()) {
		console_str("\r\nInvalid srcaddr\r\n");
		lcd_signalerror();
		return;
	}

	delay_ms(100);	/* Hack: Wait for B key to settle */

	console_str("\r\n\r\nBranch Calculator\r\nTarget: ");

	uint32_t target = console_read_number(16);

	if (target & 1) {
		console_str("\r\nShould be even\r\n");
		return;
	}

	uint32_t offset = target - edit_addr;

	offset /= 2;

	offset -= 2;

	if (offset & 0x40000000) {
		if (offset < 0x7ffff800) {
			console_str("\r\nToo far\r\n");
			return;
		}
	} else if (offset > 0x7ff) {
		console_str("\r\nToo far\r\n");
		return;
	}

	console_number_16_short(offset & 0x7ff);

	console_str(" cond: ");

	if (offset & 0x40000000) {
		if (offset < 0x7fffff00) {
			console_str("XX");
		} else {
			console_number_16_short(offset & 0xff);
		}
	} else if (offset > 0xff) {
		console_str("XX");
	} else {
		console_number_16_short(offset & 0xff);
	}

	console_str("\r\nhit store or edit\r\n");

	edit_val = 0xe000 | (offset & 0x7ff);
}

static bool do_confirmation()
{
	console_str("\r\nType 1+ST if sure\r\n");
	uint32_t num = console_read_number(10);
	if (num != 1) {
		console_str("CANCELED");
		return false;
	}

	return true;
}

static void do_save(int slot)
{
	console_str("\r\nSave #");
	console_number_10_nocr(slot);

	console_str(": ");

	if (save_slot != slot) {
		if (!do_confirmation()) {
			return;
		}
	}


	if (save_writesave(slot)) {
		console_str("SAVED");

		save_slot = slot;
		unsafe_to_load = false;
	} else {
		console_str("FAIL");
	}

	perform_load_impl();
}

static void do_load(int slot)
{
	console_str("\r\nLoad #");
	console_number_10_nocr(slot);

	console_str(": ");

	if (unsafe_to_load) {
		if (!do_confirmation()) {
			return;
		}
	}

	if (save_readsave(slot)) {
		console_str("LOADED");
		save_slot = slot;

		unsafe_to_load = false;
	} else {
		console_str("FAIL");
	}

	edit_addr = 0x20000000;

	perform_load_impl();
}

/* This is the main keypress handler-- invoked when the code
 * is stopped.
 */
static void edit_key(enum matrix_keys key, bool pressed)
{
	static bool load_held;
	static bool did_combination;

	static enum matrix_keys last_key;

	/* We don't really care about released keys, except load.
	 * Load is processed on release instead of when it is
	 * struck.  This lets us use load as a modifier key with
	 * additional shortcuts.
	 *
	 * Why load as a modifier?  Because it's nice and harmless,
	 * usually.  And because it's the key that seems best to
	 * delay until release.
	 */
	if (!pressed) {
		if (key == key_load) {
			if (!did_combination) {
				perform_load(last_key == key_load);

				last_key = key;
			}

			load_held = false;
			did_combination = false;
		}

		return;
	}

	/* Everything below this point is for when the key is
	 * depressed (rather than released).
	 *
	 * First, handle the case where load is held down:
	 */
	if (load_held) {
		did_combination = true;
		switch (key) {
			case key_0:
				register_screen = 0;
				break;
			case key_1:
				register_screen = 1;
				break;
			case key_2:
				register_screen = 2;
				break;
			case key_3:
				register_screen = 3;
				break;

			case key_4:
			case key_5:
			case key_6:
				/* This is necessary because the
				 * routine may take over the keypad
				 * and doesn't see the release of LOAD
				 */
				load_held = false;
				do_save(key - key_4);
				break;

			case key_8:
			case key_9:
				load_held = false;
				do_load(key - key_8);
				break;

			case key_a:
				load_held = false;
				do_load(2);
				break;

			case key_b:
				load_held = false;

				branch_calculator();
				break;

			case key_d:
				show_decimal = !show_decimal;
				break;
			case key_f:
				run_fast = !run_fast;
				break;

			case key_clr:
				console_clearscreen();
				lcd_blit_string("Hold LOAD and hit", 0, 1, 15, 15, 0, 0, 0, 0);
				lcd_blit_string("0-3:pick regview", 0, 14, 0, 15, 15, 0, 0, 0);
				lcd_blit_string("4-6:save 8-a:load", 0, 27, 0, 15, 15, 0, 0, 0);
				lcd_blit_string("b:b-helper d:dec", 0, 40, 0, 15, 15, 0, 0, 0);
				break;

			default:
				break;
		}
	} else {
		/* Key is pressed, and it's not modified by load
		 * being held.  This is the straightforward case */
		switch (key) {
			case key_clr:
				if (edit_pos != 0) {
					edit_pos--;
				} else {
					lcd_signalerror();
				}

				if ((!editing_addr) && (edit_pos < 4)) {
					edit_pos = 4;
					lcd_signalerror();
				}
				break;
			case key_addr:
				if (editing_addr) {
					perform_load(false);
				} else {
					editing_addr = true;
					edit_pos = 0;
				}
				break;
			case key_0:
			case key_1:
			case key_2:
			case key_3:
			case key_4:
			case key_5:
			case key_6:
			case key_7:
			case key_8:
			case key_9:
				edit_key_digit(key-key_0);
				break;
			case key_a:
			case key_b:
			case key_c:
			case key_d:
			case key_e:
			case key_f:
				edit_key_digit(key-key_a + 10);
				break;
			case key_load:
				load_held = true;
				// actual loads are performed on
				// release
				return;
			case key_store:
				perform_store();
				break;
			default:
				break;
		}
	}

	last_key = key;
}

static void monitor_key_changed(enum matrix_keys key, bool pressed)
{
	random_blendseed(systick_cnt);

	switch (key) {
		case key_run:
			if (pressed) {
				if (prog_state != STATE_RUN) {
					prog_state = STATE_RUN;
				} else {
					prog_state = STATE_STOPPED;
				}
			}
			break;
		case key_step:
			if (pressed) {
				prog_state = STATE_STEP;
			}
			break;
		default:
			if (prog_state == STATE_STOPPED) {
				edit_key(key, pressed);
			} else {
				if (pressed) {
					running_key = key;
				}
			}
			break;
	};
}
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
int main()
{
	if (switch_to_loader == GO_TO_LOADER_MAGIC) {
		switch_to_loader = 0;
		go_to_loader();
	}

	program_clocks();

	diagnostic_clockout();

	/* This ordering is necessary to allow systick and syscall to
	** be prioritized over debugmonitor.  Effectively this means that
	** single step does not follow them and that systick is highest
	** priority.
	**
	** Note the monitor immediately returns when PC is in flash.
	** So this is not required for correctness, but it is a significant
	** performance difference.
	*/
	NVIC_SetPriority(DebugMonitor_IRQn, 2);
	NVIC_SetPriority(SVCall_IRQn, 1);
	NVIC_SetPriority(SysTick_IRQn, 0);

#ifdef OLD_HW
	led_init_pin(GPIOC, GPIO_Pin_13, true);
#else
	led_init_pin(GPIOA, GPIO_Pin_15, true);
#endif

	if (osc_err) {
		led_panic("oscfail");
	}

	matrix_init();

	/* Check for key held at startup */
	matrix_set_callback(check_for_loader);
	matrix_scanall();

	lcd_init();

	if (switch_to_loader == GO_TO_LOADER_MAGIC) {
		for (int i = 0; i<8; i++) {
			lcd_blit_string("going to loader", 1+i*3, 9+13*i, 15-(i*2), 0, (i*2), 0, 0, 0);
		}
		lcd_refresh();

		while (!lcd_is_ready());
		NVIC_SystemReset();
	}

	lcd_blit_string("MPTrainer V0.5", 0, 1, 15, 15, 0, 0, 0, 0);
	lcd_blit_string("Copyright", 0, 27, 0, 15, 15, 0, 0, 0);
	lcd_blit_string("2021-24 M Lyle", 0, 40, 0, 15, 15, 0, 0, 0);

	/* Invoke monitor */
	matrix_set_callback(monitor_key_changed);
	singlestep_enable();
	code_invoke(0x20000000);
}

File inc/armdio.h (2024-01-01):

/* This STM32 GPIO driver by Michael Lyle is marked with CC0 1.0 Universal.
 * To view a copy of this license, visit
 * http://creativecommons.org/publicdomain/zero/1.0
 */

#ifndef __ARM_DIO_H
#define __ARM_DIO_H

#include <stdint.h>
#include <stdbool.h>

#if defined(STM32F4XX)
#include <stm32f4xx.h>
#include <stm32f4xx_gpio.h>

enum DIODriveStr {
	DIO_DRIVE_WEAK = 0,
	DIO_DRIVE_LIGHT,
	DIO_DRIVE_MEDIUM,
	DIO_DRIVE_STRONG
};
#elif defined(STM32F30X) || defined (STM32F0XX)
enum DIODriveStr {
	DIO_DRIVE_WEAK = 0,
	DIO_DRIVE_LIGHT = 0,
	DIO_DRIVE_MEDIUM = 1,
	DIO_DRIVE_STRONG = 3
};
#elif defined(STM32F10X_MD)
enum DIODriveStr {
	DIO_DRIVE_WEAK = 2,	// "2MHz"
	DIO_DRIVE_LIGHT = 1,	// "10MHz"
	DIO_DRIVE_MEDIUM = 1,
	DIO_DRIVE_STRONG = 3	// "50MHz"
};
#else
#error Unknown target
#endif

enum DIOPinFunc {
	DIO_PIN_INPUT = 0,
	DIO_PIN_OUTPUT = 1,
	DIO_PIN_ALTFUNC_IN = 2,
	DIO_PIN_ALTFUNC_OUT = 3,
	DIO_PIN_ANALOG = 4
};

enum DIOPull {
	DIO_PULL_NONE = 0,
	DIO_PULL_UP,
	DIO_PULL_DOWN
};

typedef uint32_t DIOTag_t;
typedef uint64_t DIOInitTag_t;

#define DIO_NULL ((uintptr_t) 0)

/**
 * @brief Initializes a GPIO per an inittag.
 *
 * @param[in] t The DIO init tag.  Created by ORing together a GPIO
 * specifier and one of INIT_DIO_INPUT, INIT_DIO_OUTPUT, and
 * INIT_DIO_ALTFUNC_OUT.
 */
void DIOInit(DIOInitTag_t t);

/**
 * @brief Configures a GPIO as alternate function output.
 *
 * @param[in] t The GPIO specifier tag (created with e.g. GPIOA_DIO(3) )
 * @param[in] alt_func The alternate function specifier.
 * @param[in] openDrain true for open-collector + pull-up semantics
 * @param[in] DIODriveStrength The drive strength to use for the GPIO
 */
static inline void DIOSetAltfuncOutput(DIOTag_t t, int alt_func,
		bool openDrain, enum DIODriveStr strength);

/**
 * @brief Configures a GPIO as alternate function input.
 *
 * @param[in] t The GPIO specifier tag (created with e.g. GPIOA_DIO(3) )
 * @param[in] alt_func The alternate function specifier.
 * @param[in] pull Pullup/Pulldown configuration.
 */
static inline void DIOSetAltfuncInput(DIOTag_t t, int alt_func,
		enum DIOPull pull);

/**
 * @brief Configures a GPIO as analog.  Disables pullups/pulldowns, etc.
 *
 * @param[in] t The GPIO specifier tag (created with e.g. GPIOA_DIO(3) )
 */
static inline void DIOSetAnalog(DIOTag_t t);

/**
 * @brief Configures a GPIO as an output.
 * @param[in] t The GPIO specifier tag (created with e.g. GPIOA_DIO(3) )
 * @param[in] openDrain true for open-collector + pull-up semantics
 * @param[in] DIODriveStrength The drive strength to use for the GPIO
 * @param[in] firstValue Whether it should be initially driven high or low.
 */
static inline void DIOSetOutput(DIOTag_t t, bool openDrain,
		enum DIODriveStr strength, bool firstValue);

/**
 * @brief Toggles an output GPIO to the opposite level.
 * @param[in] t The GPIO specifier tag
 */
static inline void DIOToggle(DIOTag_t t);

/**
 * @brief Sets an output GPIO high.
 * @param[in] t The GPIO specifier tag
 */
static inline void DIOHigh(DIOTag_t t);

/**
 * @brief Sets an output GPIO low.
 * @param[in] t The GPIO specifier tag
 */
static inline void DIOLow(DIOTag_t t);

/**
 * @brief Sets an output GPIO to a chosen logical level.
 * @param[in] t The GPIO specifier tag
 * @param[in] high Whether the GPIO should be high.
 */
static inline void DIOWrite(DIOTag_t t, bool high);

/**
 * @brief Configures a GPIO as an input.
 * @param[in] t The GPIO specifier tag (created with e.g. GPIOA_DIO(3) )
 * @param[in] pull Pullup/Pulldown configuration.
 */
static inline void DIOSetInput(DIOTag_t t, enum DIOPull pull);

/**
 * @brief Reads a GPIO logical value.
 * @param[in] t The GPIO specifier tag
 * @retval True if the GPIO is high; otherwise low.
 */
static inline bool DIORead(DIOTag_t t);

/* Implementation crud below here */

#define DIO_BASE ( (uintptr_t) GPIOA )

#define DIO_PORT_OFFSET(port) (((uintptr_t) (port)) - DIO_BASE)

#define DIO_MAKE_TAG(port, pin) ((uintptr_t) ((DIO_PORT_OFFSET(port) << 16) | ((uint16_t) (pin))))

#define DIOSHL(a, b) (((uint64_t) (a)) << (b))

#define DIO_MAKE_INITTAG(func, pull, drive, initial, od, altFunc) ( \
		DIOSHL(func, 32) | \
		DIOSHL(pull, 36) | \
		DIOSHL(drive, 40) | \
		DIOSHL(initial, 44) | \
		DIOSHL(od, 45) | \
		DIOSHL(altFunc, 46))

#define GPIOA_DIO(pin_num) DIO_MAKE_TAG(GPIOA, 1<<(pin_num))
#define GPIOB_DIO(pin_num) DIO_MAKE_TAG(GPIOB, 1<<(pin_num))
#define GPIOC_DIO(pin_num) DIO_MAKE_TAG(GPIOC, 1<<(pin_num))
#define GPIOD_DIO(pin_num) DIO_MAKE_TAG(GPIOD, 1<<(pin_num))
#define GPIOE_DIO(pin_num) DIO_MAKE_TAG(GPIOE, 1<<(pin_num))
#define GPIOF_DIO(pin_num) DIO_MAKE_TAG(GPIOF, 1<<(pin_num))

#define INIT_DIO_INPUT(pull) \
	DIO_MAKE_INITTAG(DIO_PIN_INPUT, pull, DIO_DRIVE_WEAK, false, false, 0)
#define INIT_DIO_OUTPUT(drive, initial, od) \
	DIO_MAKE_INITTAG(DIO_PIN_OUTPUT, DIO_PULL_NONE, drive, initial, od, 0)
#define INIT_DIO_ALTFUNC_OUT(pull, drive, od, altFunc) \
	DIO_MAKE_INITTAG(DIO_PIN_ALTFUNC_OUT, pull, drive, false, od, altFunc)
#define INIT_DIO_ALTFUNC_IN(pull, altFunc) \
	DIO_MAKE_INITTAG(DIO_PIN_ALTFUNC_OUT, pull, DIO_DRIVE_WEAK, false, false, altFunc)

#define GET_DIO_PORT(dio) ( (GPIO_TypeDef *) (((dio) >> 16) + DIO_BASE) )

#define GET_DIO_PIN(dio)  ((dio) & 0xffff)
#define GET_DIO_FUNC(dio) (((dio) >> 32) & 0x0f)
#define GET_DIO_PULL(dio) (((dio) >> 36) & 0x0f)
#define GET_DIO_DRIVE(dio) (((dio) >> 40) & 0x0f)
#define GET_DIO_INITIAL(dio) (((dio) >> 44) & 1)
#define GET_DIO_OD(dio) (((dio) >> 45) & 1)
#define GET_DIO_ALTFUNC(dio) (((dio) >> 46) & 0x0f)

#define _DIO_PRELUDE_RET(s) \
	if (t == DIO_NULL) { return (s); } \
	GPIO_TypeDef * gp = GET_DIO_PORT(t); \
	uint16_t pin = GET_DIO_PIN(t);

#define _DIO_PRELUDE \
	if (t == DIO_NULL) { return; } \
	GPIO_TypeDef * gp = GET_DIO_PORT(t); \
	uint16_t pin = GET_DIO_PIN(t);

static inline void DIOHigh(DIOTag_t t)
{
	_DIO_PRELUDE;

	gp->BSRRL = pin;
}

static inline void DIOLow(DIOTag_t t)
{
	_DIO_PRELUDE;

	gp->BSRRH = pin;
}

static inline void DIOWrite(DIOTag_t t, bool high)
{
	if (high) {
		DIOHigh(t);
	} else {
		DIOLow(t);
	}
}

static inline void DIOToggle(DIOTag_t t)
{
	_DIO_PRELUDE;

	DIOWrite(t, ! (gp->ODR & pin) );
}

/* Some of the bitfields here are two bits wide; some are 1 bit wide */

// Uses regs twice, naughty.
#define DIO_SETREGS_FOURWIDE(reglow, reghigh, idx, val) \
	do { \
		int __pos = (idx); \
		if (__pos >= 8) { \
			__pos -= 8; \
			(reghigh) = ((reghigh) & ~(15 << (__pos * 4))) | ( (val) << (__pos * 4)); \
		} else { \
			(reglow) = ((reglow) & ~(15 << (__pos * 4))) | ( (val) << (__pos * 4)); \
		} \
	} while (0)

#define DIO_SETREG_TWOWIDE(reg, idx, val) \
	do { \
		int __pos = (idx); \
		(reg) = ((reg) & ~(3 << (__pos * 2))) | ( (val) << (__pos * 2)); \
	} while (0)

#define DIO_SETREG_ONEWIDE(reg, idx, val) \
	do { \
		int __pos = (idx); \
		(reg) = ((reg) & ~(1 << (__pos))) | ( (val) << __pos); \
	} while (0)
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

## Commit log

2021-09-25 Start monitor code base, derived from dRonin OpenLager
    Principal changes in first commit:
    * Adjust for different clocking/part (STM32F401).
    * Run on top of WeAct bootloader (0x8004000 entry) and remove our own loader
    * Adjust memory map to only use top half of memory, leaving bottom half for student programs.
    * Remove usart, sdio, etc, code: can reimport if we need it again
2021-09-26 Massive set of changes
    * Add SVCall handlers for trivial functionality (toggling LEDs, delays)
    * Add sample machine code
    * Bring in DIO and start on keypad scan code
2021-09-26 Complete most of the matrix scanning code
    Change "rows" and "cols" to be inputs and outputs to avoid confusion if
    I decide to drive it the other way. Add code to notice state changes,
    but there's no notification mechanism yet.
    [monitor.c]
2021-09-27 work on getting this closer to being a complete monitor
    * Add a debugmon handler
    * Adjust to delay about half a per second per instruction
    * Skip instructions in flash
    * Add a blink N times syscall
    * Stub out other LCD related syscalls
    * Add a function called when a keypad key changes state
    [monitor.c]
2021-10-02 Reverse sense of bsrrl/bsrrh.
    [armdio.h]
2021-10-08 add syscall to print number to console
    Also, work towards editing instructions/addresses
2021-10-08 many changes towards making this a good monitor
    - On the other fault handlers, run the debug handler so invalid instructions don't crash us.
    - Improve numeric editing to be nicer
    - Add autoincrement when pressing load successive times
    - Eliminate startup test pattern, give meaningful welcome screen
    - Print flags onto screen
    - Set fault priorities so that tracing is meaningful around syscalls
    - Eliminate a lot of dead code.
    [lcd.c, monitor.c]
2021-10-26 Factoring and cleanup in preparation for completion
    - Eliminate dead Makefile lines relarting to FATFS
    - Add useful setupsh-aliases for make, vim
    - Implement lcd_blit_rows for clearing a portion of the screen, use in
    lcd_move_up
    - Factor string handling utilities and instruction decoding to new
    header, stringutil.h
    - Correct function naming convention (underscores) for many functions
    - Add icon blitting routine
    - Remove dead code that was to skip over interrupt handlers (now this is
    handled with interrupt priority)
    [lcd.c, monitor.c]
2021-10-26 Continued work on monitor & lcd functionality
    - Bounds check LCD draw operations
    - Bounds check character table operations
    - Remove inapplicable comments
    - Move globals closer to the top of monitor.c, add some comments
    - Unify console text drawing functionality, add crude terminal emulation
    - Implement blit dot syscall
    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
2021-10-29 add snake game, and related supporting changes
    - add lcd routine to get the color of a pixel to lower the amount of
    state needed to be checked in snake game to detect collision.
    - move matrix keypad routine to a well-defined matrix scanner
    - add syscalls 0x40, 0x41: stop singlestep, re-enable
    - add secret syscall 0x45: invokes snake when R0 = 'S', R1='N',
    R2='A'.
    [lcd.c, matrix.c, monitor.c]
2021-10-30 Improvements to snake game (and related infra)
    - Make everything in stringutil static so it can be imported multiple
    times, and everything inline so we don't get warnings about unused.
    - Adjust memory map; take away 4k of ram from users so that we don't
    stack overflow in snake.
    - Add comment of instruction sequence to invoke snake
    - Make positions a global, so it's easier to analyze ram use.
    - Draw a red border around the screen.
    - Fix wall test
    - Grow by chunks of 3 instead of 1
    - Show score in hex below screen.
    - Slow down game a LOT.
    [monitor.c]
2021-11-02 Fix various small issues with snake
    - Slow down the game a bit
    - Delay for a small amount at the beginning of the game to help player
    get bearings
    - Protect the border on the screen appropriately
2021-11-02 Improve random number call, console output
    - Correctly handle outputting denary '0'
    - Allow a range to be specified for random numbers (from 0 to r0-1)
    [monitor.c]
2021-11-03 Swap clock phase of SPI going to display module
    [lcd.c]
2021-11-25 Improvements to snake: 4569, erasure, prevent doubling back
    [monitor.c]
2021-11-25 try not to freeze when addr is outside of code ram
    If we fault, and our current address did not start with 0200, we'd
    immediately resume (and fault again).
    Now we only immediately return when we're in a flash address.
2021-11-25 Bring in hardware design
    [MicroTrainer-F_Cu.dxf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]
2021-11-25 Add arm manual and source
2021-11-29 Correct test-for-ram check in debug monitor
    [monitor.c]
2021-11-29 Correct flash command for current hw
2021-11-29 Prevent crashing after attempt to exec invalid addr
    [monitor.c]
2021-11-29 Correct an off-by-one error in snake scaling
    The range of horizontal pixels filled by the LCD driver is from
    startX to endX inclusive, so we need to subtract 1 from the end
    coordinate to scale properly.
2023-12-16 Fix LOAD segment with RWX permissions error
    Newer toolchain complains about loaded segments with RWX permissions.
    Our linker script was actually correct. But we had a couple of
    erroneous const void * (pointer to constant void) instead of void *
    const (const pointer to void) in the interrupt vector table. As a
    result, the vectors were marked writable. They were adjacent to code
    and text, so the whole thing was rwx as a result.
    Now, it's properly r-x.
2023-12-17 Staging in preparation of review and ordering
    [MicroTrainer.kicad_pcb, MicroTrainer.kicad_sch]
2023-12-17 add cherry switch 3d step model
    [asm_mx_asm_PCB.stp]
2023-12-17 Further checkins in preparation for review
    [MicroTrainer.sch]
2023-12-17 MicroTrainer Rev B
    [MicroTrainer.kicad_pcb]
2023-12-17 Gerbers, as ordering
    [MicroTrainer-BOM.csv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]
2023-12-18 Update to reflect we're using STM32F412
    [MicroTrainer-BOM.csv, MicroTrainer.kicad_sch]
2023-12-18 Adjust memory map for stm32f412
    All of this is optional, but having more RAM is nice.
    Give students up to 32k; grow to use remaining 224k
2023-12-18 Adjust LCD driver to use DMA.
2023-12-28 Toggle auxiliary LED every 1024 keyboard scans
    For bringup, but it's not a bad troubleshooting thing in general.
2023-12-28 Add errata for revision B.
    So far: the LED is way too bright.
2023-12-29 Fix key mapping -- rows were reversed
    [matrix.c]
2023-12-29 Correct LCD DMA implementation
    [lcd.c, monitor.c]
2023-12-30 Add new lcd_is_ready call to detect when DMA done
    This allows the main loop to scan the keyboard more of the time,
    rather than entering LCD code that is waiting for a refresh to
    complete
2023-12-30 Adjust snake to leave trace of a grid behind
2023-12-30 Correct clock rate comments, document more
    [monitor.c]
2023-12-30 Highlight current instruction
2024-01-01 Corrections to make instruction view work
    - Add spaces before immediates
    - use proper color values
    - fix edge cases with numbers in small font
    [lcd.c, monitor.c]
2024-01-01 Small corrections to screen blitting for decimals, etc
    [monitor.c]
2024-01-01 Disable keyboard matrix LED
    It was useful for bringup, but now let's free up the LED for
    students.
2024-01-01 Moved all files in shared dir to src
    This is legacy from a prior project where there were "shared" files
    used by a bootloader.
    This has pretty definitively moved to using the STM32 system loader
    for flashing, so that won't be used here. Therefore, let's simplify
    the path hierarchy.
    [led.c]
2024-01-01 Correct LED for new hardware
    [monitor.c]
2024-01-01 lcd: Don't enable display until first frame blitted
    This slightly speeds up startup and avoids an annoying black flash.
    [lcd.c]
2024-01-01 Don't draw the partial first frame during startup
2024-01-02 Improvements to disassembling
    - Output hex instruction correctly
    - More clearly highlight current instruction
    [monitor.c]
2024-01-03 Attempt to drive 30MHz clock out PA6
    (pin 22).
    This is for diagnostic purposes only, but the fraction of a milliampere
    that this uses is irrelevant, so always enable it.
2024-01-04 Fix a small piece of errata with snake
    We ended up skipping the "next" instruction after snake returned. Fix
    that.
    [monitor.c]
2024-02-15 make save slot 2 work
2024-02-28 Correct decoding of instruction destinations
    [thumbdisasm.h]
2024-04-25 Update arm manual with revisions for 2024
2024-05-04 Update README to match current state of manual, etc.
2024-05-19 add a help key (ADDR+CLR) to see key shortcuts
    [monitor.c]
2024-05-19 Add break missing from switch statement
    [monitor.c]
2024-05-19 improve branch calculator and fix some bugs
    While this is still as-yet untested, I noticed that the subtraction
    was in the incorrect order (was start - target instead of the
    opposite) and that I had failed to account for the way the
    instruction pointer is already incremented at the time of the
    branch.
    While we're at it, let's make sure the source address is valid,
    and construct a branch instruction ready for the user to hit
    store.
    [monitor.c]
2024-05-20 console: new ver of hex printing without leading 0
    Allows brief output in the branch calculator
2024-05-20 make the branch calculator routine work
    - calculate offsets correctly
    - print offsets without tons of leading zeroes
    [monitor.c]
2024-05-20 branch helper: don't let our idea of 'load' get stuck
    Because we go to a different keyboard helper when reading input,
    the release of the 'load' key was getting lost by the main monitor,
    which was confounding all subsequent efforts to interact.
    [monitor.c]
2024-05-20 Correct branch in snake example to go back to begin
    [monitor.c]
2024-05-21 improvements to branch calculator
    Correctly handle negative branches. Bound limits properly.
    Wait a small amount of time for 'b' key to debounce before going to
    different input routine.
    [monitor.c]
2024-05-21 Correct help -- hold "LOAD" not "ADDR"
    [monitor.c]
2024-05-22 Add somewhat clunky code to validate a save is desired
    Students have been overwriting their code accidentally. I have
    implemented logic to confirm loads and saves in the following
    circumstances:
    - Loads: If there has been any 'stores', it will decline to load
    without confirmation.
    - Saves: If the last successful save or load operation since boot
    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

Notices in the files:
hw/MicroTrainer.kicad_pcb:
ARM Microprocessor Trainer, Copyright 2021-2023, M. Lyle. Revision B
